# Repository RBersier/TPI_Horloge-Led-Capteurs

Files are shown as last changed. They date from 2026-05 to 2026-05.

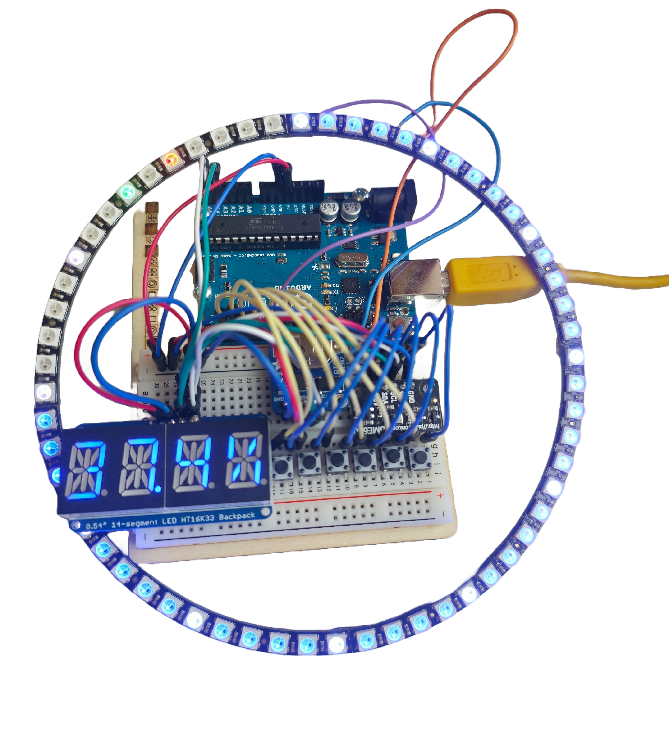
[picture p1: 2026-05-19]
Image/Materiel/Photo_horloge_final.png

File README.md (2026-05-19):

# TPI_Horloge-Led-Capteurs

## Résumé du projet
Ce projet est une horloge murale basée sur Arduino qui combine:
- un affichage analogique de l’heure sur un anneau NeoPixel 60 LEDs,
- un affichage alphanumérique 4x14 segments pour les données environnementales,
- une mesure de l’environnement (température, humidité, pression, gaz/eCO2 estimé),
- un système d’alerte visuelle qualité d’air.

Le système est piloté par un RTC DS1307 pour garder l’heure, et par des boutons physiques pour la configuration et l’utilisation quotidienne.

## Manuel d’installation (depuis zéro)
### 1) Prérequis matériel
- 1x Arduino Uno Rev3
- 1x BME680 (I2C)
- 1x RTC DS1307 (I2C) + pile bouton
- 1x afficheur Adafruit 4x14 segments HT16K33 (I2C)
- 4x quarts NeoPixel 60 (assemblés en 1 ring 60 LEDs) ou 1 anneau équivalent WS2812B
- 6x boutons poussoirs (D2, D3, D4, D5, D7, D8)
- Câbles Dupont, breadboard (ou soudure finale)
- Câble USB A/B pour Arduino Uno

### 2) Prérequis logiciel
- Installer [VS Code](https://code.visualstudio.com/) ou [CLion](https://www.jetbrains.com/clion/)
- Installer l’extension **PlatformIO IDE**
- Installer les drivers Arduino Uno si nécessaire (Windows)

### 3) Récupérer le projet
1. Télécharger/Cloner le dépôt dans un dossier local.
2. Ouvrir le dossier du projet dans VS Code.
3. Ouvrir le sous-dossier `Code` comme projet PlatformIO.

### 4) Vérifier la configuration PlatformIO
Le fichier `Code/platformio.ini` contient les dépendances nécessaires (`lib_deps`), notamment:
- RTClib
- Adafruit BME680 Library
- Adafruit GFX Library
- Adafruit LED Backpack Library
- Adafruit NeoPixel

### 5) Câblage minimal
- **I2C commun** (SDA/SCL) pour DS1307, BME680, HT16K33
- **Ring NeoPixel data** sur `D6`
- **Boutons**:
  - `D2` Menu/Valider
  - `D3` Up
  - `D4` Down
  - `D5` Changer affichage
  - `D7` Luminosité
  - `D8` Désactiver alerte
- Masse (GND) commune sur tous les modules

### 6) Compiler et flasher
1. Brancher l’Arduino en USB.
2. Dans PlatformIO, lancer **Build**.
3. Sélectionner le port série correct (ex: `COM8`).
4. Lancer **Upload**.
5. (Optionnel) Ouvrir le moniteur série à `9600` bauds.

> Si le port ne fonctionne pas: lancer `pio device list` et mettre à jour `monitor_port` dans `Code/platformio.ini`.

### 7) Premier démarrage
- L’afficheur montre le cycle des infos (`eCO2`, `TEMP`, `HUMD`, `ATMO`, `DATE`).
- Le ring affiche l’heure.
- Si `RTC` ou `BME680` est absent, le système l’indique sur l’afficheur.

## Manuel d’utilisation
### A) Rôle de chaque composant
#### Arduino Uno Rev3
- Rôle: microcontrôleur principal.
- Données: centralise toutes les entrées/sorties et exécute la logique.

#### RTC DS1307
- Rôle: conserver l’heure/date même hors tension (avec pile).
- Données fournies: heure, minute, seconde, jour, mois, année.

#### BME680
- Rôle: mesure environnementale.
- Données fournies:
  - Température (`Traw`, `Tcomp` affichée)
  - Humidité relative (%)
  - Pression atmosphérique (hPa)
  - Résistance gaz (Ohm), convertie en `eCO2/PPM~` estimé

#### HT16K33 4x14 segments
- Rôle: affichage texte/valeurs.
- Données affichées:
  - `eCO2` (estimation ppm)
  - `TEMP`
  - `HUMD`
  - `ATMO`
  - `DATE`

#### Anneau NeoPixel 60 LEDs
- Rôle: horloge analogique + alerte visuelle.
- Affichage:
  - Heure en rouge
  - Minute en vert
  - Seconde en bleu cumulatif
  - Couleurs de mélange selon superposition
- Alerte:
  - Ring rouge clignotant rapide si qualité d’air dégradée

#### 6 boutons poussoirs
- Rôle: interface utilisateur locale (navigation/configuration/alertes).

### B) Fonction de chaque bouton
#### D2 — Menu / Valider
- Entre en mode configuration de l’heure/date.
- Cycle de validation des champs:
  - Jour -> Mois -> Heure -> Minute -> Seconde -> retour mode normal.

#### D3 — Up
- Incrémente le champ actif en mode configuration.

#### D4 — Down
- Décrémente le champ actif en mode configuration.

#### D5 — Changer affichage
- Passe manuellement à l’information suivante sur l’afficheur.
- Redémarre le timer de rotation automatique.

#### D7 — Luminosité
- Change la luminosité du ring par paliers:
  - 100% -> 75% -> 50% -> 25% -> 100% ...

#### D8 — Désactiver alerte
- Coupe temporairement l’alerte visuelle rouge.
- L’alerte peut se réarmer automatiquement si la qualité d’air repasse sous seuil puis remonte.

### C) Comportement général
- Rotation automatique des données sur le 14-segments (avec TAG avant valeur).
- Horloge analogique continue sur le ring.
- Alerte visuelle prioritaire sur le ring quand seuil qualité d’air dépassé.
- Réglage date/heure possible sans PC via boutons.

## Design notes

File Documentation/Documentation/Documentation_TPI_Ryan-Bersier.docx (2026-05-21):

TPI : Horloge à LED avec Capteur

Documentation du projet

Figure 1 Photo illustrant l’horloge du projet finie et assemblée en fonctionnement

Chef de projet

Raphael FAVRE

Enseignants aux CPNV en informatique

Experts

Süleyman CERAN

Administrateur Systèmes à UNIL

Alexandre GRAF

CEO de Omicron Web Services SA

Ryan Bersier

SI-C4a – CPNV - 2026

# Table des matières

# 1 Analyse préliminaire

## 1.1 Introduction

Ce projet s'inscrit dans le cadre du Travail de Projet Individuel (TPI) de la formation d'Informaticien CFC (Ordonnance 2021), orientation Exploitation et infrastructure, réalisé au CPNV à Sainte-Croix. Il porte sur la conception et la réalisation d'une horloge murale à LED avec capteurs environnementaux, pilotée par une carte Arduino.

L'idée de départ part d'un constat concret : de nombreuses salles de classe du CPNV sont équipées de petits boîtiers mesurant le taux de CO₂ dans l'air, afin de surveiller la qualité de l'environnement. Ces appareils effectuent leur travail, mais ils souffrent d'un défaut important : ils n'émettent aucune alerte visuelle ou sonore lorsque le taux devient problématique. Résultat, les personnes présentes dans la salle doivent penser à regarder l'appareil régulièrement pour savoir si l'air est encore acceptable ce qui, en pratique, n'arrive pas toujours.

Ce projet vise à pallier ce manque en proposant un appareil qui combine deux fonctions en une : d'un côté, une horloge murale affichant l'heure en temps réel grâce à un anneau de LED NeoPixel animé, et de l'autre, un système de surveillance environnementale affichant en continu la température, l'humidité, la pression atmosphérique et la qualité de l'air (COV) sur un écran alphanumérique. Dès que la qualité de l'air se dégrade, l'anneau LED change de comportement pour émettre une alerte visuelle immédiate et impossible à ignorer.

L'appareil repose sur plusieurs composants matériels mis à disposition : une carte Arduino REV3, quatre anneaux Adafruit NeoPixel formant un cercle de 60 LED, un capteur environnemental BME680, un module d'horloge temps réel RTC DS1307 garantissant la précision de l'heure même en cas de coupure de courant, un affichage Adafruit 4×14 segments, ainsi que six boutons poussoirs permettant à l'utilisateur de régler l'heure, d'ajuster la luminosité et de changer le mode d'affichage.

Ce projet représente une réelle opportunité d'apprentissage dans le domaine des systèmes embarqués, en combinant des aspects de programmation bas niveau, de câblage électronique, de gestion de capteurs et de conception d'une interface utilisateur simple mais efficace. Il s'appuie sur des compétences acquises notamment dans les modules INI-03, MA-20, 319, ainsi que sur le projet Système Embarqué en Arduino déjà réalisé en formation.

Aucun travail préliminaire spécifique à ce projet n'avait été effectué avant le début du TPI. L'intégralité de la conception, du câblage et du développement est réalisée durant la période du 23 avril au 21 mai 2026, dans les locaux du CPNV.

## 1.2 Objectifs

### 1.2.1 Objectifs du projet

Les objectifs suivants ont été définis sur la base du cahier des charges. Chacun d'eux devra pouvoir être vérifié et validé à la fin du projet, que ce soit par démonstration directe, par les résultats des tests ou par la lecture du rapport.

#### 1.2.1.1 Objectif 1 Affichage de l'heure en temps réel

L'horloge doit afficher l'heure courante (heures, minutes, secondes) de manière fluide et lisible sur l'anneau de 60 LED NeoPixel, composé de quatre quarts d'anneau assemblés. L'affichage doit rester correct même après une coupure de courant, grâce au module RTC DS1307.

#### 1.2.1.2 Objectif 2 Mesure et affichage des données environnementales

Le système doit lire en continu les données du capteur BME680 température, humidité, pression atmosphérique et qualité de l'air (COV) et les afficher de manière alternée et claire sur l'écran alphanumérique 4×14 segments.

#### 1.2.1.3 Objectif 3 Alerte visuelle en cas de mauvaise qualité de l'air

Lorsque le niveau de COV dépasse un seuil défini, l'anneau de LED doit réagir visuellement de façon distincte (changement de couleur, clignotement) afin d'alerter immédiatement les personnes présentes dans la salle, sans qu'elles aient besoin de regarder l'écran.

#### 1.2.1.4 Objectif 4 Interaction utilisateur via les boutons poussoirs

Les six boutons poussoirs doivent permettre à l'utilisateur de régler manuellement l'heure, de changer le mode d'affichage de l'écran alphanumérique et d'ajuster la luminosité des LED, avec une gestion correcte du rebond (debounce).

#### 1.2.1.5 Objectif 5 Qualité et maintenabilité du code

Le code Arduino doit être structuré en modules distincts (gestion RTC, NeoPixel, BME680, HT16K33, boutons), commenté et versionné sur un dépôt GitHub mis à jour quotidiennement.

#### 1.2.1.6 Objectif 6 Documentation complète

Un rapport de projet complet, un journal de travail, une procédure d'installation et de mise en service, ainsi qu'une archive du projet doit être livrés dans les délais définis par le cahier des charges.

### 1.2.2 Objectif personnel

#### 1.2.2.1 Me dépasser sur un projet complet

C'est la première fois que je gère un projet de cette ampleur seul, du début à la fin. Je veux prouver surtout à moi-même que j'en suis capable.

#### 1.2.2.2 Progresser autant sur le plan technique qu'humain

Gérer mon stress, respecter mes délais, prendre des décisions seul quand ça coince ce sont des compétences que je veux autant développer que la programmation ou le câblage.

#### 1.2.2.3 Apprendre à résoudre des problèmes inconnus

Ce projet va forcément me mettre face à des situations nouvelles. Mon objectif est d'apprendre à chercher, tester et trouver par moi-même.

#### 1.2.2.4 Mieux gérer mon temps et ma planification

J'ai tendance à sous-estimer certaines tâches. Ce TPI est une occasion concrète d'apprendre à planifier de façon réaliste et à ajuster quand les choses ne se passent pas comme prévu.

#### 1.2.2.5 Comprendre et maîtriser le protocole I²C

Je veux vraiment comprendre comment plusieurs composants cohabitent sur le même bus, comment détecter les conflits d'adresses et comment diagnostiquer un problème de communication pas juste utiliser des bibliothèques sans savoir ce qu'il se passe dessous.

#### 1.2.2.6 Écrire un code structuré et modulaire

Je veux organiser mon code en modules séparés et indépendants, avec des fonctions claires et des commentaires utiles comme le ferait un développeur professionnel sur un vrai projet embarqué.

#### 1.2.2.7 Maîtriser la brasure et le câblage électronique

C'est la partie qui m'inquiète le plus et donc celle où je veux le plus progresser. Je veux sortir de ce projet à l'aise avec le fer à souder et capable de monter un circuit proprement.

#### 1.2.2.8 Créer quelque chose de concret et utile

Ce qui me motive profondément c'est de produire un objet réel qui fonctionne et qui a du sens pas juste un exercice scolaire qu'on oublie le lendemain.

#### 1.2.2.9 Apprendre à utiliser Git de façon rigoureuse

Commiter régulièrement, écrire des messages de commit clairs, garder un historique propre je veux prendre de vraies bonnes habitudes de versioning que je garderai toute ma carrière.

#### 1.2.2.10 Apprendre à documenter mon travail au fil de l'eau

Plutôt que de tout rédiger en catastrophe à la fin, je veux prendre l'habitude d'écrire au fur et à mesure une discipline que je veux garder bien après ce TPI.

#### 1.2.2.11 Comprendre la gestion du temps réel sans système d'exploitation

Gérer plusieurs tâches simultanées sur Arduino sans bloquer l'exécution avec des delay() est un vrai défi. Je veux maîtriser la logique non-bloquante avec millis() et comprendre comment prioriser les tâches sur un seul cœur.

#### 1.2.2.12 Gagner en autonomie et en confiance

Chaque problème résolu seul, chaque décision technique assumée je veux que ce projet me rende plus confiant dans mes capacités pour la suite de ma carrière.

#### 1.2.2.13 Soigner les détails jusqu'au bout

Pas seulement que ça fonctionne, mais que le câblage soit propre, le code lisible et le rapport honnête. Je veux pouvoir regarder le résultat final et me dire que j'ai vraiment donné le meilleur de moi-même.

#### 1.2.2.14 Profiter de cette expérience unique

Un TPI ne se fait qu'une fois. Au-delà des notes et des évaluations, je veux vivre ce projet comme une vraie expérience professionnelle dont je me souviendrai.

## 1.3 Analyse des besoins matériels et logiciels

### 1.3.1 Besoins matériels

#### 1.3.1.1 Carte Arduino REV3

La carte Arduino REV3 constitue le cœur du projet. C'est elle qui orchestre l'ensemble du système : elle lit les données des capteurs, calcule l'affichage de l'heure, pilote les LED et réagit aux actions de l'utilisateur sur les boutons. Elle communique avec les différents composants via les protocoles I²C et les broches numériques/analogiques disponibles.

Figure 2 Photo de l’Arduino et de sa Breadboard prise à la main

#### 1.3.1.2 Anneaux Adafruit NeoPixel 1/4 60 LED au total x4

Ces quatre quarts d'anneau, assemblés pour former un cercle complet de 60 LED RGB, constituent l'affichage principal de l'horloge. Chaque LED est adressable individuellement, ce qui permet de créer des animations fluides pour représenter les heures, les minutes et les secondes, mais aussi de changer l'apparence de l'anneau en cas d'alerte environnementale. Leur pilotage se fait via une seule broche de données et la bibliothèque Adafruit NeoPixel.

Figure 3 Photo des 4 quart de l’anneau de LED avec le dernier quart retourné pour bien pouvoir voir les connexions

#### 1.3.1.3 Capteur environnemental BME680

Ce capteur multifonction est capable de mesurer simultanément la température ambiante, l'humidité relative, la pression atmosphérique et la qualité de l'air via un indice de composés organiques volatils (COV). Il communique avec l'Arduino via le bus I²C et constitue la source de toutes les données environnementales affichées et surveillées par le système.

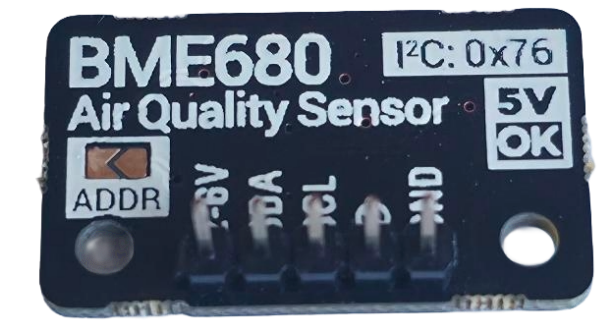
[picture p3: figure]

Figure 4 Photo du capteur environnemental

#### 1.3.1.4 Module horloge temps réel RTC DS1307

Le module RTC DS1307 est une horloge temps réel qui maintient l'heure exacte de manière autonome, même en cas de coupure de courant, grâce à une pile de sauvegarde intégrée. Il communique également via I²C et garantit que l'horloge affichée reste toujours précise, sans dérive, tout au long de l'utilisation de l'appareil.

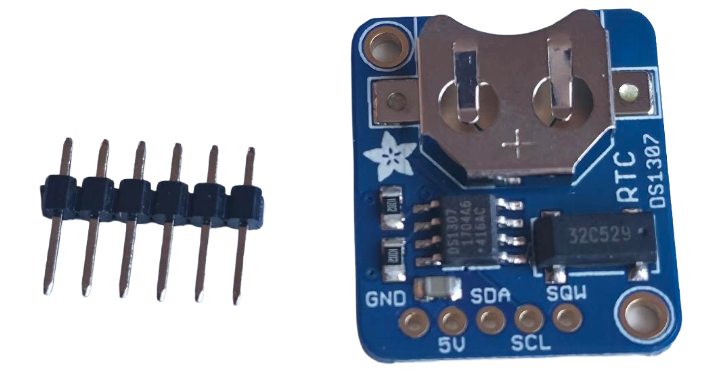
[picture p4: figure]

Figure 5 Photo du Module horloge pour garder la date et l’heure en mémoire

#### 1.3.1.5 Affichage Adafruit 4×14 segments alphanumérique HT16K33

Cet affichage alphanumérique, basé sur le contrôleur HT16K33 et pilotable en I²C, permet d'afficher du texte et des chiffres. Il est utilisé pour présenter en alternance les différentes mesures environnementales (température, humidité, pression, qualité de l'air) de façon lisible et compacte.

Figure 6 Photo de l’affichage 14 segment pas encore assembler

#### 1.3.1.6 Boutons poussoirs x6

Les six boutons permettent à l'utilisateur d'interagir directement avec le système. Ils servent à régler manuellement l'heure, à changer le mode d'affichage de l'écran alphanumérique, et à ajuster la luminosité des LED. Une gestion du rebond (debounce) devra être implémentée pour garantir un comportement fiable à chaque pression.

Figure 7 Photo des 6 boutons pour le projet

#### 1.3.1.7 Poste de brasure et composants électroniques associés

Le projet nécessite un travail de câblage et de brasure pour assembler les différents composants de manière solide et durable. Des résistances, condensateurs, fils de connexion et une breadboard sont mis à disposition pour réaliser le montage électronique.

#### 1.3.1.8 Cable USB-B 2.0 vers USB-A 2.0

Ce câble est indispensable pour connecter la carte Arduino à l'ordinateur. Il sert à la fois à alimenter la carte durant le développement et à téléverser le programme compilé depuis CLion/PlatformIO directement sur le microcontrôleur. Sans ce câble, aucun transfert de code n'est possible entre l'environnement de développement et la carte.

Figure 8 Photo câble fourni USB-a vers USB-b

#### 1.3.1.9 Cable de connexion pin a pin mâle

Ces fils de connexion, aussi appelés jumpers, sont utilisés pour relier les différents composants électroniques entre eux sur la breadboard et vers les broches de l'Arduino. Ils permettent de créer le câblage de manière propre, flexible et modifiable sans brasure, ce qui est particulièrement utile durant la phase de prototypage et de tests.

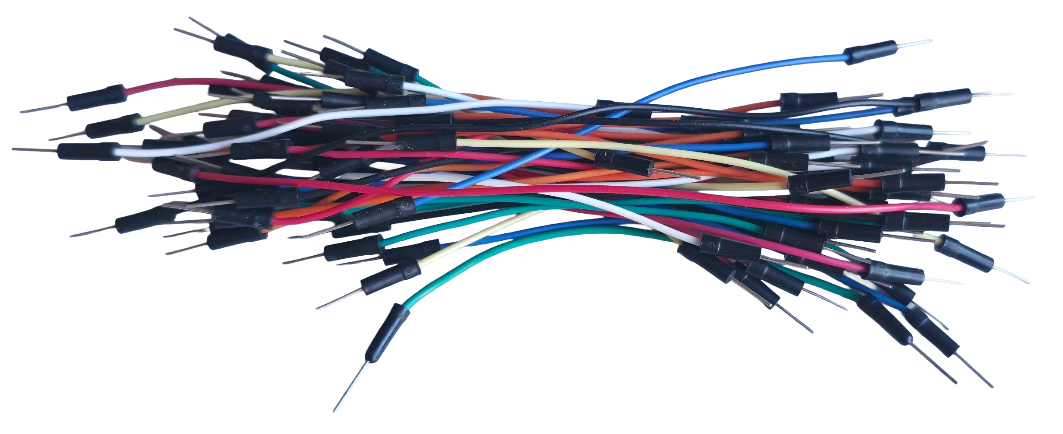
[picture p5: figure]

Figure 9 photo de câble de connexion pin a pin mâle en pagaille

#### 1.3.1.10 Ordinateur du CPNV

L'ordinateur mis à disposition par le CPNV constitue la station de travail principale pour l'ensemble du projet. Il héberge l'environnement de développement CLion avec PlatformIO, les outils de versioning Git, la suite Microsoft Office pour la rédaction des documents, ainsi que tous les fichiers du projet. C'est depuis cet ordinateur que le code est écrit, compilé et téléversé sur la carte Arduino tout au long de la période de réalisation.

Figure 10 PC fourni par le CPNV OptiPlex 7000 DELL

### 1.3.2 Besoins logiciels

#### 1.3.2.1 CLion avec l'extension PlatformIO

Pour le développement du code embarqué, j'ai choisi d'utiliser CLion, l'IDE de JetBrains, couplé à l'extension PlatformIO. Ce choix s'écarte de l'IDE Arduino classique, mais offre des avantages significatifs pour un projet de cette envergure : un éditeur de code puissant avec autocomplétions intelligente, une gestion propre des bibliothèques via PlatformIO, un débogage facilité, et une meilleure organisation du projet en fichiers et modules distincts. PlatformIO prend en charge nativement les cartes Arduino et gère automatiquement les dépendances, ce qui simplifie l'intégration des bibliothèques tierces.

Figure 11 Image du logo de CLion et du logo de son plugin PlatformIO

#### 1.3.2.2 Bibliothèque Adafruit NeoPixel

Cette bibliothèque officielle d'Adafruit est indispensable pour piloter les anneaux LED. Elle permet de contrôler chaque LED individuellement, de définir des couleurs en RGB et de créer des animations. Elle sera intégrée au projet via le gestionnaire de bibliothèques de PlatformIO.

#### 1.3.2.3 Bibliothèque Adafruit BME680

La bibliothèque Adafruit pour le capteur BME680 fournit une interface simple et fiable pour lire toutes les données du capteur (température, humidité, pression, COV) sans avoir à gérer manuellement les registres I²C de bas niveau.

#### 1.3.2.4 Bibliothèque RTClib

La bibliothèque RTClib, développée par Adafruit, facilite la communication avec le module RTC DS1307. Elle permet de lire et d'écrire l'heure courante de façon claire, et d'effectuer des conversions de dates et d'heures sans complexité inutile.

#### 1.3.2.5 Bibliothèque Adafruit LED Backpack / GFX

Ces bibliothèques permettent de piloter l'affichage alphanumérique HT16K33 via I²C. Elles offrent des fonctions simples pour écrire du texte ou des valeurs numériques sur les segments, ce qui rend l'affichage des données environnementales straight forward à implémenter.

#### 1.3.2.6 Git et GitHub

L'ensemble du code source sera versionné avec Git et publié sur un dépôt GitHub mis à jour quotidiennement, conformément aux exigences du cahier des charges. Cela garantit un suivi précis de l'évolution du projet, permet de revenir à une version antérieure en cas de problème, et constitue une archive complète du travail effectué.

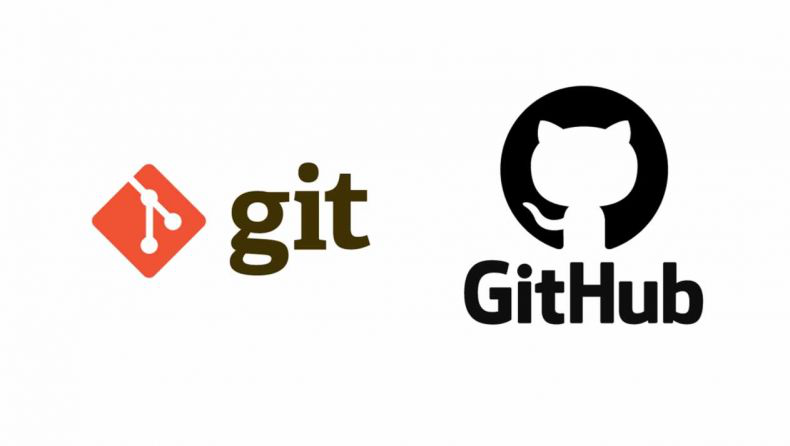
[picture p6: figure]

Figure 12 Image du logo de git et de GitHub

#### 1.3.2.7 Suite Microsoft Office

Microsoft Word sera utilisé pour la rédaction du rapport de projet et du journal de travail, conformément aux livrables attendus. Microsoft PowerPoint pourra être utilisé pour préparer la présentation orale prévue les 2 ou 3 juin 2026.

Figure 13 Image du logo de Microsoft Office

#### 1.3.2.8 Draw.io

draw.io sera utilisé pour la conception des diagrammes de flux du projet. Cet outil permettra de modéliser de manière claire et structurée les différents processus, en facilitant la compréhension globale du fonctionnement du système ainsi que la communication technique dans la documentation.

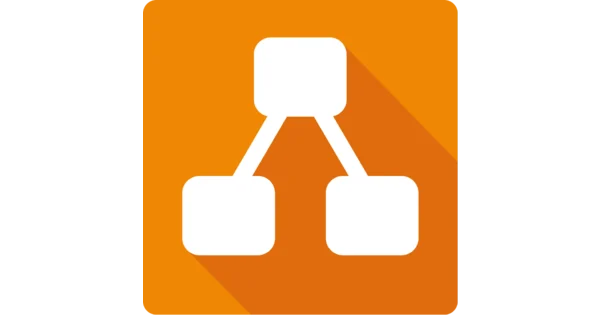
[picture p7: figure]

Figure 14 Image du logo de Draw.io

#### 1.3.2.9 Davinci Resolve

DaVinci Resolve sera utilisé pour le montage de la vidéo de démonstration du projet. Il permettra d’assembler les séquences capturées, d’effectuer les éventuels ajustements audio et visuels, ainsi que d’assurer un rendu final cohérent et professionnel conforme aux exigences de présentation.

Figure 15 Image du logo de Davinci Resolve

## 1.4 Analyse des risques

### 1.4.1 Risque 1

Erreur de câblage ou de brasure

Niveau de risque : Élevé

C'est le risque qui m'inquiète le plus dans ce projet. Le montage implique de nombreux composants reliés entre eux via des câbles, des broches et des points de brasure. Une erreur de câblage comme inverser l'alimentation et la masse (GND/VCC) ou une mauvaise brasure comme un faux contact ou un court-circuit peut endommager irrémédiablement un composant, voire la carte Arduino elle-même.

Mesures préventives :

Avant chaque branchement, je vérifierai systématiquement le schéma de câblage. Je procéderai composant par composant, en testant le bon fonctionnement de chacun avant de passer au suivant. Pour la brasure, je m'assurerai que les joints sont propres, brillants et bien formés, et j'utiliserai un multimètre pour vérifier la continuité électrique et l'absence de court-circuit avant toute mise sous tension.

### 1.4.2 Risque 2

Composant défectueux ou endommagé

Niveau de risque : Moyen

Malgré toutes les précautions prises, un composant peut s'avérer défectueux dès le départ ou être endommagé lors du montage (surchauffe à la brasure, électricité statique, mauvaise manipulation). Si un module clé comme le BME680 ou le RTC ne fonctionne pas, cela peut bloquer une partie importante du développement.

Mesures préventives :

Je testerai chaque composant individuellement dès son branchement, à l'aide de programmes de test simples, avant de les intégrer dans le projet global. En cas de panne avérée, j'en informerai immédiatement mon chef de projet afin d'obtenir un composant de remplacement dans les meilleurs délais.

### 1.4.3 Risque 3

Conflit ou incompatibilité entre les bibliothèques

Niveau de risque : Moyen

Le projet utilise plusieurs bibliothèques tierces simultanément : Adafruit NeoPixel, Adafruit BME680, RTClib et Adafruit LED Backpack. Il est possible que certaines versions de ces bibliothèques entrent en conflit, consomment trop de mémoire RAM ou Flash sur l'Arduino, ou provoquent des comportements inattendus lorsqu'elles sont utilisées ensemble.

Mesures préventives :

J'intégrerai les bibliothèques progressivement, en testant la compatibilité à chaque ajout. Je consulterai la documentation officielle d'Adafruit et les issues GitHub des bibliothèques concernées pour m'assurer d'utiliser des versions stables et compatibles. En cas de problème de mémoire, j'optimiserai le code en réduisant l'utilisation des variables globales et en privilégiant les types de données les plus légers.

### 1.4.4 Risque 4

Dépassement du budget temps

Niveau de risque : Moyen

Avec 90 heures disponibles et un projet qui touche à la fois au matériel et au logiciel, le risque de prendre du retard est réel. Certaines tâches peuvent s'avérer plus longues que prévu notamment le débogage, l'intégration des modules ou la rédaction du rapport et empiéter sur les étapes suivantes.

Mesures préventives :

Je suivrai rigoureusement ma planification initiale et mettrai à jour mon journal de travail quotidiennement pour détecter tout écart rapidement. Si une tâche prend trop de temps, je l'évaluerai et déciderai si je peux la simplifier ou la reporter, en priorisant toujours les fonctionnalités essentielles (affichage de l'heure, lecture des capteurs) avant les fonctionnalités secondaires (animations, modes d'affichage avancés).

### 1.4.5 Risque 5

Problème de communication I²C entre les composants

Niveau de risque : Moyen

Trois composants du projet (BME680, RTC DS1307 et HT16K33) communiquent tous via le bus I²C. Si deux composants partagent la même adresse I²C ou si le bus est mal configuré, les communications peuvent échouer ou se mélanger, rendant les données illisibles.

Mesures préventives :

Je vérifierai en amont les adresses I²C de chaque composant et m'assurerai qu'elles sont toutes différentes. J'utiliserai un scanner I²C (programme Arduino simple) pour détecter tous les appareils connectés sur le bus et confirmer qu'ils sont bien reconnus avant d'aller plus loin dans le développement.

### 1.4.6 Risque 6

Perte de données ou corruption du code source

Niveau de risque : Faible

Une panne informatique, une fausse manipulation ou un problème de synchronisation pourrait entraîner la perte d'une partie du code ou des documents rédigés, avec un impact potentiellement important sur l'avancement du projet.

Mesures préventives :

Le code sera versionné et poussé sur GitHub quotidiennement, conformément aux exigences du cahier des charges. Les documents seront sauvegardés régulièrement sur le réseau du CPNV. Ces deux pratiques combinées réduisent ce risque à un niveau très faible.

### 1.4.7 Risque 7

Difficultés avec l'environnement CLion / PlatformIO

Niveau de risque : Faible

CLion couplé à PlatformIO est un environnement plus avancé que l'IDE Arduino standard. Une configuration incorrecte, un problème de détection du port série ou une mise à jour inattendue pourrait ralentir le démarrage du développement.

Mesures préventives :

Je consacrerai le temps nécessaire à la mise en place et à la vérification de l'environnement de développement dès le premier jour, avant toute autre tâche de programmation. Si des difficultés persistantes apparaissent, je pourrai me rabattre temporairement sur l'IDE Arduino classique pour ne pas bloquer l'avancement, puis revenir à CLion une fois le problème résolu.

## 1.5 Planification initiale

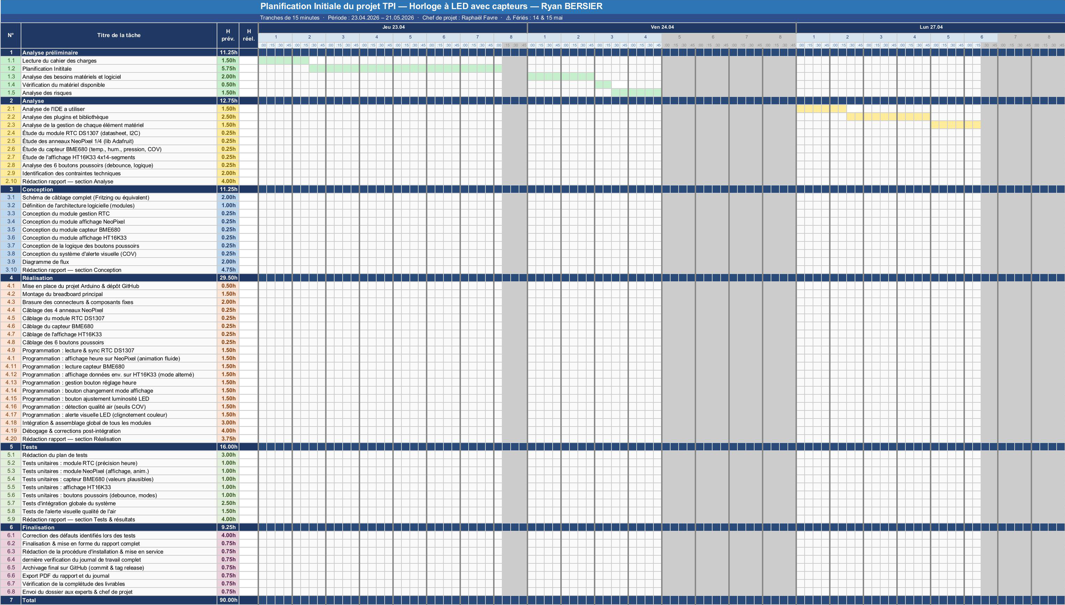
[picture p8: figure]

Figure 16 planning initial partie 1

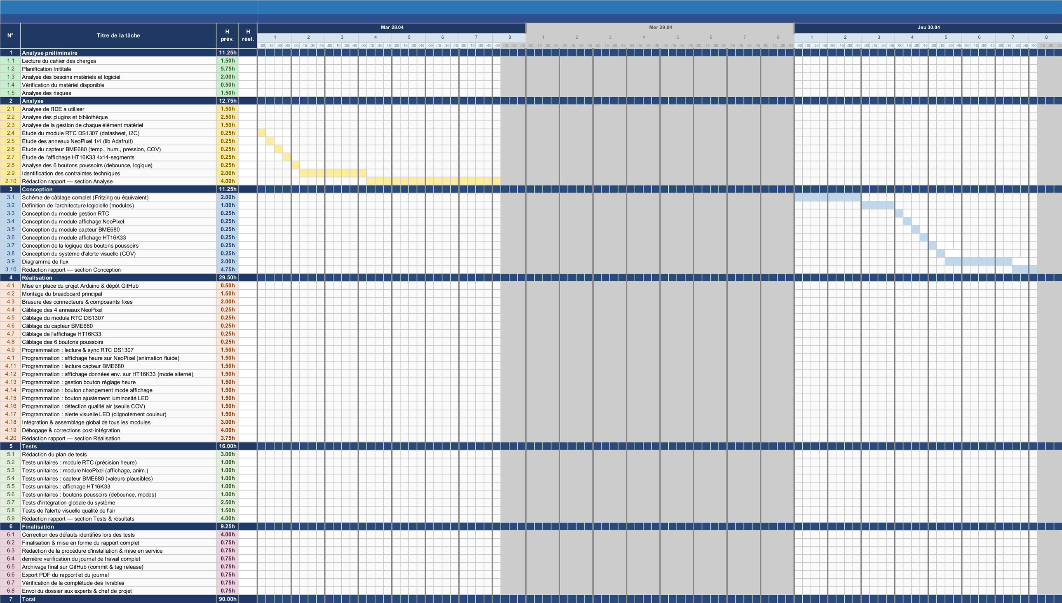
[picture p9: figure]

Figure 17 planning initial partie 2

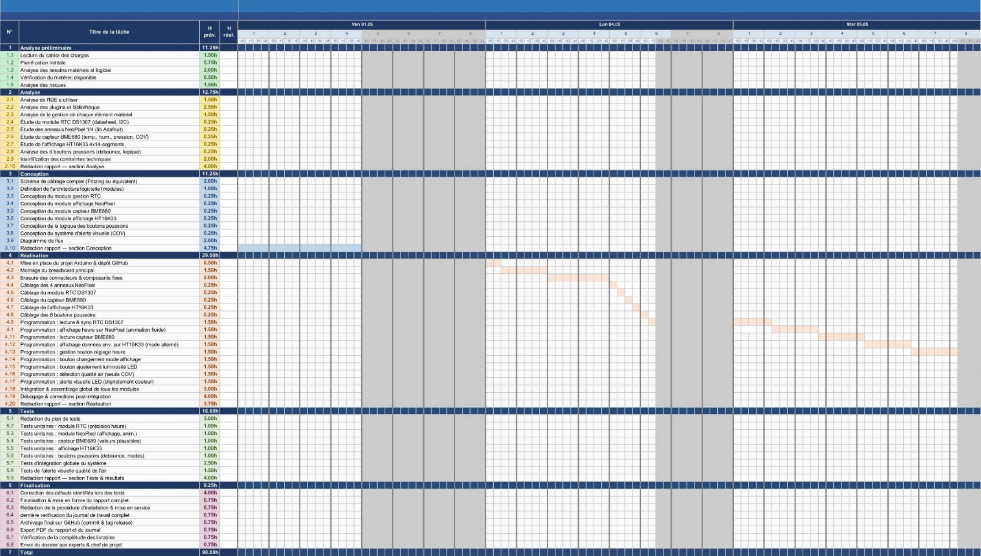
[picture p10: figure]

Figure 18 planning initial partie 3

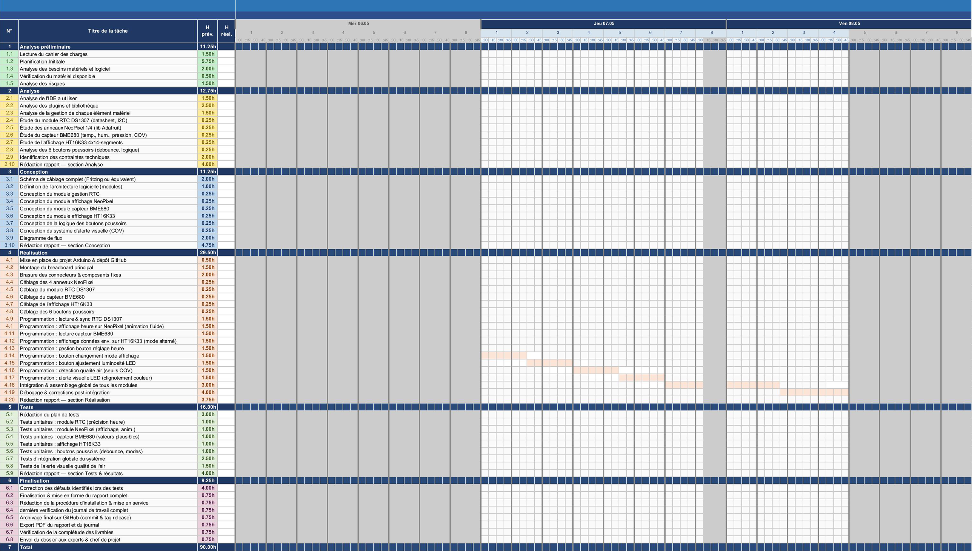
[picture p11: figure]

Figure 19 planning initial partie 4

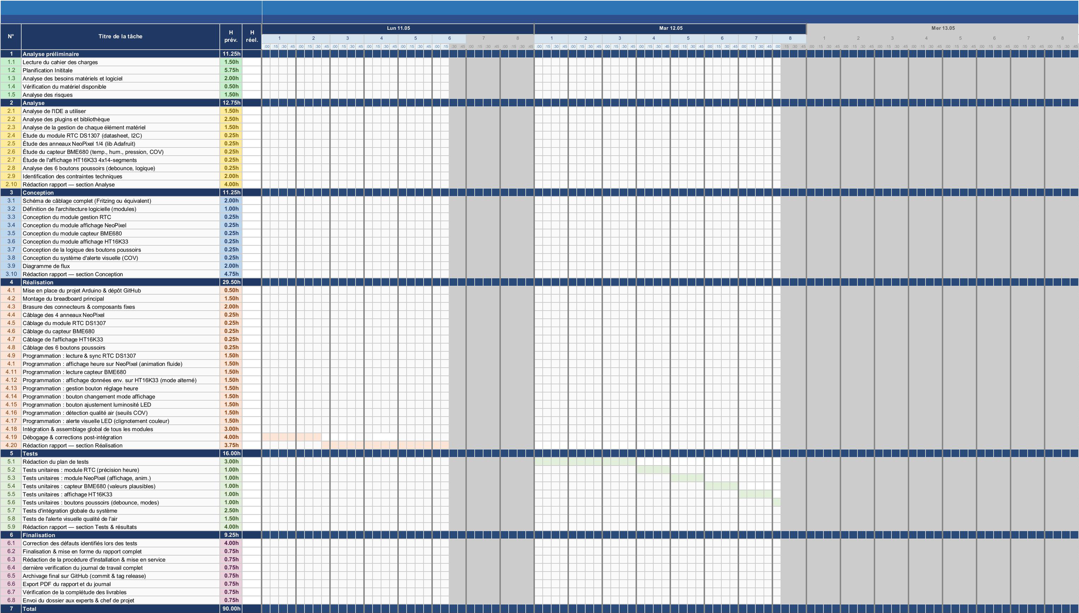
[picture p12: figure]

Figure 20 planning initial partie 5

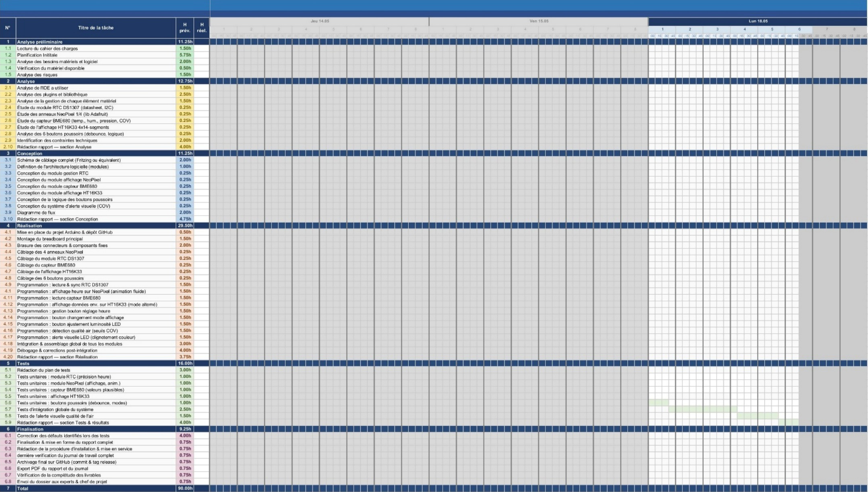
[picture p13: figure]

Figure 21 planning initial partie 6

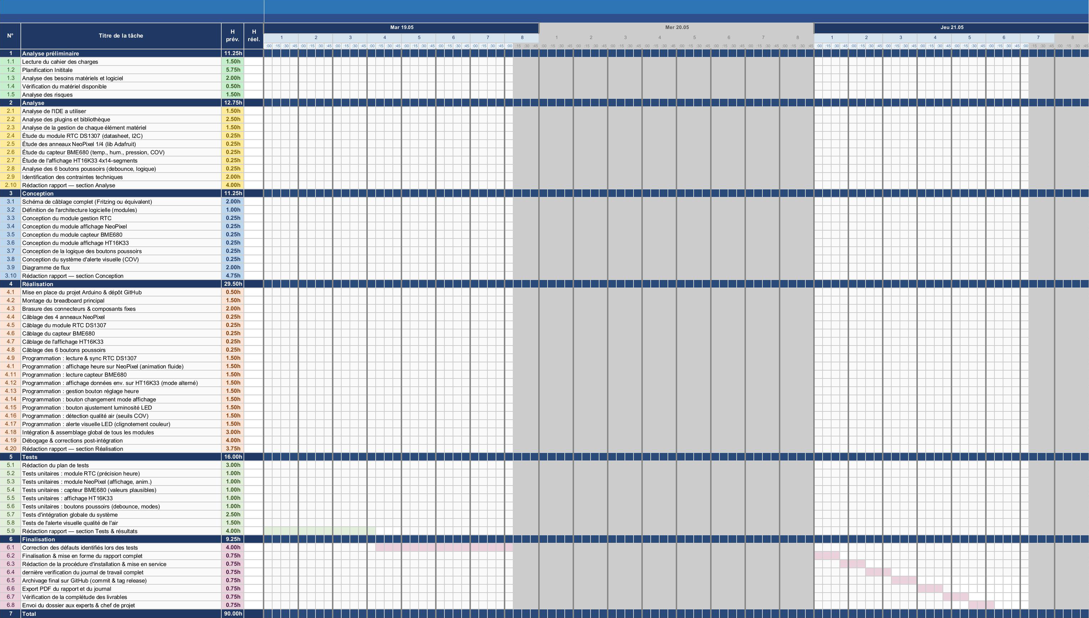
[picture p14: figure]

Figure 22 planning initial partie 7

# 2 Analyse

## 2.1 Justification choix de l’IDE

Critère | Arduino IDE | Visual Studio Code | CLion + PlatformIO
Autocomplétions | Très basique, peu fiable | Bonne via extension C/C++ | Excellente, moteur JetBrains (très précis sur le code embarqué)
Navigation dans le code | Absente | Correcte | Avancée aller à la définition, recherche de références, refactoring
Gestion des bibliothèques | Manuelle via gestionnaire basique | Via PlatformIO (si installé) | Via PlatformIO intégré nativement gestion des dépendances automatique
Structure du projet | Fichier unique .ino difficile à organiser | Multi-fichiers possible | Multi-fichiers et multi-modules natif, idéal pour séparer les composants
Débogage | Aucun débogage réel | Limité | Débogage avancé intégré (break points, inspection de variables)
Intégration Git | Absente | Basique via extension | Native et complète dans l'IDE
Détection d'erreurs | À la compilation seulement | Partielle en temps réel | En temps réel, avec suggestions de correction immédiates
Support I²C / librairies Adafruit | Oui | Oui via PlatformIO | Oui PlatformIO gère toutes les libs Adafruit sans configuration manuelle
Qualité de l'interface | Très simple, peu ergonomique | Bonne mais nécessite beaucoup de configuration | Professionnelle, tout est prêt à l'emploi sans configuration complexe
Adapté aux projets modulaires | Non | Partiellement | Oui conçu pour les projets découpés en modules/fichiers
Familiarité personnelle | Connue mais limitante | Connue mais légère pour l’embarquer | Choisie pour monter en compétence sur un outil professionnel

## 2.2 Analyse des éléments électronique

L'analyse comparative présentée dans les sections suivantes s'inscrit dans un contexte purement hypothétique. Dans la réalité, l'ensemble du matériel utilisé dans ce projet est fourni par le CPNV et ne fait l'objet d'aucun choix de ma part. Cependant, afin de démontrer ma capacité à évaluer et justifier des choix techniques, j'ai imaginé un scénario dans lequel je serais libre de sélectionner chaque composant moi-même, avec un budget plus conséquent permettant d'envisager des alternatives parfois plus coûteuses que celles mises à disposition. Les justifications apportées sont donc purement techniques et ne reflètent en aucun cas une critique du matériel fourni, qui reste tout à fait adapté à la réalisation de ce projet.

### 2.2.1 Carte Arduino UNO REV3

#### 2.2.1.1 Rôle dans le projet

La carte Arduino UNO REV3 est le microcontrôleur central du projet. Elle exécute le programme principal en temps réel : elle interroge le module RTC pour connaître l'heure, calcule la position des LED à allumer sur l'anneau NeoPixel, lit les valeurs du capteur BME680, envoie les données à afficher sur l'écran HT16K33, et surveille en permanence l'état des six boutons poussoirs. Toute la logique du système repose sur elle.

#### 2.2.1.2 Alternative: Raspberry Pi Pico (RP2040)

Le Raspberry Pi Pico est un microcontrôleur moderne basé sur le chip RP2040, dual-core à 133 MHz, avec 264 Ko de RAM et un support natif du MicroPython et du C/C++. Il est nettement plus puissant que l'Arduino UNO, dispose de deux cœurs permettant de paralléliser les tâches, et intègre du matériel PIO (Programmable I/O) idéal pour piloter des LED NeoPixel sans surcharger le processeur.

#### 2.2.1.3 Meilleur choix : Raspberry Pi Pico

Dans un monde où l'on choisit librement ses composants, le Raspberry Pi Pico serait le meilleur choix. Sa puissance de calcul supérieure permettrait de gérer plus facilement les animations LED fluides, la lecture des capteurs et la gestion des boutons simultanément, sans risquer de saturer le processeur. L'Arduino UNO REV3 reste un excellent outil pédagogique, mais ses 2 Ko de RAM et son unique cœur à 16 MHz montrent leurs limites sur un projet aussi multifonction.

### 2.2.2 Anneaux Adafruit NeoPixel 1/4 60 LED au total (×4)

#### 2.2.2.1 Rôle dans le projet

Les quatre quarts d'anneau NeoPixel forment, une fois assemblés, un cercle complet de 60 LED RGB adressables individuellement. Dans ce projet, ils servent d'affichage principal de l'horloge : les LED représentent visuellement les heures, les minutes et les secondes par des animations lumineuses. Ils jouent également le rôle d'indicateur d'alerte environnementale en changeant de couleur ou de comportement lorsque la qualité de l'air se dégrade. Un seul fil de données suffit pour piloter l'ensemble des 60 LED en cascade.

#### 2.2.2.2 Alternative : Anneau LED WS2812B (60 LED d'un seul tenant)

Il existe des anneaux LED complets de 60 LED WS2812B (la puce utilisée dans les NeoPixel) en un seul module circulaire. Ils reposent sur le même protocole de communication et sont compatibles avec la bibliothèque Adafruit NeoPixel, mais se présentent sous forme d'un anneau monobloc au lieu de quatre quarts séparés.

#### 2.2.2.3 Meilleur choix : Anneau WS2812B 60 LED monobloc

Un anneau monobloc serait légèrement préférable en termes de montage : il n'y a aucun joint à souder entre les quarts, ce qui élimine les risques de mauvais contact aux jonctions et simplifie l'assemblage mécanique. Sur le plan électronique et logiciel, les deux solutions sont strictement équivalentes. Le choix des quatre quarts Adafruit n'est donc pas le plus optimal mécaniquement, même s'il reste parfaitement fonctionnel.

### 2.2.3 Capteur environnemental BME680

#### 2.2.3.1 Rôle dans le projet

Le BME680 est le capteur qui fournit toutes les données environnementales du système. Il mesure en continu la température ambiante, l'humidité relative, la pression atmosphérique et un indice de qualité de l'air basé sur la détection de composés organiques volatils (COV). Ces quatre valeurs sont ensuite affichées en alternance sur l'écran HT16K33, et le niveau de COV déclenche l'alerte visuelle sur l'anneau LED lorsqu'il dépasse un seuil critique. Il communique avec l'Arduino via le bus I²C.

#### 2.2.3.2 Alternative : Capteur SCD41 (CO₂, température, humidité) de Sensirion

Le SCD41 est un capteur de CO₂ véritable (mesure photo acoustique NDIR), couplé à une mesure de température et d'humidité. Contrairement au BME680 qui estime la qualité de l'air de manière indirecte via les COV, le SCD41 mesure directement la concentration de CO₂ en ppm ce qui est précisément le problème identifié dans le cahier des charges (les boîtiers CO₂ des salles de classe).

#### 2.2.3.3 Meilleur choix : SCD41

Dans le contexte de ce projet, dont l'objectif premier est d'alerter sur la mauvaise qualité de l'air en salle de classe un problème directement lié au CO₂ expiré par les occupants le SCD41 serait techniquement plus pertinent. Il mesure ce qu'on cherche vraiment à surveiller, là où le BME680 donne une estimation indirecte via les COV. Le BME680 a l'avantage de mesurer aussi la pression atmosphérique, mais pour ce cas d'usage précis, la mesure directe du CO₂ par le SCD41 est plus fiable et plus cohérente avec la problématique décrite dans le cahier des charges.

### 2.2.4 Module horloge temps réel RTC DS1307

#### 2.2.4.1 Rôle dans le projet

Le module RTC DS1307 a pour unique but de maintenir l'heure exacte en permanence, indépendamment de l'Arduino. Contrairement à une simple fonction de comptage logiciel dans le microcontrôleur, ce module dispose de son propre oscillateur à quartz et d'une pile de sauvegarde qui lui permet de continuer à compter le temps même lorsque l'appareil est hors tension. À chaque démarrage du système, l'Arduino lit l'heure courante depuis le DS1307 via I²C pour initialiser son affichage.

#### 2.2.4.2 Alternative : Module RTC DS3231

Le DS3231 est l'évolution directe du DS1307. Il intègre un oscillateur à quartz compensé en température (TCXO), ce qui lui confère une précision nettement supérieure : une dérive de ±2 minutes par an contre plusieurs minutes par mois pour le DS1307. Il intègre également un capteur de température interne et reste compatible avec le même protocole I²C et les mêmes bibliothèques.

#### 2.2.4.3 Meilleur choix : DS3231

Le DS3231 est clairement le meilleur choix pour une horloge murale. Une horloge qui dérive de plusieurs minutes par mois perd rapidement sa crédibilité en tant qu'instrument de mesure du temps. Le DS3231, avec sa précision quasi parfaite sur une année entière, garantit que l'heure affichée reste juste sur le long terme sans nécessiter de recalibration fréquente. Pour un projet qui se veut une horloge fiable et autonome, cette précision accrue justifie pleinement le choix du DS3231.

### 2.2.5 Adafruit 4×14 segments alphanumérique HT16K33

#### 2.2.5.1 Rôle dans le projet

L'affichage HT16K33 sert d'écran secondaire textuel pour présenter les données environnementales collectées par le BME680. Il affiche en alternance la température, l'humidité, la pression et l'indice de qualité de l'air sous forme de texte et de chiffres lisibles. Son format 14 segments par digit permet d'afficher non seulement des chiffres mais aussi des lettres, ce qui facilite l'identification de chaque mesure (par exemple afficher "TEMP" avant la valeur). Il communique via I²C, ce qui limite le nombre de broches utilisées sur l'Arduino.

#### 2.2.5.2 Alternative : Petit écran OLED 128×64 pixels (SSD1306)

Un écran OLED monochrome de 0.96 pouce basé sur le contrôleur SSD1306 offre une surface d'affichage en pixels libres, permettant d'afficher du texte de taille variable, des icônes, des graphiques ou plusieurs valeurs simultanément sur le même écran. Il communique également en I²C et consomme très peu d'énergie.

#### 2.2.5.3 Meilleur choix : Écran OLED SSD1306

L'écran OLED serait un meilleur choix dans un projet idéal. Il permet d'afficher toutes les mesures environnementales simultanément sur un seul écran sans avoir recours à l'alternance, d'ajouter des unités claires (°C, %, hPa), de créer une mise en page plus lisible et intuitive, et même d'afficher des indicateurs visuels comme une jauge de qualité de l'air. L'affichage 14 segments reste lisible et élégant, mais il est limité en termes d'information affichable en une seule fois, ce qui oblige à faire défiler les mesures et peut rendre la lecture moins immédiate.

### 2.2.6 Boutons poussoirs (×6)

#### 2.2.6.1 Rôle dans le projet

Les six boutons poussoirs constituent l'interface de contrôle manuelle du système. Ils permettent à l'utilisateur de régler l'heure manuellement sur le module RTC, de faire défiler les différents modes d'affichage sur l'écran alphanumérique, et d'ajuster la luminosité de l'anneau LED. Chaque bouton est relié à une broche numérique de l'Arduino, et une gestion logicielle du rebond (debounce) est nécessaire pour éviter les détections multiples lors d'une seule pression.

#### 2.2.6.2 Alternative : Encodeur rotatif avec bouton intégré (KY-040)

Un encodeur rotatif est un composant qui détecte la rotation dans un sens ou dans l'autre, en plus d'un appui central. Avec un ou deux encodeurs, il serait possible de remplacer plusieurs boutons : tourner pour naviguer entre les valeurs ou les modes, et appuyer pour confirmer ou changer de paramètre. C'est l'interface que l'on retrouve sur la plupart des appareils électroniques modernes (amplificateurs, imprimantes 3D, thermostats).

#### 2.2.6.3 Meilleur choix : Boutons poussoirs classiques

Pour ce projet précis, les boutons poussoirs classiques restent le meilleur choix. Les six fonctions à contrôler (réglage heure, modes d'affichage, luminosité) sont des actions distinctes et indépendantes qui se prêtent bien à des boutons dédiés. L'encodeur rotatif est plus élégant pour naviguer dans un menu, mais introduit une complexité logicielle supplémentaire (gestion de la rotation, de la vitesse, d'un menu structuré) qui n'est pas justifiée pour un nombre aussi limité de paramètres. Des boutons bien étiquetés offrent une interaction plus directe et intuitive dans ce contexte.

## 2.3 Contraintes techniques

### 2.3.1 Contrainte 1

Limitation des ressources du microcontrôleur

L'Arduino UNO REV3 dispose de ressources matérielles très limitées : seulement 2 Ko de RAM, 32 Ko de mémoire Flash et un processeur ATmega328P cadencé à 16 MHz sur un seul cœur. Le projet doit faire cohabiter simultanément la gestion de l'anneau NeoPixel (60 LED), la lecture du capteur BME680, la communication avec le RTC DS1307, l'affichage sur le HT16K33 et la surveillance des six boutons poussoirs. Chaque bibliothèque utilisée consomme une part de cette mémoire limitée, et le code devra être optimisé pour ne pas dépasser les capacités de la carte, sous peine de comportements imprévisibles ou de plantages.

### 2.3.2 Contrainte 2

Partage du bus I²C entre plusieurs composants

Trois composants du projet le BME680, le RTC DS1307 et l'affichage HT16K33 — communiquent tous via le même bus I²C, sur les broches SDA et SCL de l'Arduino. Chaque composant doit donc avoir une adresse I²C unique et bien configurée. Une collision d'adresses ou un problème de câblage sur ce bus unique rendrait plusieurs composants inaccessibles simultanément. Cette contrainte impose une vérification rigoureuse des adresses avant l'intégration et une gestion soigneuse du câblage de ces deux broches partagées.

### 2.3.3 Contrainte 3

Alimentation et consommation électrique

L'ensemble des composants est alimenté via la carte Arduino, elle-même alimentée par le câble USB ou une alimentation externe. L'anneau de 60 LED NeoPixel est le composant le plus gourmand en énergie : à pleine luminosité, chaque LED peut consommer jusqu'à 60 mA, ce qui représente théoriquement jusqu’à 3,6 A pour les 60 LED en blanc pur. Le port USB d'un ordinateur ne fournit généralement que 500 mA. Il sera donc impératif de limiter la luminosité maximale des LED dans le code afin de ne pas dépasser la capacité d'alimentation disponible et éviter tout risque de surchauffe ou de dommage matériel.

### 2.3.4 Contrainte 4

Gestion du temps réel et des priorités d'exécution

L'Arduino exécute le code de manière séquentielle sur un seul cœur, sans système d'exploitation ni gestion native des priorités. Or, le projet nécessite de gérer plusieurs tâches quasi simultanément : mettre à jour l'affichage LED, lire les capteurs, surveiller les boutons et rafraîchir l'écran alphanumérique. L'utilisation de la fonction delay() est donc à proscrire, car elle bloque l'exécution de tout le reste pendant sa durée. Le code devra reposer sur une logique de timing non-bloquante, basée sur millis(), pour que chaque tâche soit exécutée à sa propre fréquence sans bloquer les autres.

### 2.3.5 Contrainte 5

Gestion du rebond des boutons (debounce)

Les boutons poussoirs mécaniques génèrent naturellement des signaux parasites lors d'un appui ou d'un relâchement : le contact rebondit plusieurs fois en quelques millisecondes avant de se stabiliser. Sans traitement, l'Arduino peut interpréter un seul appui comme plusieurs pressions consécutives, rendant l'interaction utilisateur erratique et peu fiable. Une gestion logicielle du debounce devra être implémentée pour chacun des six boutons, en filtrant les changements d'état trop rapprochés dans le temps.

### 2.3.6 Contrainte 6

Précision et dérive de l'horloge

Le module RTC DS1307 utilisé dans ce projet présente une dérive pouvant atteindre plusieurs minutes par mois selon les conditions de température. Pour une horloge murale destinée à être consultée quotidiennement, cette dérive est acceptable à court terme mais peut devenir gênante sur la durée. Le système doit donc prévoir la possibilité pour l'utilisateur de recaler manuellement l'heure via les boutons poussoirs, afin de corriger toute dérive sans nécessiter de reprogrammation de la carte.

### 2.3.7 Contrainte 7

Fiabilité de la mesure environnementale

Le capteur BME680 mesure la qualité de l'air via un indice COV qui nécessite une phase de chauffe et de calibration lors de chaque mise sous tension. Durant les premières minutes de fonctionnement, les valeurs retournées peuvent être instables ou non représentatives de la réalité. Le code devra tenir compte de ce temps de stabilisation et éviter de déclencher de fausses alertes visuelles pendant cette période d'initialisation du capteur.

### 2.3.8 Contrainte 8

Contrainte mécanique et physique du montage

L'assemblage des quatre quarts d'anneau NeoPixel en un cercle complet impose une précision mécanique lors de la brasure des jonctions entre chaque quart. Un mauvais alignement ou une connexion défaillante entre deux quarts peut interrompre la transmission du signal vers les LED situées en aval, rendant une partie de l'anneau non fonctionnelle. Le montage physique du projet dans son ensemble devra être soigné et solide pour garantir un fonctionnement stable dans le temps.

# 3 Conception

## 3.1 Schéma électronique

### 3.1.1 Platine d’essaie

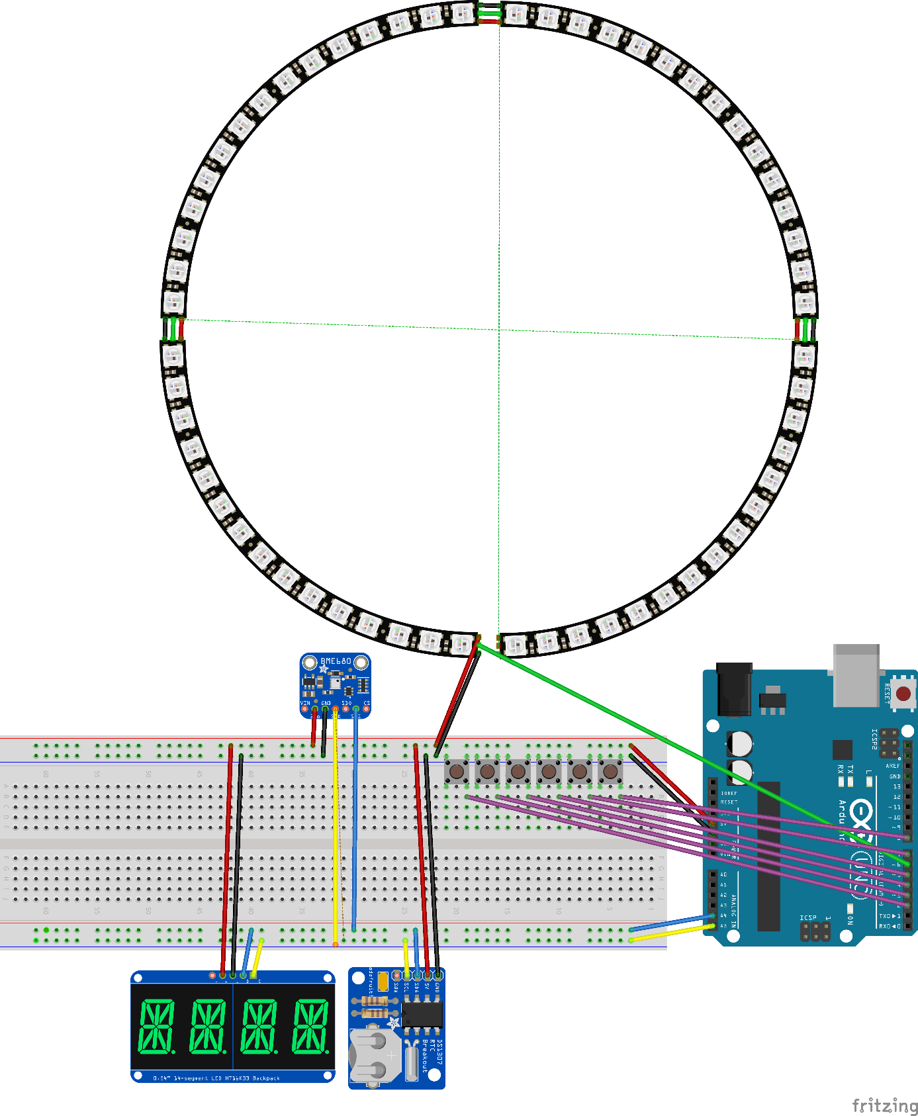
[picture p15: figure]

Figure 23 Platine d’essai du câblage qui provient de Fritzing

### 3.1.2 Schématique du circuit électronique

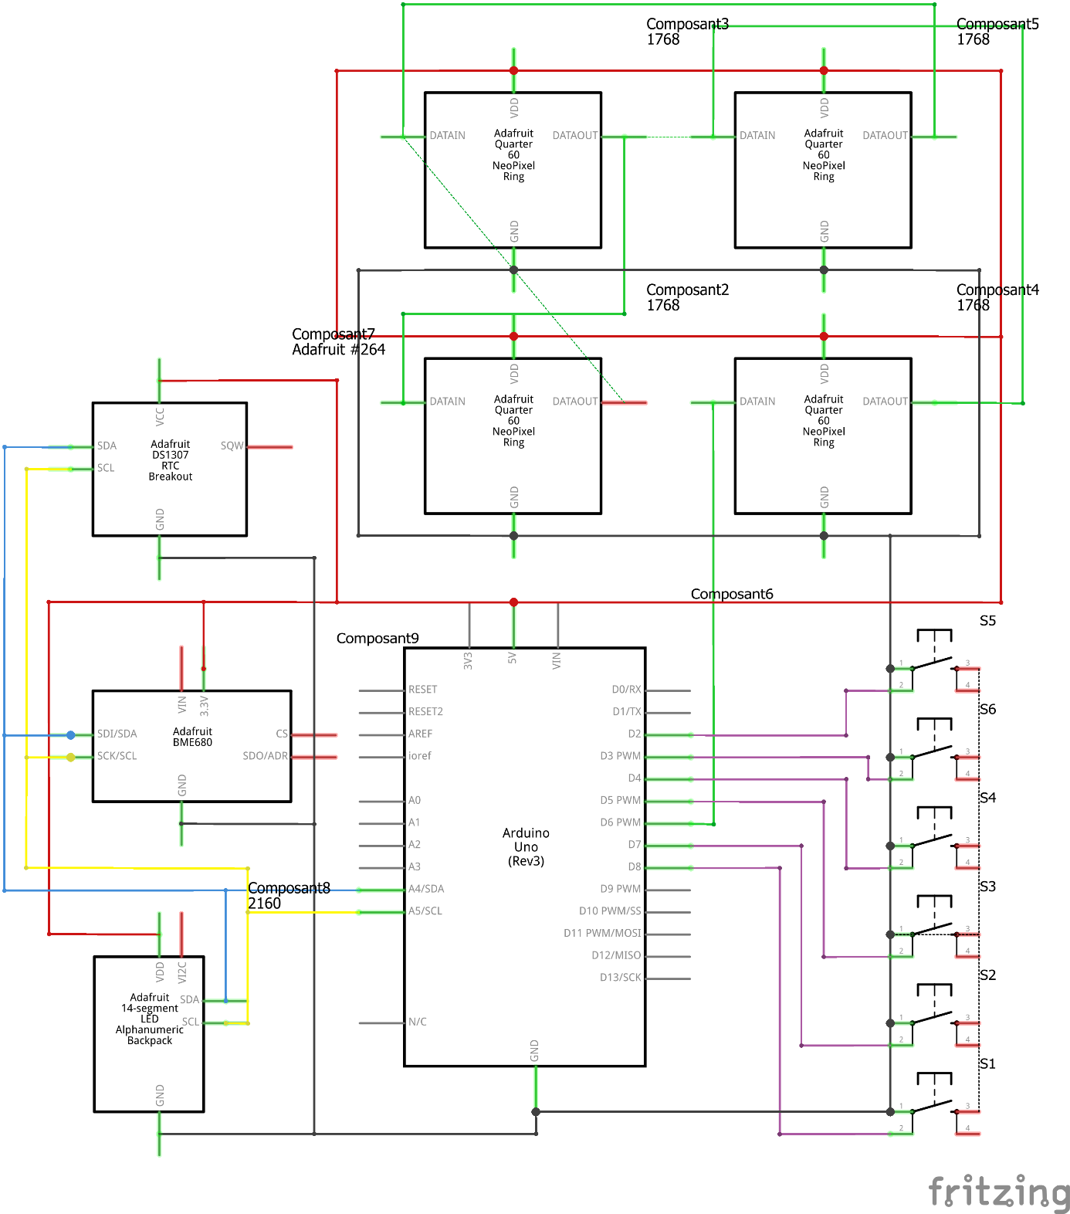
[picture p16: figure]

Figure 24 schématique du circuit électronique fait sur Fritzing

### 3.1.3 Explication normes

Norme utilisée : IEC 60757 "Code de désignation des couleurs", publiée par la Commission Électrotechnique Internationale. C'est le standard international qui définit les abréviations à deux lettres (RD, BK, BU, YE, GN, VT…) et les couleurs associées à chaque rôle dans un câblage électronique.

Bus I²C (BME680 + HT16K33 + DS1307) ces trois composants partagent le même bus, donc les mêmes fils bleu (SDA) et jaune (SCL) se branchent en parallèle sur A4 et A5 de l'Arduino. Un seul fil de chaque couleur suffit par branche.

Boutons poussoirs tous en violet, car ils ont le même rôle fonctionnel (entrée logique discrète). Les distinguer par broche suffit ; utiliser des couleurs différentes par bouton n'apporterait pas d'information et violerait l'esprit de la norme.

NeoPixel Ring le vert est recommandé pour les lignes de données série unipolaires hors bus standard (ni I²C, ni SPI, ni UART). Le fil d'alimentation du ring reste rouge (5V) et noir (GND).

Couleur | Rôle IEC | Code IEC 60757
Rouge | Alimentation + | RD
Noir | Masse / GND | BK
Bleu | SDA (données I²C) | BU
Jaune | SCL (horloge I²C) | YE
Vert | Data série (NeoPixel) | GN
Violet | Entrées numériques | VT

## 3.2 Définition de l’architecture logiciel

L’architecture logicielle du projet est organisée en modules fonctionnels simples, afin de garantir un code lisible, maintenable et facilement testable sur microcontrôleur Arduino.

Le programme repose sur une boucle principale non bloquante (loop) qui orchestre en continu cinq blocs métiers :

### 3.2.1 Acquisition des entrées utilisateur

Les 6 boutons (D2, D3, D4, D5, D7, D8) sont lus avec antirebond logiciel.
Chaque appui génère un événement interprété selon le mode courant (normal ou configuration).

### 3.2.2 Gestion temporelle (RTC DS1307)

Le module RTC fournit l’heure et la date en temps réel. Ces données pilotent :

- L’affichage de l’horloge sur le ring NeoPixel (heures, minutes, secondes),
- Le mode configuration (édition jour/mois/heure/minute/seconde puis écriture RTC).

### 3.2.3 Acquisition environnementale (BME680)

Le capteur BME680 est lu périodiquement (température, humidité, pression, résistance gaz). La température est compensée (Tcomp) par un offset fixe pour corriger l’échauffement capteur. La valeur eCO2/PPM~ est estimée via un modèle logiciel :

- Filtrage du signal gaz,
- Baseline adaptative, (référence air propre)
- Conversion non linéaire,
- Compensation légère température/humidité.

### 3.2.4 Gestion d’affichage (HT16K33 14 segments)

En mode normal, les informations s’affichent en rotation automatique toutes les 10 s : eCO2 -> TEMP -> HUMD -> ATMO -> DATE.

Un TAG est affiché avant chaque valeur pour améliorer la lisibilité. En mode configuration, l’affichage bascule sur le champ en cours d’édition.

### 3.2.5 Gestion visuelle de l’anneau NeoPixel

L’anneau NeoPixel de 60 LEDs représente une horloge analogique en temps réel :

- Heure : aiguille en rouge
- Minute : aiguille en vert
- Seconde : progression en bleu cumulatif de la LED 0 jusqu’à la seconde courante

Le rendu intègre des règles de superposition pour conserver une lecture claire en cas de recouvrement :

- Heure + Minute → jaune
- Heure + Seconde → magenta
- Minute + Seconde → cyan-vert
- Heure + Minute + Seconde → blanc

Des marqueurs d’heures (LED de repère) sont également affichés sur les positions multiples de 5, avec des teintes adaptées lorsqu’ils se superposent aux aiguilles.

En cas de dégradation de la qualité de l’air (eCO2 au-dessus du seuil), l’anneau bascule en mode alerte :

- Clignotement rouge rapide (ON/OFF),
- Luminosité renforcée pour une meilleure visibilité,
- Possibilité de désactivation temporaire via bouton dédié,
- Réarmement automatique lorsque la qualité d’air repasse sous le seuil.

## 3.3 Conception des modules

### 3.3.1 Module 1 Gestion des entrées (boutons)

Ce module lit les 6 boutons poussoirs avec une logique d’antirebond logiciel.

Il transforme les changements d’état physiques en événements d’appui exploitables par l’application (menu, incrémentation, décrémentation, changement d’affichage, luminosité, désactivation alerte).

### 3.3.2 Module 2 Gestion RTC (temps réel)

Ce module initialise et interroge le DS1307 via I2C.

Il fournit l’heure/date courante au reste du programme et applique les nouvelles valeurs validées en mode configuration (jour, mois, heure, minute, seconde).

### 3.3.3 Module 3 Gestion capteur environnemental (BME680)

Ce module réalise l’acquisition périodique des mesures (température, humidité, pression, gaz).

Il applique :

- Une compensation de température (Tcomp),
- Un filtrage du signal gaz,
- Une baseline adaptative, (référence air propre)
- Une conversion vers une estimation PPM~ / eCO2.

Il intègre également un mécanisme de reprise en cas d’échec de lecture capteur.

### 3.3.4 Module 4 Gestion affichage alphanumérique (HT16K33)

Ce module pilote l’afficheur 4x14 segments.

En mode normal, il réalise une rotation automatique des pages (eCO2, TEMP, HUMD, ATMO, DATE) avec affichage d’un TAG avant la valeur.

En mode configuration, il affiche uniquement le champ en cours d’édition.

### 3.3.5 Module 5 Gestion anneau NeoPixel (horloge + alerte)

Ce module pilote l’anneau NeoPixel 60 LEDs et assure à la fois l’affichage horaire et la signalisation d’alerte.

En mode normal, il dessine une horloge analogique :

- Heure en rouge,
- Minute en vert,
- Secondes en bleu cumulatif (de la LED 0 jusqu’à la seconde courante).

Le module gère également les superpositions entre aiguilles (et marqueurs horaires) à l’aide de couleurs dédiées, afin de conserver une lecture visuelle claire lorsque plusieurs informations occupent la même LED.

En mode alerte qualité d’air (eCO2 au-dessus du seuil), le comportement bascule automatiquement en :

- Clignotement rouge rapide de l’anneau complet,
- Luminosité renforcée pour une visibilité maximale,
- Désactivation temporaire possible via bouton utilisateur,
- Réarmement automatique lorsque la valeur repasse sous le seuil.

Le module intègre enfin une logique d’optimisation de rendu (mise à jour uniquement quand nécessaire) pour limiter les artefacts visuels et améliorer la stabilité de l’affichage.

### 3.3.6 Module 6 Logique applicative (orchestration)

Ce module central, exécuté dans loop(), coordonne l’ensemble :

1. Lecture des boutons,
2. Acquisition capteurs,
3. Mise à jour affichage 14 segments,
4. Rendu de l’anneau selon l’état courant (normal, configuration, alerte).

Cette orchestration garantit un fonctionnement réactif, modulaire et maintenable.

## 3.4 Diagrammes de flux

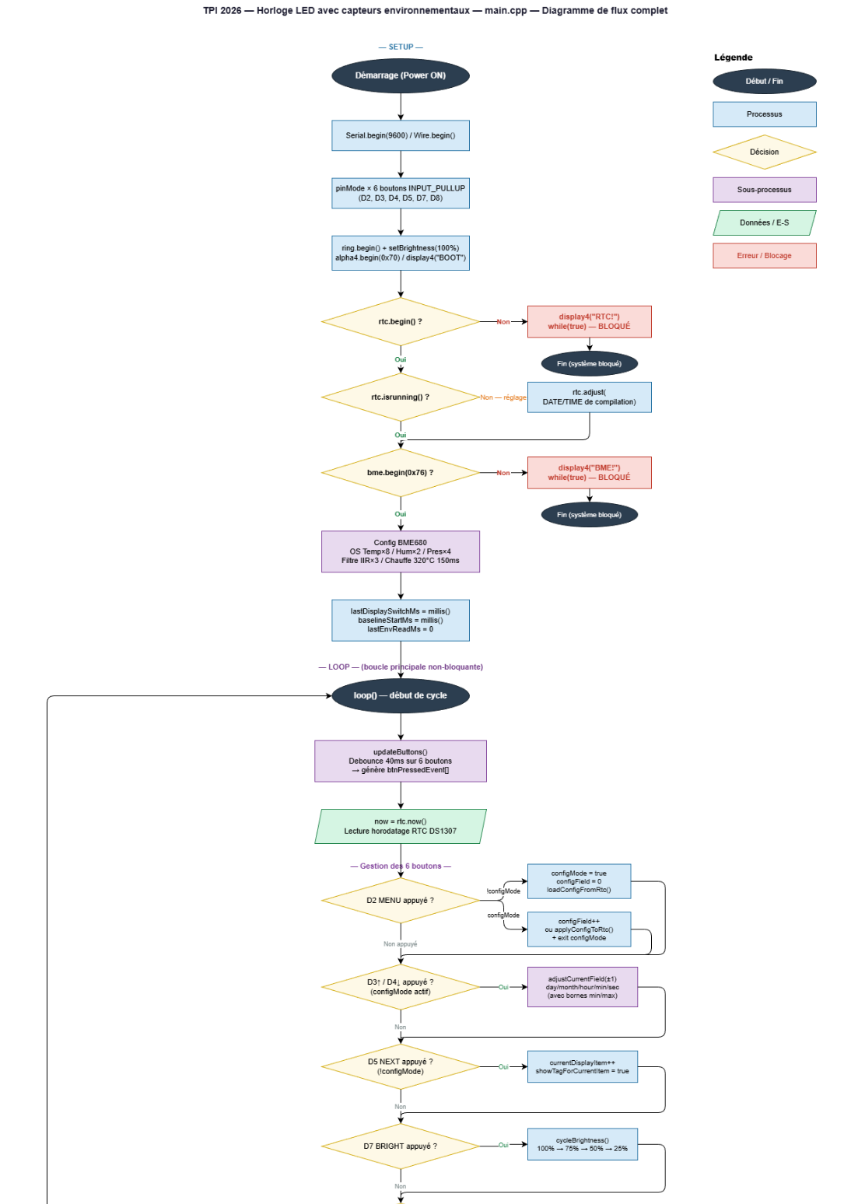
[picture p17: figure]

Figure 25 Image du diagramme de flux du code partie 1

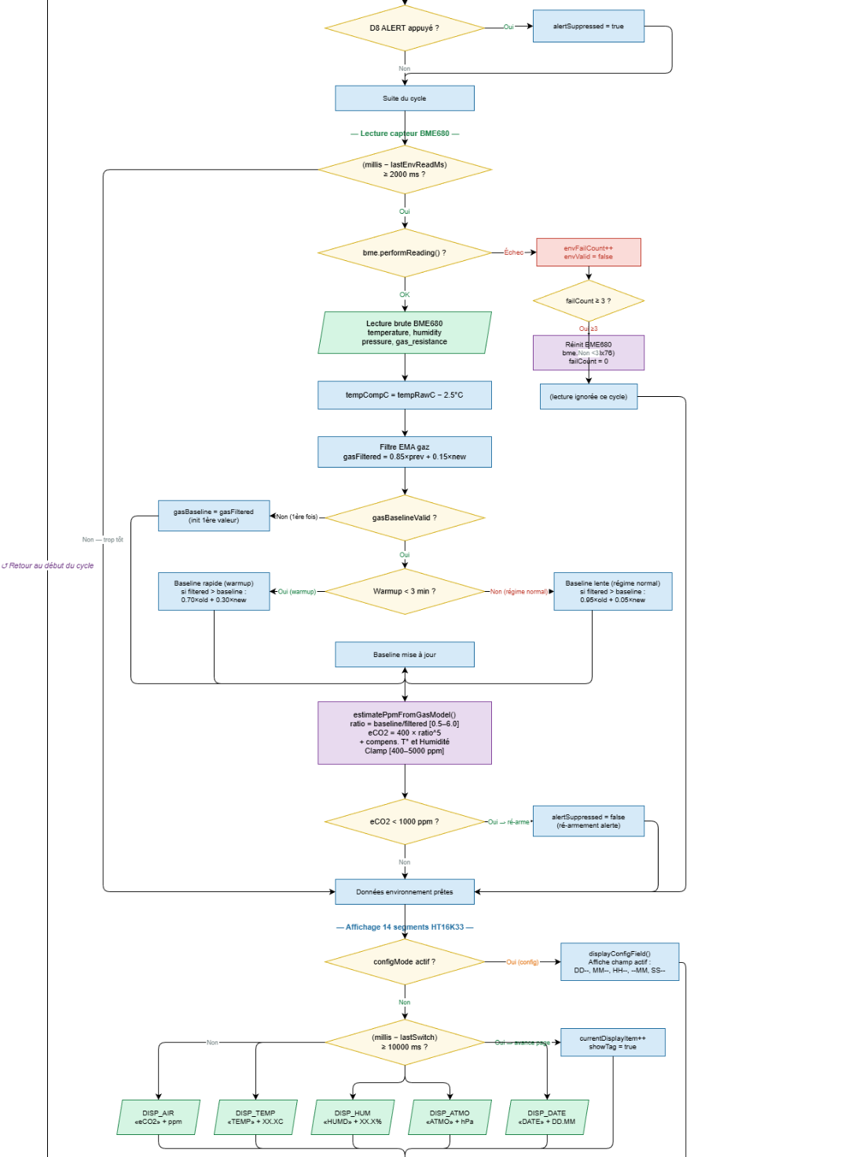
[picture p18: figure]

Figure 26 Image du diagramme de flux du code partie 2

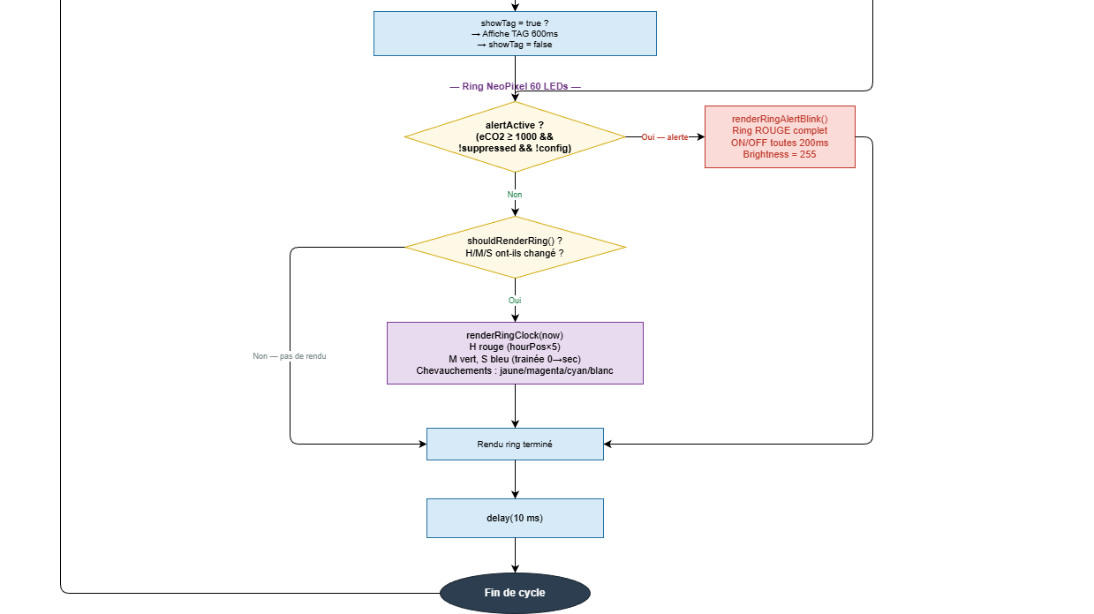
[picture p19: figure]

Figure 27 Image du diagramme de flux du code partie 3

## 3.5 Stratégie de test

### 3.5.1 Types de tests et ordre d'exécution

Les tests seront réalisés en quatre phases successives, dans un ordre qui va du plus simple au plus complexe.

#### 3.5.1.1 Phase 1 Tests unitaires par composant

Avant toute intégration, chaque composant est testé individuellement à l'aide d'un programme Arduino dédié et minimaliste. L'objectif est de vérifier que le composant répond correctement et que le câblage est valide, sans interférence des autres modules.

L'ordre de test sera le suivant :

- RTC DS1307 : vérification de la lecture et de l'écriture de l'heure, contrôle de la précision après redémarrage avec pile en place.
- BME680 : vérification des quatre mesures (température, humidité, pression, COV), contrôle de la stabilisation des valeurs après le temps de chauffe du capteur.
- HT16K33 : affichage de caractères de test sur les quatre digits, vérification de la lisibilité et de la réactivité de l'écran.
- NeoPixel : allumage séquentiel de chaque LED du cercle (de la LED 0 à la LED 59), vérification des couleurs RGB, test de la luminosité à différents niveaux.
- Boutons poussoirs : test de chaque bouton un par un, vérification de la détection de l'appui et du relâchement, contrôle de l'efficacité du debounce logiciel.

#### 3.5.1.2 Phase 2 Tests d'intégration par fonctionnalité

Une fois les composants validés individuellement, on teste les fonctionnalités complètes du système, en combinant les modules entre eux :

- Affichage de l'heure en temps réel sur l'anneau NeoPixel via le RTC.
- Affichage alterné des données environnementales sur le HT16K33 via le BME680.
- Réglage manuel de l'heure via les boutons dédiés.
- Changement de mode d'affichage et ajustement de la luminosité via les boutons correspondants.
- Déclenchement de l'alerte visuelle LED lorsque le seuil de qualité de l'air est dépassé.

#### 3.5.1.3 Phase 3 Tests d'intégration globale

L'ensemble du système est testé en conditions réelles de fonctionnement, tous les modules actifs simultanément. On vérifie que les différentes fonctionnalités cohabitent sans conflit, que le bus I²C ne génère pas d'erreurs de communication, et que les performances générales restent stables dans le temps.

#### 3.5.1.4 Phase 4 Tests de robustesse et cas limites

On soumet le système à des situations particulières pour vérifier sa solidité :

- Coupure et rétablissement de l'alimentation (vérification que l'heure reste correcte grâce au RTC).
- Simulation d'une mauvaise qualité de l'air (valeur COV dépassant le seuil défini) pour vérifier le déclenchement de l'alerte.
- Maintien d'un bouton appuyé de manière prolongée pour vérifier l'absence de comportement erratique.
- Fonctionnement continu pendant une période prolongée pour détecter d'éventuelles dérives ou fuites mémoire.

### 3.5.2 Moyens à mettre en œuvre

Les tests seront réalisés avec les moyens suivants :

- CLion avec PlatformIO : pour compiler et téléverser les programmes de test sur la carte Arduino, et visualiser les sorties via le moniteur série.
- Moniteur série (Serial Monitor) : outil principal de diagnostic, il permettra d'afficher en temps réel les valeurs lues par les capteurs, les états des boutons et les éventuels messages d'erreur.
- Multimètre : utilisé lors de la phase de câblage pour vérifier la continuité des connexions et l'absence de court-circuit avant toute mise sous tension.
- Observation visuelle directe : pour valider le comportement de l'anneau LED, la lisibilité de l'affichage alphanumérique et la réactivité des boutons.
- Journal de test : chaque test sera consigné dans le journal de travail avec son résultat (succès/échec), les éventuelles anomalies constatées et les corrections apportées.

### 3.5.3 Couverture des tests

Les tests ne seront pas exhaustifs au sens strict du terme. En effet, tester l'intégralité des combinaisons possibles d'états (toutes les heures, toutes les valeurs de capteurs, toutes les séquences de boutons) serait irréaliste dans le temps imparti pour ce TPI.

La stratégie adoptée est une couverture fonctionnelle ciblée : on teste les cas nominaux (fonctionnement normal attendu), les cas limites identifiés comme critiques (seuil d'alerte, coupure de courant, debounce) et les cas les plus susceptibles de révéler un défaut d'intégration. Les combinaisons peu probables ou sans impact sur la sécurité du système ne seront pas testées.

Ce choix est justifié par la nature du projet : il s'agit d'un appareil de visualisation et d'alerte, non d'un système critique où une défaillance entraînerait des conséquences graves. Une couverture fonctionnelle bien ciblée est donc suffisante et proportionnée aux enjeux.

### 3.5.4 Données de test

Les données de test seront majoritairement des données réelles, collectées directement par les capteurs en conditions d'utilisation normales. Pour les tests unitaires du BME680, les valeurs lues (température, humidité, pression) seront comparées à des références connues (température de la pièce vérifiée avec un thermomètre externe, humidité approximative selon la saison).

Pour le test de l'alerte visuelle, dans la mesure où il n'est pas aisé de dégrader volontairement la qualité de l'air de manière contrôlée, le seuil de déclenchement sera temporairement abaissé dans le code afin de simuler une situation d'alerte sans avoir à créer réellement de mauvaises conditions environnementales.

Pour le RTC, l'heure sera réglée manuellement à une valeur de référence et confrontée à l'heure réelle après plusieurs minutes de fonctionnement afin d'évaluer la dérive.

### 3.5.5 Testeurs extérieurs

Les tests seront principalement réalisés par le candidat lui-même tout au long de la phase de développement. Aucun testeur extérieur formel n'est prévu dans le cadre de ce TPI.

Cependant, une validation informelle pourra être effectuée par le chef de projet Raphaël Favre lors des points de suivi réguliers, notamment pour valider que le comportement visuel de l'horloge et des alertes correspond aux attentes du cahier des charges. Les experts pourront également observer le fonctionnement du système lors de la présentation finale du 2 ou 3 juin 2026.

## 3.6 Planification finale

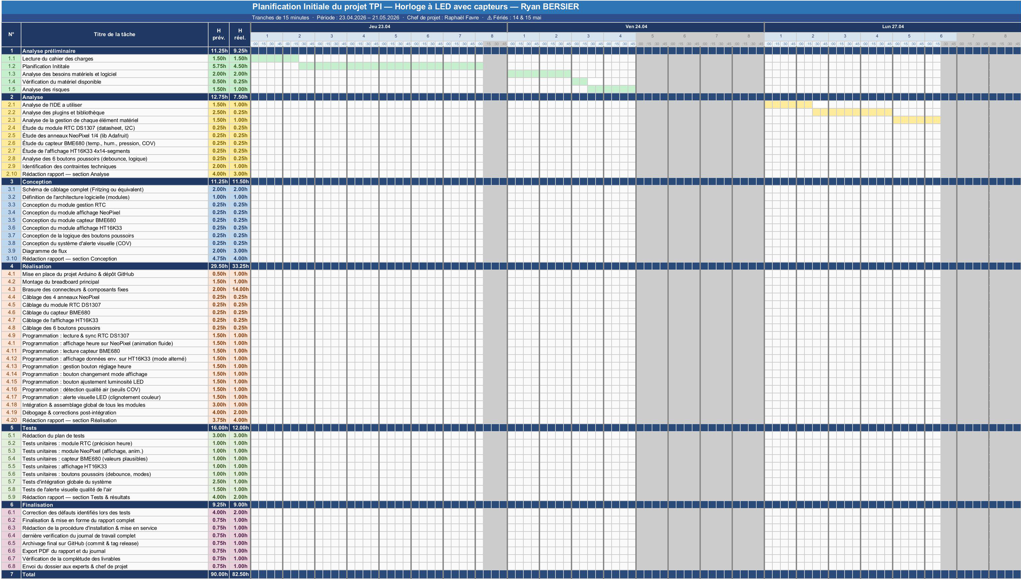
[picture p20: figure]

Figure 28 planning final partie 1

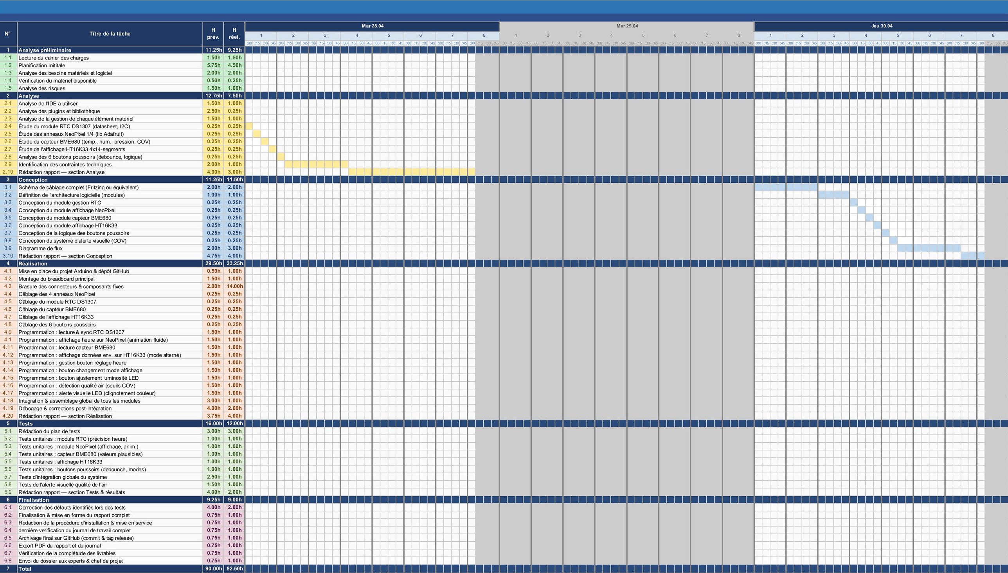
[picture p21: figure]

Figure 29 planning final parties 2

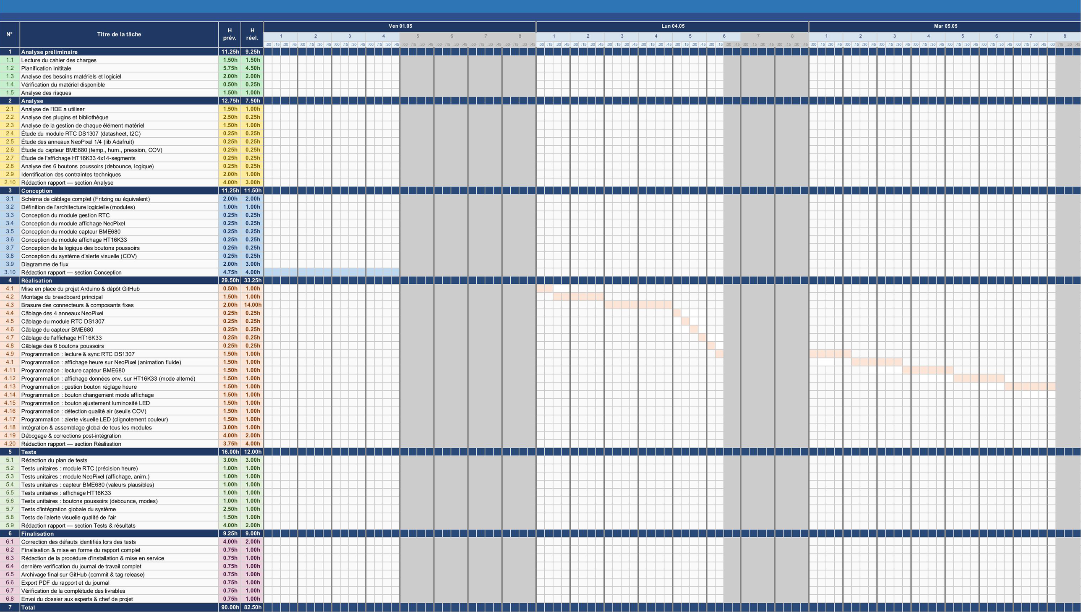
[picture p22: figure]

Figure 30 planning final parties 3

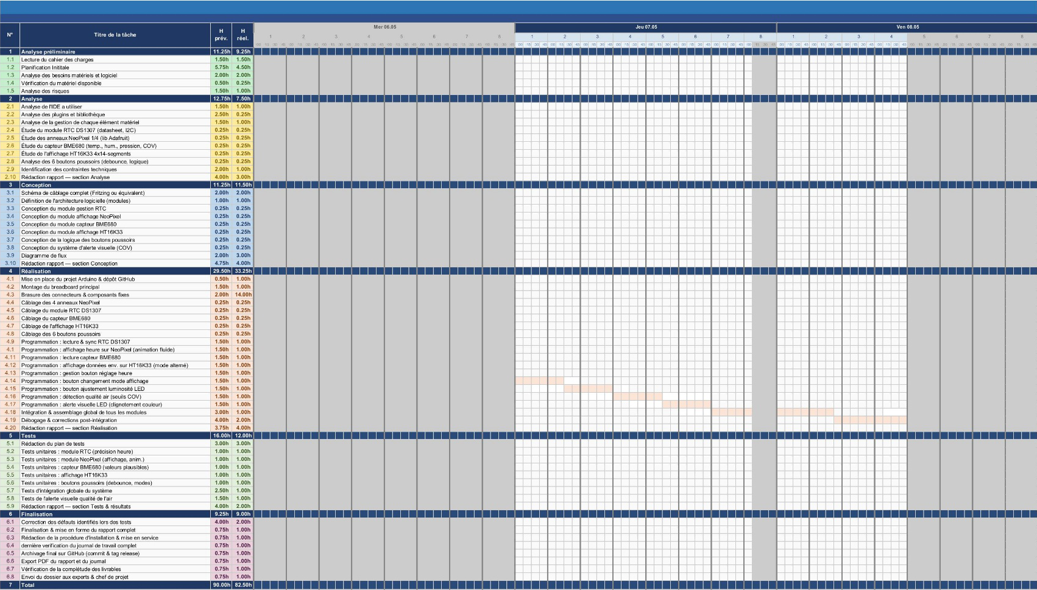
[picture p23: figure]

Figure 31 planning final parties 4

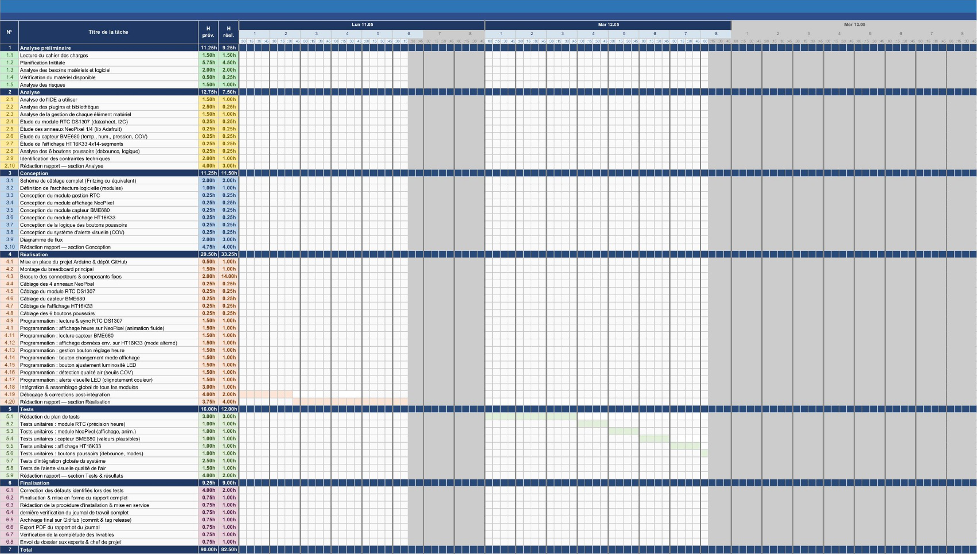
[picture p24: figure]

Figure 32 planning final parties 5

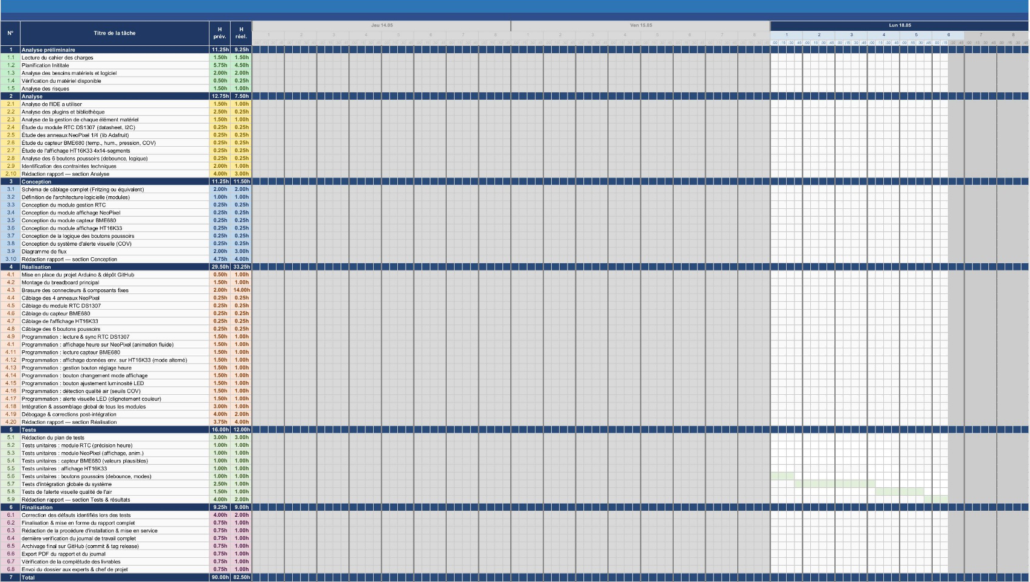
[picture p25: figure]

Figure 33 planning final parties 6

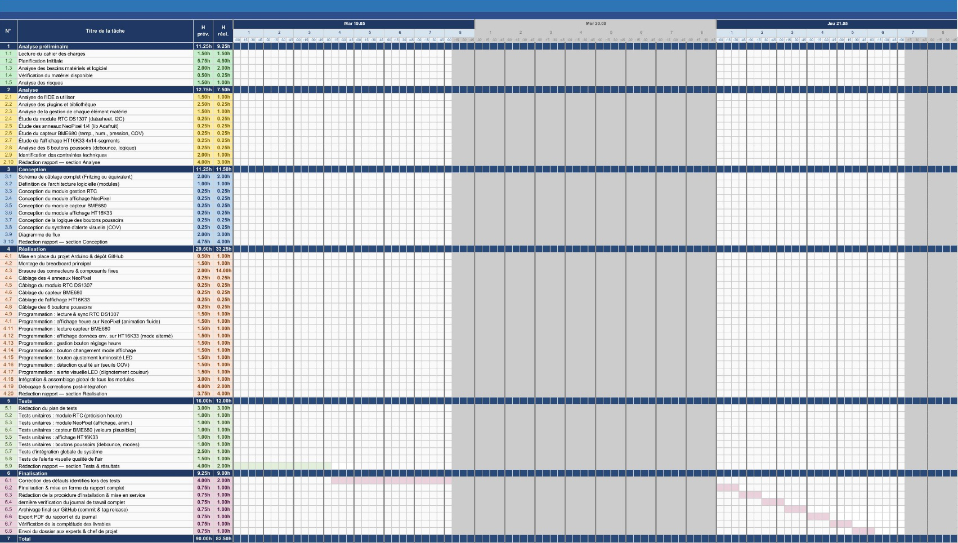
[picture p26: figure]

Figure 34 planning final parties 7

## 3.7 Dossier de conception

### 3.7.1 Choix du matériel

Les choix matériels ont été analysés en détail dans la section 2.2. Le tableau ci-dessous résume les décisions retenues pour ce projet :

Composant | Référence retenue | Rôle principal | Interface
Microcontrôleur | Arduino UNO REV3 (ATmega328P) | Orchestration de tout le système | —
Affichage horloge | 4× Adafruit NeoPixel 1/4 anneau (60 LED WS2812B) | Horloge analogique + alerte visuelle | Signal numérique D6
Capteur environnemental | Adafruit BME680 | Température, humidité, pression, COV | I²C (0x76)
Horloge temps réel | Adafruit RTC DS1307 + pile CR1220 | Maintien de l'heure sans alimentation | I²C (0x68)
Affichage données | Adafruit 4×14 segments HT16K33 | Affichage textuel des mesures | I²C (0x70)
Interface utilisateur | 6 boutons poussoirs | Réglage heure, luminosité, mode, alerte | Digital D2/D3/D4/D5/D7/D8
Alimentation / upload | Câble USB-B 2.0 vers USB-A 2.0 | Alimentation + téléversement du code | USB
Prototypage | Breadboard + jumpers mâle-mâle | Connexions sans brasure | —
Station de travail | PC CPNV Dell OptiPlex 7000 | Développement, rédaction, versioning | —

### 3.7.2 Choix des outils logiciels

#### 3.7.2.1 Pour la réalisation (développement)

Outil | Version / Référence | Usage
CLion | JetBrains CLion 2026.1 | IDE principale de développement C++
PlatformIO | Plugin CLion | Gestion des bibliothèques, compilation, upload
Git | 2.51.0.windows.1 | Versioning du code source
GitHub | github.com | Dépôt distant, sauvegarde, livraison
Fritzing | 0.9.3b | Schéma de câblage breadboard et schématique
Microsoft Word | Office 365 | Rédaction du rapport et du journal de travail
Microsoft Excel | Office 365 | Journal de travail et planification initial/final
Microsoft PowerPoint | Office 365 | Présentation orale finale
Draw.io | 30.0.2 | Conception de diagrammes de flux
Davinci Resolve | 21 beta 3 | Montage vidéo

#### 3.7.2.2 Bibliothèques Arduino (via PlatformIO)

Catégorie | Composant / Bibliothèque | Version | Utilité
Platform | Atmelavr | 5.1.0 | Plateforme PlatformIO pour les microcontrôleurs AVR d’Atmel/Microchip (Arduino Uno, Nano, Mega, etc.).
Framework | Framework-arduino-avr | 5.2.0 | Framework Arduino officiel pour les cartes AVR. Fournit les fonctions setup(), loop(), digitalWrite(), etc.
Outil | Tool-avrdude | 1.60300.200527 | Logiciel utilisé pour téléverser le programme sur la carte Arduino via USB.
Compilateur | Toolchain-atmelavr | 1.70300.191015 | Ensemble des outils de compilation AVR (gcc, g++, linker…). Transforme le code C/C++ en programme exécutable pour le microcontrôleur.

Bibliothèques principales

Bibliothèque | Version | Utilité
Adafruit BME680 Library | 2.0.6 | Gestion du capteur environnemental BME680 (température, humidité, pression atmosphérique et qualité de l’air).
Adafruit LED Backpack Library | 1.5.1 | Contrôle des afficheurs et matrices LED utilisant les contrôleurs HT16K33.
Adafruit NeoPixel | 1.15.4 | Contrôle des LEDs RGB adressables type WS2812 / NeoPixel.

Dépendances des bibliothèques

Bibliothèque | Version | Utilité
Adafruit BusIO | 1.17.4 | Simplifie la communication I2C et SPI avec les composants Adafruit.
Adafruit GFX Library | 1.12.6 | Bibliothèque graphique de base pour dessiner du texte, des formes et des images sur écrans OLED/TFT.
Adafruit SSD1306 | 2.5.16 | Gestion des écrans OLED SSD1306 en I2C ou SPI.
Adafruit Unified Sensor | 1.1.15 | Interface commune pour différents capteurs Adafruit.
Adafruit GPS Library | 1.7.5 | Communication avec les modules GPS Adafruit.
RTClib | 2.1.4 | Gestion des modules horloge temps réel (RTC) comme DS1307 ou DS3231.
WaveHC | 1.0.5 | Lecture de fichiers audio WAV depuis une carte SD sur Arduino.
Adafruit ILI9341 | 1.6.3 | Contrôle des écrans TFT utilisant le contrôleur ILI9341.
Adafruit STMPE610 | 1.1.6 | Gestion du contrôleur tactile STMPE610.
Adafruit TSC2007 | 1.1.2 | Gestion du contrôleur tactile TSC2007.
Adafruit SH110X | 2.1.14 | Gestion des écrans OLED basés sur le contrôleur SH110X.
Adafruit TouchScreen | 1.1.6 | Lecture des écrans tactiles résistifs.

### 3.7.3 Choix du système d'exploitation

#### 3.7.3.1 Pour la réalisation

Le développement est réalisé sous Windows 11 (PC CPNV). CLion avec PlatformIO est compatible Windows nativement. Les drivers USB pour l'Arduino UNO (CH340 ou ATmega16U2) sont installés automatiquement par Windows Update ou manuellement via le site Arduino.

#### 3.7.3.2 Pour l'utilisation

Le système embarqué ne repose sur aucun système d'exploitation. Le microcontrôleur ATmega328P exécute le firmware directement sur le hardware (bare-metal), sans couche OS. La boucle principale loop() assure l'ordonnancement de toutes les tâches de manière non-bloquante via millis().

### 3.7.4 Architecture du programme

Le programme est structuré en un fichier unique main.cpp organisé en fonctions modulaires cohérentes. L'architecture repose sur deux fonctions Arduino standard setup() et loop() complétées par six blocs fonctionnels indépendants.

#### 3.7.4.1 Vue d'ensemble de l'architecture

main.cpp

│

├── setup()

│ ├── Initialisation Serial + Wire (I²C)

│ ├── Configuration INPUT_PULLUP des 6 boutons

│ ├── Initialisation NeoPixel (éteint)

│ ├── Initialisation HT16K33 (affiche "BOOT")

│ ├── Vérification RTC → blocage si absent ("RTC!")

│ ├── Synchronisation RTC si arrêté

│ └── Initialisation BME680 → blocage si absent ("BME!")

│

└── loop() [non bloquant, cycle ~10ms]

├── updateButtons() ← lecture + debounce

├── rtc.now() ← lecture heure courante

├── handleButtons(now) ← routage des événements

├── updateEnvironmentRead() ← lecture BME680 périodique

├── updateDisplay(now) ← mise à jour HT16K33

└── shouldRenderRing() ? ← mise à jour NeoPixel si nécessaire

├── renderRingAlertBlink() [si alerte active]

└── renderRingClock(now) [sinon]

### 3.7.5 Découpage modulaire

Le programme est découpé en 6 modules fonctionnels logiques, tous dans main.cpp :

#### 3.7.5.1 Module 1 Gestion des boutons (updateButtons, consumePress)

Entrées : broches D2, D3, D4, D5, D7, D8 (INPUT_PULLUP)

Sorties : tableau btnPressedEvent[6] — un booléen par bouton, mis à true lors d'un front descendant validé

Traitement :

- Lecture brute de chaque broche à chaque cycle
- Comparaison avec l'état précédent
- Si changement détecté → démarrage de la fenêtre antirebond (40ms)
- Si état stable depuis 40ms et différent de l'état courant → mise à jour + génération d'événement si LOW

Contrainte : la fonction consumePress(idx) consomme l'événement de façon exclusive — un appui ne peut déclencher qu'une seule action.

#### 3.7.5.2 Module 2 Gestion temporelle (initRTC, loadConfigFromRtc, applyConfigToRtc, displayConfigField, adjustCurrentField, onMenuButton)

Entrées : module RTC DS1307 via I²C (adresse 0x68), événements boutons D2/D3/D4

Sorties : objet DateTime now utilisé par le reste du programme, écriture RTC via rtc.adjust()

Traitement :

- Lecture de l'heure toutes les itérations de loop() via rtc.now()
- Mode configuration activé par D2 (MENU) :
  - Champs éditables dans l'ordre : jour → mois → heure → minute → seconde
  - D3 (UP) incrémente le champ actif dans ses bornes valides
  - D4 (DOWN) décrémente
  - D2 (MENU) valide et passe au champ suivant au 5e champ : écriture RTC et sortie du mode config
- Gestion des bornes : jours selon mois/année, heures 0-23, minutes/secondes 0-59

#### 3.7.5.3 Module 3 Capteur environnemental (updateEnvironmentRead, estimatePpmFromGasModel)

Entrées : BME680 via I²C (adresse 0x76), timer interne lastEnvReadMs

Sorties : variables globales tempCompC, envHumPct, envPressureHpa, envPpmEstimate, envValid

Traitement (toutes les 2000ms) :

1. Lecture brute BME680 : température, humidité, pression, résistance gaz (Ohm)
2. Compensation température : tempCompC = tempRawC - 2.5°C (offset fixe pour corriger l'auto-échauffement du capteur)
3. Filtrage EMA du signal gaz : gasFiltered = 0.85 × old + 0.15 × new
4. Baseline adaptative (référence "air propre") :
  a. Phase warmup (< 3 min) : baseline suit rapidement les meilleures valeurs (0.70 × old + 0.30 × new)
  b. Régime normal : baseline monotone croissante uniquement (0.95 × old + 0.05 × new)
5. Estimation eCO2 : ppm = 400 × (baseline / filtered)^5 puis compensation T/H, clampé [400–5000 ppm]
6. Réarmement alerte si ppm revient sous 1000

Gestion d'erreur : après 3 lectures consécutives en échec → réinitialisation complète du BME680

#### 3.7.5.4 Module 4 Affichage alphanumérique (updateDisplay, display4, displayTemp, displayHumidity, displayDateDDMM, displayNumber4, showTagThenValue)

Entrées : variables environnementales, DateTime now, configMode, currentDisplayItem

Sorties : affichage HT16K33 via I²C (adresse 0x70)

Traitement mode normal :

- Rotation automatique des pages toutes les 10 secondes dans l'ordre : eCO2 → TEMP → HUMD → ATMO → DATE
- Avant chaque valeur : affichage du TAG pendant 600ms (non bloquant via tagDisplayUntilMs)
- Bouton D5 (NEXT) : avance manuellement à la page suivante avec reset du timer

Traitement mode configuration :

- Affichage du champ en cours d'édition uniquement :
  - Jour : DD--
  - Mois : MM--
  - Heure : HH--
  - Minute : --MM
  - Seconde : SS--

Formats d'affichage par page :

Page | TAG | Format valeur | Exemple
eCO2 | eCO2 | Entier sur 4 chars | 1234
Température | TEMP | XX.XC avec virgule décimale | 22.5C
Humidité | HUMD | XX.X% avec virgule décimale | 45.2%
Pression | ATMO | Entier hPa sur 4 chars | 1013
Date | DATE | DD.MM avec point décimal | 08.05

#### 3.7.5.5 Module 5 Anneau NeoPixel (renderRingClock, renderRingAlertBlink, shouldRenderRing, cycleBrightness)

Entrées: DateTime now, envPpmEstimate, alertSuppressed, brightnessStep, configMode

Sorties : 60 LEDs WS2812B via D6

Traitement mode horloge normal :

Le rendu du ring est réalisé uniquement lorsqu’un changement utile est détecté (heure/minute/seconde), afin de limiter les rafraîchissements inutiles et le scintillement.

- Position heure : (heure % 12) × 5 (sur 60 positions)
- Position minute : minute (0–59)
- Secondes : arc cumulatif de LED0 jusqu’à la seconde courante
- Marqueurs horaires : LED de repère sur chaque multiple de 5 (0, 5, 10, ..., 55)

Gestion des superpositions (masque binaire)

Le module utilise un masque 4 bits :

- Bit0 = Heure (H)
- Bit1 = Minute (M)
- Bit2 = Marqueur blanc d’heure (W)
- Bit3 = Seconde (S)

Masque | Composantes | Couleur affichée
0001 | H | Rouge (100,0,0)
0010 | M | Vert (0,100,0)
0100 | W | Blanc faible (35,35,35)
1000 | S | Bleu (0,0,100)
0011 | H+M | Jaune (100,100,0)
0101 | H+W | Rouge (100,0,0)
1001 | H+S | Magenta (100,0,100)
0110 | M+W | Vert clair (40,170,55)
1010 | M+S | Cyan-vert (0,110,35)
1100 | W+S | Bleu clair (40,60,170)
0111 | H+M+W | Jaune (100,100,0)
1011 | H+M+S | Blanc (100,100,100)
1101 | H+W+S | Magenta (100,0,100)
1110 | M+S+W | Cyan-vert clair (35,170,95)
1111 | H+M+S+W | Blanc (100,100,100)

Luminosité

cycleBrightness() applique 4 paliers via D7 (BRIGHT) : 100% → 75% → 50% → 25% (puis boucle)

Traitement mode alerte (eCO2 >= 1000 ppm)

- Anneau complet en rouge clignotant ON/OFF toutes les 200 ms
- Luminosité forcée à 255 pendant l’alerte
- D8 (ALERT) désactive l’alerte tant que le seuil n’est pas repassé sous la limite
- Réarmement automatique lorsque eCO2 < 1000 ppm

Optimisation d’affichage

shouldRenderRing() évite les rendus inutiles :

- En mode normal : rendu uniquement lors d’un changement temps
- En mode alerte : rendu uniquement au changement de phase de clignotement

#### 3.7.5.6 Module 6 Orchestration (loop, handleButtons)

Entrées : tous les modules ci-dessus

Sorties : coordination du rendu et des états

Ordre d'exécution à chaque cycle (~10ms) :

1. updateButtons() → mise à jour des états boutons

2. now = rtc.now() → lecture horodatage RTC

3. handleButtons(now) → routage des 6 boutons :

D2 → onMenuButton() : entrée/navigation/sortie config

D3 → adjustCurrentField(+1) : incrément champ (si configMode)

D4 → adjustCurrentField(-1) : décrément champ (si configMode)

D5 → changement page HT16K33 (si !configMode)

D7 → cycleBrightness() : cycle luminosité NeoPixel

D8 → alertSuppressed = true : désactivation alerte

4. updateEnvironmentRead() → lecture BME680 si délai écoulé

5. updateDisplay(now) → mise à jour HT16K33

6. shouldRenderRing() ? → rendu NeoPixel si nécessaire

└── renderRingAlertBlink() ou renderRingClock(now)

7. delay(10) → stabilisation cycle

### 3.7.6 Entrées / sorties des modules

Module | Entrées | Sorties
Boutons | D2, D3, D4, D5, D7, D8 (physique) | btnPressedEvent[6] (logique)
RTC | I²C 0x68, événements config | DateTime now, écriture RTC
BME680 | I²C 0x76, millis() | tempCompC, envHumPct, envPressureHpa, envPpmEstimate, envValid
HT16K33 | Variables env., now, configMode | Affichage I²C 0x70
NeoPixel | now, envPpmEstimate, brightnessStep, alertSuppressed | 60 LEDs D6
Orchestration | Tous | Coordination états + rendu

### 3.7.7 Variables globales et états du système

Variable | Type | Rôle
configMode | bool | Indique si le système est en mode réglage
configField | uint8_t (0–4) | Champ en cours d'édition (jour/mois/h/min/sec)
alertSuppressed | bool | Alerte désactivée manuellement par l'utilisateur
brightnessStep | uint8_t (0–3) | Niveau de luminosité actuel (100/75/50/25%)
currentDisplayItem | enum (0–4) | Page affichée sur le HT16K33
envPpmEstimate | int | Valeur eCO2 estimée en ppm
envValid | bool | Indique si la dernière lecture BME680 est valide
gasBaselineOhm | float | Référence "air propre" pour le calcul eCO2
gasFilteredOhm | float | Signal gaz lissé (EMA)

### 3.7.8 Câblage tableau de connexions complet

Composant | Broche composant | Broche Arduino
Breadboard rail + | — | 5V
Breadboard rail - | — | GND
RTC DS1307 | VCC | Breadboard 5V
RTC DS1307 | GND | Breadboard GND
RTC DS1307 | SDA | A4
RTC DS1307 | SCL | A5
BME680 | 5V | Breadboard 5V
BME680 | GND | Breadboard GND
BME680 | SDA | A4 (bus partagé)
BME680 | SCL | A5 (bus partagé)
HT16K33 | VCC | Breadboard 5V
HT16K33 | GND | Breadboard GND
HT16K33 | SDA | A4 (bus partagé)
HT16K33 | SCL | A5 (bus partagé)
NeoPixel Q1 | PWR | Breadboard 5V
NeoPixel Q1 | GND | Breadboard GND
NeoPixel Q1 | DIN | D6
NeoPixel Q1→Q2 | DOUT→DIN | Chaîne directe
NeoPixel Q2→Q3 | DOUT→DIN | Chaîne directe
NeoPixel Q3→Q4 | DOUT→DIN | Chaîne directe
NeoPixel Q2/Q3/Q4 | PWR | Q1 PWR (chaîne)
NeoPixel Q2/Q3/Q4 | GND | Q1 GND (chaîne)
Bouton 1 | Signal | D2
Bouton 2 | Signal | D3
Bouton 3 | Signal | D4
Bouton 4 | Signal | D5
Bouton 5 | Signal | D7
Bouton 6 | Signal | D8
Tous boutons | GND (patte A) | Breadboard GND

Résistances pull-up internes activées via INPUT_PULLUP aucune résistance physique nécessaire.

# 4 Réalisation

## 4.1 Dossier de réalisation

### 4.1.1 Versions des outils logiciels

Outil | Version
Système d'exploitation | Windows 11 — PC CPNV Dell OptiPlex 7000
CLion | JetBrains CLion 2026.1
PlatformIO (plugin CLion) | Intégré CLion
Platform Atmel AVR | 5.1.0
Framework Arduino AVR | 5.2.0
Toolchain AVR-GCC | 7.3.0 (1.70300.191015)
avrdude | 6.3.0 (1.60300.200527)
Git | 2.51.0.windows.1
Fritzing | 0.9.3b
Microsoft Word | Office 365
Microsoft Excel | Office 365
Microsoft PowerPoint | Office 365
Draw.io | 30.0.2
Davinci Resolve | 21 beta 3

### 4.1.2 Versions des bibliothèques

#### 4.1.2.1 Bibliothèques principales

Bibliothèque | Version | Utilité
Adafruit BME680 Library | 2.0.6 | Capteur environnemental température, humidité, pression, qualité de l'air
Adafruit LED Backpack Library | 1.5.1 | Contrôle de l'affichage HT16K33 4×14 segments
Adafruit NeoPixel | 1.15.4 | Contrôle des 60 LEDs WS2812B de l'anneau
RTClib | 2.1.4 | Gestion du module horloge temps réel DS1307

#### 4.1.2.2 Dépendances installées automatiquement par PlatformIO

Bibliothèque | Version | Utilité
Adafruit BusIO | 1.17.4 | Abstraction communication I²C et SPI pour les composants Adafruit
Adafruit GFX Library | 1.12.6 | Bibliothèque graphique de base (dépendance LED Backpack)
Adafruit Unified Sensor | 1.1.15 | Interface commune pour les capteurs Adafruit
Adafruit SSD1306 | 2.5.16 | Dépendance transitoire de la GFX Library
Adafruit GPS Library | 1.7.5 | Dépendance transitoire
Adafruit ILI9341 | 1.6.3 | Dépendance transitoire
Adafruit STMPE610 | 1.1.6 | Dépendance transitoire
Adafruit TSC2007 | 1.1.2 | Dépendance transitoire
Adafruit SH110X | 2.1.14 | Dépendance transitoire
Adafruit TouchScreen | 1.1.6 | Dépendance transitoire
WaveHC | 1.0.5 | Dépendance transitoire
Wire | 1.0 | Communication I²C intégrée Arduino AVR
SPI | Intégrée | Communication SPI intégrée Arduino AVR

Les bibliothèques marquées "dépendance transitoire" sont téléchargées automatiquement par PlatformIO comme sous-dépendances mais ne sont pas utilisées directement dans le code du projet.

### 4.1.3 Description exacte du matériel

Composant | Référence exacte | Qté | Remarques
Microcontrôleur | Arduino UNO REV3 ATmega328P 16MHz, 2Ko RAM, 32Ko Flash | 1 | Fourni CPNV
Anneau LED | Adafruit NeoPixel 1/4 Ring 15 LED WS2812B RGB par quart (60 LEDs total) | 4 | Fourni CPNV
Capteur environnemental | Adafruit BME680 Breakout I²C adresse 0x76, alimentation 5V, régulateur intégré | 1 | Fourni CPNV
Horloge temps réel | Adafruit DS1307 RTC Breakout I²C adresse 0x68 | 1 | Fourni CPNV
Pile RTC | CR1220 3V lithium | 1 | Maintien de l'heure hors tension
Affichage | Adafruit 0.54" Quad Alphanumeric Display HT16K33, 4×14 segments, I²C adresse 0x70 | 1 | Fourni CPNV
Boutons | Boutons poussoirs tactiles 6×6mm, 4 pattes | 6 | Fourni CPNV
Breadboard | Breadboard 830 points | 1 | Fourni CPNV
Câble | USB-A vers USB-B 2.0 | 1 | Alimentation + upload firmware Fourni CPNV
Fils | Jumpers mâle-mâle 20cm | ~40 | Fourni CPNV
PC développement | Dell OptiPlex 7000 Windows 11 | 1 | Fourni CPNV

### 4.1.4 Structure des répertoires

C:\Users\pc23owx\Documents\TPI_HORLOGE-LED-CAPTEURS\

│

├── .idea\ ← Configuration CLion du projet racine

│

├── Code\ ← Projet PlatformIO complet

│ ├── .idea\ ← Configuration CLion du projet Code

│ ├── platformio.ini ← Configuration projet (board, libs, port)

│ ├── src\

│ │ └── main.cpp ← Source unique toute la logique du projet

│ ├── include\ ← Headers (non utilisés)

│ ├── lib\ ← Bibliothèques locales (non utilisées)

│ ├── test\ ← Tests (non utilisés en production)

│ └── .pio\ ← Généré par PlatformIO

│ ├── build\uno\

│ │ ├── firmware.elf ← Binaire compilé avec symboles debug

│ │ ├── firmware.hex ← Fichier Intel HEX flashé sur l'Arduino

│ │ ├── FrameworkArduino\ ← Framework Arduino compilé

│ │ ├── lib3f7\RTClib\ ← RTClib compilée

│ │ ├── lib9a8\Adafruit GFX Library\

│ │ ├── libba3\Adafruit NeoPixel\

│ │ ├── libd33\Adafruit Unified Sensor\

│ │ ├── libd7e\Adafruit BusIO\

│ │ ├── libe8a\Adafruit BME680 Library\

│ │ ├── libe96\SPI\

│ │ ├── libeb9\Adafruit LED Backpack Library\

│ │ └── libf9f\Wire\

│ └── libdeps\uno\ ← Sources des bibliothèques téléchargées

│ ├── Adafruit BME680 Library\

│ ├── Adafruit BusIO\

│ ├── Adafruit GFX Library\

│ ├── Adafruit GPS Library\

│ ├── Adafruit ILI9341\

│ ├── Adafruit LED Backpack Library\

│ ├── Adafruit NeoPixel\

│ ├── Adafruit SH110X\

│ ├── Adafruit SSD1306\

│ ├── Adafruit STMPE610\

│ ├── Adafruit TouchScreen\

│ ├── Adafruit TSC2007\

│ ├── Adafruit Unified Sensor\

│ ├── RTClib\

│ └── WaveHC\

│

├── Documentation\

│ ├── Documentation\ ← Rapport TPI (Word + PDF)

│ ├── Journal-de-travail\ ← Journal de travail quotidien

│ ├── Planning\ ← Planning initial tranches 15 minutes

│ └── Schema\ ← Fichiers Fritzing + exports PNG

│

└── Image\

├── Documentation\

│ ├── CDC\ ← Photos du cahier des charges

│ ├── Planning\ ← Captures du planning

│ └── Schema\ ← Exports PNG des schémas Fritzing

├── Logiciel\ ← Captures d'écran CLion, moniteur série

└── Materiel\ ← Photos des composants physiques

### 4.1.5 Liste complète des fichiers projet

#### 4.1.5.1 Code source

Fichier | Emplacement | Description
main.cpp | Code/src/ | Fichier source unique contient setup(), loop() et les 6 modules fonctionnels : gestion boutons, RTC, BME680, HT16K33, NeoPixel, orchestration. Taille : ~770 lignes commentées
platformio.ini | Code/ | Configuration PlatformIO : board uno, framework arduino, 4 bibliothèques principales, port COM7, moniteur 9600 bauds

#### 4.1.5.2 Fichiers générés (ne pas modifier manuellement)

Fichier | Emplacement | Description
firmware.elf | Code/.pio/build/uno/ | Binaire ELF compilé avec symboles debug utilisé en interne par avrdude
firmware.hex | Code/.pio/build/uno/ | Fichier Intel HEX flashé sur l'Arduino via USB à chaque upload

#### 4.1.5.3 Documentation

Fichier | Emplacement | Description
Documentation_TPI_Ryan-Bersier.docx | Documentation/Documentation/ | Rapport TPI complet version Word éditable
Documentation_TPI_Ryan-Bersier.pdf | Documentation/Documentation/ | Rapport TPI version PDF finale livrée aux experts
Journal-de-travail.xlsx | Documentation/Journal-de-travail/ | Journal quotidien : activités, heures prévues vs réelles, remarques
Planification_15min.xlsx | Documentation/Planning/ | Planning initial en tranches de 15 minutes sur toute la période TPI
Schema_Fritzing.fzz | Documentation/Schema/ | Fichier source Fritzing breadboard + schématique électronique
Schema_breadboard.png | Documentation/Schema/ | Export PNG du câblage breadboard vue
Schema_schematique.png | Documentation/Schema/ | Export PNG du schéma électronique complet

### 4.1.6 Configuration PlatformIO (platformio.ini)

; PlatformIO Project Configuration File

;

; Build options: build flags, source filter

; Upload options: custom upload port, speed and extra flags

; Library options: dependencies, extra library storages

; Advanced options: extra scripting

;

; Please visit documentation for the other options and examples

; https://docs.platformio.org/page/projectconf.html

[env:uno]

platform = atmelavr

board = uno

framework = arduino

lib_deps =

adafruit/RTClib

adafruit/Adafruit BME680 Library

adafruit/Adafruit GFX Library

adafruit/Adafruit LED Backpack Library

adafruit/Adafruit NeoPixel

monitor_port = COM7

monitor_speed = 9600

Le port COM7 correspond au port USB détecté sur le PC CPNV. Sur une autre machine, vérifier dans le Gestionnaire de périphériques Windows → Ports (COM & LPT).

### 4.1.7 Reconstruction du logiciel depuis les sources

#### 4.1.7.1 Prérequis

- CLion installé avec le plugin PlatformIO activé
- Connexion Internet pour le premier build (téléchargement bibliothèques)
- Driver USB Arduino UNO installé (ATmega16U2 ou CH340 selon révision)

#### 4.1.7.2 Étapes

1. Récupérer les sources

git clone https://github.com/<ryan-bersier>/TPI_Horloge-LED-Capteurs.git

2. Ouvrir dans CLion

Ouvrir le dossier Code/ CLion détecte automatiquement platformio.ini et configure l'environnement.

3. Premier build

PlatformIO télécharge automatiquement les 4 bibliothèques déclarées dans lib_deps ainsi que toutes leurs dépendances dans .pio/libdeps/uno/.

4. Adapter le port si nécessaire

Remplacer COM7 par le port détecté dans platformio.ini.

5. Compiler et flasher

Cliquer sur Upload dans PlatformIO Tasks compilation et flash en une seule opération via avrdude.

6. Vérifier le démarrage

Ouvrir le Serial Monitor à 9600 bauds BOOT apparaît sur le HT16K33 puis le système démarre. Si RTC! s'affiche → vérifier pile CR1220 et câblage. Si BME! s'affiche → vérifier câblage BME680 adresse 0x76.

#### 4.1.7.3 Occupation mémoire finale (build release) :

Ressource | Utilisé | Total | Pourcentage
RAM | 876 octets | 2048 octets | 42.8%
Flash | 24’124 octets | 32’256 octets | 74.8%

Temps estimé de reconstruction : moins de 5 minutes.

### 4.1.8 Dictionnaire des données

Variables globales portant un état persistant entre les cycles de loop() :

Variable | Type C++ | Plage | Description
configMode | bool | true/false | Système en mode réglage heure/date
configField | uint8_t | 0–4 | Champ actif : 0=jour, 1=mois, 2=heure, 3=minute, 4=seconde
cfgDay | int | 1–31 | Jour en cours de modification
cfgMonth | int | 1–12 | Mois en cours de modification
cfgYear | int | 2026+ | Année (non modifiable via boutons dans cette version)
cfgHour | int | 0–23 | Heure en cours de modification
cfgMinute | int | 0–59 | Minute en cours de modification
cfgSecond | int | 0–59 | Seconde en cours de modification
alertSuppressed | bool | true/false | Alerte désactivée manuellement via D8
brightnessStep | uint8_t | 0–3 | Niveau luminosité : 0=100%, 1=75%, 2=50%, 3=25%
brightnessValues[4] | const uint8_t[] | {100,75,50,25} | Tableau des valeurs de luminosité
COL_R / COL_G / COL_B | const uint8_t | 100 | Intensité de base des couleurs LED (limitée anti-scintillement)
currentDisplayItem | enum DisplayItem | 0–4 | Page HT16K33 : AIR/TEMP/HUM/ATMO/DATE
lastDisplaySwitchMs | uint32_t | millis() | Timestamp du dernier changement de page auto
showTagForCurrentItem | bool | true/false | TAG à afficher avant la prochaine valeur
tagDisplayActive | bool | true/false | TAG en cours d'affichage (fenêtre non bloquante)
tagDisplayUntilMs | uint32_t | millis() | Fin d'affichage du TAG (600ms)
tempRawC | float | -40 – 85 | Température brute lue par le BME680 en °C
tempCompC | float | -40 – 85 | Température compensée (tempRaw - 2.5°C) en °C
TEMP_OFFSET_C | const float | -2.5f | Offset fixe de compensation température
envHumPct | float | 0 – 100 | Humidité relative en %
envPressureHpa | float | 300 – 1100 | Pression atmosphérique en hPa
envGasOhm | uint32_t | > 0 | Résistance gaz brute en Ohm
envPpmEstimate | int | 400 – 5000 | Estimation eCO2 calculée en ppm
envValid | bool | true/false | Dernière lecture BME680 valide
envFailCount | uint8_t | 0–3 | Compteur d'échecs de lecture consécutifs
lastEnvReadMs | uint32_t | millis() | Timestamp de la dernière lecture BME680
lastEnvSuccessMs | uint32_t | millis() | Timestamp de la dernière lecture réussie
ENV_READ_MS | const uint32_t | 2000 | Période de lecture BME680 en ms
gasFilteredOhm | float | > 0 | Résistance gaz lissée par filtre EMA (α=0.15)
gasFilterValid | bool | true/false | Filtre EMA initialisé
gasBaselineOhm | float | > 0 | Référence "air propre" baseline adaptative
gasBaselineValid | bool | true/false | Baseline initialisée
baselineStartMs | uint32_t | millis() | Démarrage phase warmup (3 min)
lastRenderedSecond | int | -1 – 59 | Dernière seconde rendue sur le ring
lastRenderedMinute | int | -1 – 59 | Dernière minute rendue
lastRenderedHour | int | -1 – 23 | Dernière heure rendue
lastRenderedAlertOn | bool | true/false | État alerte du dernier rendu
alertBlinkPhase | uint32_t | 0–1 | Phase clignotement alerte (200ms ON/OFF)
RING_LED_COUNT | const uint8_t | 60 | Nombre total de LEDs de l'anneau
DEBOUNCE_MS | const uint16_t | 40 | Fenêtre antirebond en ms
DISPLAY_ROTATE_MS | const uint32_t | 10000 | Période rotation automatique HT16K33 en ms
TAG_DISPLAY_MS | const uint16_t | 600 | Durée d'affichage du TAG en ms
btnStableState[6] | bool[] | HIGH/LOW | État stable de chaque bouton après debounce
btnLastReading[6] | bool[] | HIGH/LOW | Dernière lecture brute
btnLastChangeMs[6] | uint32_t[] | millis() | Timestamp du dernier changement brut par bouton
btnPressedEvent[6] | bool[] | true/false | Événement d'appui consommable
BTN_PINS[6] | const uint8_t[] | {2,3,4,5,7,8} | Broches Arduino des 6 boutons

### 4.1.9 Extrait commenté Rendu NeoPixel avec masque de bits

Cette partie du code est la plus spécifique au projet et mérite une explication. Le défi est d'afficher simultanément sur les mêmes 60 LEDs les heures, les minutes, les secondes cumulatives et les marqueurs d'heures, sachant que plusieurs informations peuvent occuper la même LED au même instant.

La solution retenue est un masque de 4 bits calculé pour chaque LED :

cpp

uint8_t mask = (hourOn ? 0x1 : 0) | // bit 0 = Heure

(minOn ? 0x2 : 0) | // bit 1 = Minute

(markerOn? 0x4 : 0) | // bit 2 = Marqueur (multiple de 5)

(secOn ? 0x8 : 0); // bit 3 = Seconde cumulative

Ce masque permet de gérer les 16 combinaisons possibles de superposition avec une couleur dédiée pour chacune, sans jamais perdre d'information visuelle. Par exemple :

0x9 (Heure + Seconde) → Magenta le rouge de l'heure et le bleu de la seconde se combinent

0xF (tout allumé) → Blanc toutes les composantes fusionnent

Cette approche est bien plus propre qu'une série de conditions imbriquées et garantit une couleur cohérente pour chaque état possible de l'horloge.

### 4.1.10 Précision BME680

#### 4.1.10.1 Formule pour le calcul de la valeur du eCO2 en ppm

Précision : ±200 ppm

Pourquoi eCO2 et non CO2 ?

Dans ce projet, la valeur affichée est appelée eCO2 (équivalent CO₂) et non CO₂, car ces deux termes ne désignent pas la même chose.

Le CO₂ au sens strict est une mesure physique directe de la concentration de dioxyde de carbone dans l'air, exprimée en ppm. Cette mesure nécessite un capteur spécifique dit NDIR (Non-Dispersive InfraRed), qui utilise un faisceau infrarouge pour détecter précisément les molécules de CO₂. C'est le type de capteur présent dans les boîtiers de mesure des salles de classe du CPNV.

Le BME680, lui, ne mesure pas le CO₂ directement. Il mesure une résistance électrique exposée à l'air ambiant plus l'air contient de composés organiques volatils (COV), plus cette résistance chute. À partir de cette résistance, un modèle mathématique estime une valeur dite eCO2 : une approximation de la qualité de l'air exprimée dans la même unité que le CO₂ (ppm) pour faciliter la lecture, mais qui n'est pas une mesure certifiée de la concentration réelle en CO₂.

En résumé, le préfixe "e" signifie "équivalent" la valeur est calculée, estimée et relative, non mesurée directement. Elle est tout à fait suffisante pour détecter une dégradation de la qualité de l'air et déclencher une alerte visuelle, ce qui est précisément l'objectif de ce projet.

Etape 1 Lissage du gaz (gasFilteredOhm)

Formule utilisée à chaque nouvelle mesure :

gasFilteredOhm = gasFilteredOhm * 0.85 + envGasOhm * 0.15

- envGasOhm = mesure brute actuelle du capteur gaz (ex : 615759)
- gasFilteredOhm = ancienne valeur lissée (ex : 613865)
- Nouvelle gasFilteredOhm ≈ 613865*0.85 + 615759*0.15 = 614149

Etape 2 Baseline (gasBaselineOhm)

Au début :

- gasBaselineOhm = gasFilteredOhm

Ensuite :

- Si gasFilteredOhm > gasBaselineOhm pendant warmup:

gasBaselineOhm = gasBaselineOhm * 0.70 + gasFilteredOhm * 0.30

- Si gasFilteredOhm > gasBaselineOhm après warmup:

gasBaselineOhm = gasBaselineOhm * 0.95 + gasFilteredOhm * 0.05

- Sinon, gasBaselineOhm ne change pas.

Etape 3 Ratio

Ratio = gasBaselineOhm / gasFilteredOhm

Exemple avec tes valeurs :

- gasBaselineOhm = 676775
- gasFilteredOhm = 614149

Ratio = 676775 / 614149 = 1.10197

Puis on limite :

- Si Ratio < 0.5 => ratio = 0.5
- Si Ratio > 6.0 => ratio = 6.0

Etape 4 Calcul PPM principal

Ppm = 400 * pow(ratio, 5.0)

Avec ratio = 1.10197:

Ppm = 400 * 1.10197^5.0 ≈ 650

Etape 5 Correction humidité/température

Ppm = ppm + (envHumPct - 40.0) * 1.6

Ppm = ppm + (tempCompC - 22.0) * 3.0

Avec :

- envHumPct = 33.5 => (33.5-40)*1.6 = -10.4
- tempCompC = 22.9 => (22.9-22)*3.0 = +2.7

Donc :

Ppm ≈ 650 - 10.4 + 2.7 = 642.3

Etape 6 Limite finale

- Si ppm < 400 => ppm = 400
- Si ppm > 5000 => ppm = 5000

Ici : Ppm~642.

#### 4.1.10.2 Formule pour le calcul de la valeur de température

Précision : ±0.5 °C

En raison de la légère chaleur dégagée par le capteur ainsi que de la présence de nombreux câbles à proximité, j’ai dû soustraire une valeur fixe de 2,5 °C dans le code. Après plusieurs observations et tests, j’ai constaté qu’il s’agissait de l’écart moyen mesuré par rapport à la température réelle.

TempératureCapteur – 2.5°C = TempératureRéel

#### 4.1.10.3 Formule pour le calcul de la valeur de l’humidité en pourcentage

Précision : ±2 %

L’humidité n’a nécessité aucune adaptation ni compensation. Pour le projet

#### 4.1.10.4 Formule pour le calcul de la valeur de la pression atmosphérique en hecto Pascal

Précision : ???

En me basant sur les données météorologiques, les valeurs de pression atmosphérique ne semblent pas erronées. Cependant, ne disposant pas d’un capteur de pression atmosphérique à proximité, je n’ai pas pu comparer les mesures en direct afin de confirmer leur exactitude.

#### 4.1.10.5 Vérification de donnée

Pour ce chapitre, j’ai utilisé le Technoline WL 1030 comme compteur de CO₂, thermomètre et hygromètre. Par chance, celui-ci se trouvait à côté de moi durant toute la durée du projet.

Figure 35 photo du Technoline WL 1030 utiliser pour comparer les valeurs

## 4.2 Erreurs restantes

La seule erreur restante concerne actuellement le 4ᵉ quart de l’anneau Adafruit NeoPixel 1/4 60 Ring, qui s’est désolidarisé du 3ᵉ quart. Cela provoque parfois de faux contacts. Il est toutefois possible de le repositionner manuellement afin de le faire fonctionner à nouveau. Globalement, il faudrait améliorer les soudures sur l’ensemble de l’anneau, et pas uniquement sur le quatrième quart.

## 4.3 Liste des documents fournis

### 4.3.1 Code source

Fichier | Emplacement | Description
main.cpp | Code/src/ | Code source complet du projet
platformio.ini | Code/ | Configuration PlatformIO
README.md | Racine | Description générale du projet
.gitattributes | Racine | Configuration des attributs Git

### 4.3.2 Documentation

Fichier | Emplacement | Description
Documentation_TPI_Ryan-Bersier.docx | Documentation/Documentation/ | Rapport TPI complet version Word éditable
Documentation_TPI_Ryan-Bersier.pdf | Documentation/Documentation/ | Rapport TPI version PDF finale
Journal-de-Travail_TPI_Ryan-Bersier.xlsx | Documentation/Journal-de-travail/ | Journal de travail quotidien version Excel éditable
Journal-de-Travail_TPI_Ryan-Bersier.pdf | Documentation/Journal-de-travail/ | Journal de travail version PDF finale
Planification_TPI_Ryan-Bersier.xlsx | Documentation/Planning/ | Planning initial rempli version Excel
Planification_TPI_Ryan-Bersier.pdf | Documentation/Planning/ | Planning initial rempli version PDF
Planification_TPI_Ryan-Bersier-vide.xlsx | Documentation/Planning/ | Planning initial vierge version Excel
Planification_TPI_Ryan-Bersier-vide.pdf | Documentation/Planning/ | Planning initial vierge version PDF
Schema-electronique.fzz | Documentation/Schema/ | Schéma de câblage fichier source Fritzing
Diagramme-de-flux_TPI_Ryan-Bersier.drawio | Documentation/Schema/ | Diagramme de flux fichier source draw.io
20260519_135546.mp4 | Documentation/Video/Base/ | Vidéo brute de démonstration prise 1
20260519_141846.mp4 | Documentation/Video/Base/ | Vidéo brute de démonstration prise 2
20260519_142412.mp4 | Documentation/Video/Base/ | Vidéo brute de démonstration prise 3
Demonstration_TPI.mp4 | Documentation/Video/Démonstration/ | Vidéo de démonstration finale du projet montée
Demonstration_TPI_Max_Quality.txt | Documentation/Video/démonstrations/ | Lien vers la version haute qualité de la vidéo

### 4.3.3 Images et ressources graphiques

Fichier | Emplacement | | Description
29155.jpg à 29158.jpg | Image/Documentation/CDC/ | Photos du cahier des charges (4 pages)
Journal-de-Travail_TPI_Ryan-Bersier-images-0.jpg à -2.jpg | Image/Documentation/Journal_De_Travail/ | Captures d'écran du journal de travail (3 images)
Planification_TPI_Ryan-Bersier-vide-images-0.jpg à -6.jpg | Image/Documentation/Planning/initial/ | Captures d'écran du planning initial (7 images)
Planification_TPI_Ryan-Bersier-final-images-0.jpg à -6.jpg | Image/Documentation/Planning/final/ | Captures d'écran du planning final réel (7 images)
Schema-electronique_bb.png | Image/Documentation/Schema/ | Export PNG du schéma breadboard (Fritzing)
Schema-electronique_schéma.png | Image/Documentation/Schema/ | Export PNG du schéma électronique (Fritzing)
Diagramme-de-flux_TPI_Ryan-Bersier.drawio.png | Image/Documentation/Schema/ | Export PNG du diagramme de flux
Clion.svg.png | Image/Logiciel/ | Logo CLion
DaVinci_Resolve_Studio.png | Image/Logiciel/ | Logo DaVinci Resolve Studio (montage vidéo)
draw-io.webp | Image/Logiciel/ | Logo draw.io
git.jpeg | Image/Logiciel/ | Logo Git et GitHub
office.jpg | Image/Logiciel/ | Logo Microsoft Office
PlateformIO.png | Image/Logiciel/ | Logo PlatformIO
PC.webp | Image/Materiel/ | Photo du PC CPNV Dell OptiPlex 7000
1296_1756x2209.webp | Image/Materiel/ | Photo du capteur Technoline WL 1030
Média__6_-removebg-preview.png | Image/Materiel/ | Photo des boutons matériel
Photo_horloge_final.png | Image/Materiel/ | Photo de l'horloge assemblée et fonctionnelle
Untitled (1).png à Untitled (7).png | Image/Materiel/ | Photos des composants du projet (7 images)

# 5 Tests

## 5.1 Tests de communication I²C

Tag | Nom du test | Description du test | Réaction attendue | Réaction du test | État
T-COM-01 | Détection du BME680 | Vérifier que le capteur BME680 est détecté sur le bus I²C via un scanner I²C. | Le périphérique répond à l’adresse 0x76 sans erreur. | Le BME680 est correctement détecté à l’adresse 0x76. | OK
T-COM-02 | Détection du RTC DS1307 | Vérifier la présence du module RTC sur le bus I²C. | Le module RTC répond à l’adresse 0x68. | Le DS1307 est détecté et répond correctement. | OK
T-COM-03 | Détection du HT16K33 | Vérifier que l’afficheur alphanumérique répond sur le bus I²C. | L’afficheur répond à l’adresse 0x70. | Le HT16K33 est détecté sans erreur. | OK
T-COM-04 | Fonctionnement simultané I²C | Vérifier que les trois composants I²C fonctionnent simultanément sans conflit. | Aucun conflit d’adresse ni perte de communication. | Les trois composants communiquent correctement ensemble. | OK
T-COM-05 | Reconnexion après redémarrage | Vérifier la reconnexion automatique des périphériques après redémarrage de l’Arduino. | Tous les périphériques sont redétectés automatiquement. | Les composants sont de nouveau détectés après reboot. | OK

## 5.2 Tests du module RTC DS1307

Tag | Nom du test | Description du test | Réaction attendue | Réaction du test | État
T-RTC-01 | Lecture de l’heure | Vérifier la lecture correcte de l’heure depuis le RTC. | L’heure affichée correspond à l’heure configurée. | L’heure retournée est correcte. | OK
T-RTC-02 | Conservation de l’heure hors tension | Débrancher l’alimentation puis redémarrer le système. | L’heure reste correcte grâce à la pile CR1220. | L’heure est conservée après coupure. | OK
T-RTC-03 | Réglage manuel de l’heure | Modifier l’heure via les boutons poussoirs. | L’heure du RTC est mise à jour correctement. | Le changement d’heure fonctionne correctement. | OK
T-RTC-04 | Dérive temporelle | Comparer l’heure RTC à une horloge de référence après plusieurs minutes. | La dérive reste faible et acceptable. | Sa dérive dépend presque entièrement : - Du quartz 32.768 kHz utilisé, - De la température, - Du PCB/layout, - De la capacité de charge du quartz. Dérive souvent observée :2 à 10 secondes par jour | ~OK

## 5.3 Tests du capteur environnemental BME680

Tag | Nom du test | Description du test | Réaction attendue | Réaction du test | État
T-BME-01 | Lecture température | Vérifier la lecture de la température ambiante. | La température affichée est cohérente avec la pièce. | Valeur cohérente observée. | OK
T-BME-02 | Lecture humidité | Vérifier la lecture du taux d’humidité. | L’humidité affichée reste stable et plausible. | Valeur cohérente observée. | OK
T-BME-03 | Lecture pression atmosphérique | Vérifier la lecture de la pression atmosphérique. | La pression retournée est stable. | Pression correctement affichée. | OK
T-BME-04 | Lecture qualité de l’air | Vérifier la lecture des valeurs de gaz/COV. | Une valeur eCO2/PPM~ est calculée et affichée. | Les valeurs sont calculées correctement après stabilisation. | OK
T-BME-05 | Stabilisation du capteur | Observer les mesures après mise sous tension. | Les valeurs deviennent stables après quelques minutes. | Stabilisation correcte observée. | OK
T-BME-06 | Capteur débranché | Débrancher le BME680 pendant le fonctionnement. | Le système ne plante pas et signale l’erreur. | Le système continue de fonctionner sans crash. | OK

## 5.4 Tests de l’affichage HT16K33

Tag | Nom du test | Description du test | Réaction attendue | Réaction du test | État
T-DSP-01 | Affichage des caractères | Vérifier l’affichage de texte sur les 4 digits. | Les caractères sont correctement affichés. | Affichage lisible et stable. | OK
T-DSP-02 | Rotation automatique des pages | Vérifier le changement automatique des informations affichées. | Les pages changent toutes les 10 secondes. | Rotation correctement exécutée. | OK
T-DSP-03 | Affichage des TAGS | Vérifier l’affichage des TAGS avant les valeurs. | Les TAGS apparaissent correctement avant les données. | Fonctionnement conforme. | OK
T-DSP-04 | Réactivité affichage configuration | Vérifier l’affichage pendant le mode configuration. | Le champ édité est affiché immédiatement. | Réactivité correcte observée. | OK

## 5.5 Tests de l’anneau NeoPixel

Tag | Nom du test | Description du test | Réaction attendue | Réaction du test | État
T-LED-01 | Allumage séquentiel des LEDs | Vérifier l’allumage des 60 LEDs une par une. | Toutes les LEDs s’allument correctement. | Les LEDs fonctionnent correctement sauf faux contact occasionnel sur le dernier quart. | ~OK
T-LED-02 | Affichage des heures | Vérifier l’aiguille des heures en rouge. | L’heure est représentée correctement. | Affichage conforme. | OK
T-LED-03 | Affichage des minutes | Vérifier l’aiguille des minutes en vert. | Les minutes sont affichées correctement. | Fonctionnement correct. | OK
T-LED-04 | Affichage des secondes | Vérifier la progression bleue des secondes. | Les secondes progressent correctement sur l’anneau. | Progression correcte observée. | OK
T-LED-05 | Gestion des superpositions | Vérifier les couleurs lors des recouvrements d’aiguilles. | Les couleurs combinées sont correctement affichées. | Les superpositions fonctionnent correctement. | OK
T-LED-06 | Réglage luminosité | Vérifier les différents niveaux de luminosité. | La luminosité change selon les réglages utilisateur. | Les niveaux de luminosité fonctionnent correctement. | OK
T-LED-07 | Mode alerte qualité d’air | Simuler un dépassement du seuil eCO2. | L’anneau clignote rapidement en rouge. | Le mode alerte fonctionne correctement. | OK

## 5.6 Tests des boutons poussoirs

Tag | Nom du test | Description du test | Réaction attendue | Réaction du test | État
T-BTN-01 | Détection appui bouton | Vérifier qu’un appui est détecté correctement. | Chaque pression déclenche une action unique. | Fonctionnement correct observé. | OK
T-BTN-02 | Détection relâchement | Vérifier le relâchement des boutons. | Le relâchement est détecté sans erreur. | Fonctionnement conforme. | OK
T-BTN-03 | Antirebond logiciel | Maintenir et appuyer rapidement sur les boutons. | Aucun double déclenchement parasite. | Le debounce fonctionne correctement. | OK
T-BTN-04 | Changement de mode | Vérifier le bouton de changement d’affichage. | Le mode change correctement. | Fonctionnement conforme. | OK
T-BTN-05 | Désactivation alerte | Tester le bouton de désactivation temporaire de l’alerte. | L’alerte visuelle est désactivée temporairement. | Fonctionnement correct. | OK

## 5.7 Tests d’intégration globale

Tag | Nom du test | Description du test | Réaction attendue | Réaction du test | État
T-INT-01 | Fonctionnement complet du système | Tester tous les modules simultanément. | Aucun conflit ni ralentissement majeur. | Le système fonctionne correctement dans son ensemble. | OK
T-INT-02 | Mise à jour non bloquante | Vérifier l’absence de blocage dans la loop(). | Toutes les tâches restent réactives simultanément. | Le système reste fluide sans utilisation de delay(). | OK
T-INT-03 | Fonctionnement prolongé | Laisser tourner le système plusieurs heures. | Le système reste stable sans crash. | Aucun crash observé. | OK
T-INT-04 | Consommation électrique | Vérifier le comportement à forte luminosité. | La consommation reste maîtrisée. | La limitation logicielle de luminosité évite les surcharges USB. | OK

## 5.8 Tests de robustesse et cas limites

Tag | Nom du test | Description du test | Réaction attendue | Réaction du test | État
T-ROB-01 | Coupure alimentation | Couper puis rétablir l’alimentation du système. | Le système redémarre correctement. | Redémarrage correct observé. | OK
T-ROB-02 | Appui prolongé bouton | Maintenir un bouton appuyé plusieurs secondes. | Aucun comportement erratique. | Fonctionnement stable observé. | OK
T-ROB-03 | Déconnexion composant I²C | Débrancher un périphérique I²C pendant l’exécution. | Le système reste stable malgré l’erreur. | Aucun crash observé. | OK
T-ROB-04 | Faux contact NeoPixel | Manipuler légèrement le 4e quart de l’anneau LED. | Le système continue de fonctionner correctement. | Des faux contacts apparaissent parfois sur le dernier quart à cause des brasures. | ~OK
T-ROB-05 | Redémarrage logiciel | Rebooter l’Arduino après fonctionnement prolongé. | Le système retrouve son état normal automatiquement. | Fonctionnement correct après reboot. | OK

# 6 Conclusions

## 6.1 Objectifs atteints / non-atteints

L'ensemble des six objectifs définis dans le cahier des charges a été atteint.

L'affichage de l'heure en temps réel fonctionne correctement sur l'anneau de 60 LED NeoPixel, avec une représentation analogique des heures, minutes et secondes par des couleurs distinctes et une gestion propre des superpositions. Le module RTC DS1307 assure la persistance de l'heure même après coupure de courant.

La mesure et l'affichage des données environnementales sont opérationnels : le capteur BME680 fournit la température, l'humidité, la pression atmosphérique et une estimation eCO2 de la qualité de l'air. Ces valeurs s'affichent en rotation automatique sur le HT16K33, précédées de leurs tags d'identification.

Le système d'alerte visuelle fonctionne : lorsque l'estimation eCO2 dépasse 1000 ppm, l'anneau bascule en mode clignotement rouge intense, immédiatement visible. L'alerte peut être supprimée manuellement et se réarme automatiquement dès que la qualité de l'air s'améliore.

L'interaction utilisateur via les six boutons poussoirs est entièrement fonctionnelle, avec gestion du rebond logiciel, mode de configuration heure/date, changement de page, réglage de luminosité et désactivation de l'alerte.

Le code est structuré en six modules fonctionnels distincts, commenté en détail et versionné quotidiennement sur GitHub conformément aux exigences.

La documentation est complète : rapport de projet, journal de travail, planification, schémas électroniques et diagrammes de flux sont tous produits et livrés.

Un seul point reste imparfait : le quatrième quart de l'anneau NeoPixel présente des faux contacts liés à la qualité des brasures. Le système reste fonctionnel mais ce point mécanique aurait mérité plus de soin.

## 6.2 Points positifs / négatifs
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

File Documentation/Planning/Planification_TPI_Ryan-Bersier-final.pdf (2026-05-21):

Tranches de 15 minutes · Période : 23.04.2026 – 21.05.2026 · Chef de projet : Raphaël Favre · ⚠ Fériés : 14 & 15 mai

## Planification Initiale du projet TPI — Horloge à LED avec capteurs — Ryan BERSIER

N° | Titre de la tâche | H prév. | H réel.
1 | 2 | 3 | 4 | 5 | 6 | 7 | 8 | 1 | 2 | 3 | 4 | 5 | 6 | 7 | 8 | 1 | 2 | 3
:00 | :15 | :30 | :45 | :00 | :15 | :30 | :45 | :00 | :15 | :30 | :45 | :00 | :15 | :30 | :45 | :00 | :15 | :30 | :45 | :00 | :15 | :30 | :45 | :00 | :15 | :30 | :45 | :00 | :15 | :30 | :45 | :00 | :15 | :30 | :45 | :00 | :15 | :30 | :45 | :00 | :15 | :30 | :45 | :00 | :15 | :30 | :45 | :00 | :15 | :30 | :45 | :00 | :15 | :30 | :45 | :00 | :15 | :30 | :45 | :00 | :15 | :30 | :45 | :00 | :15 | :30 | :45 | :00 | :15 | :30 | :45 | :00 | :15 | :30 | :45 | :00 | :15 | :30 | :45 | :00 | :15 | :30 | :45 | :00 | :15 | :30 | :45 | :00 | :15 | :30 | :45 | :00 | :15 | :30 | :45
1 | Analyse préliminaire | 11.25h | 9.25h
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

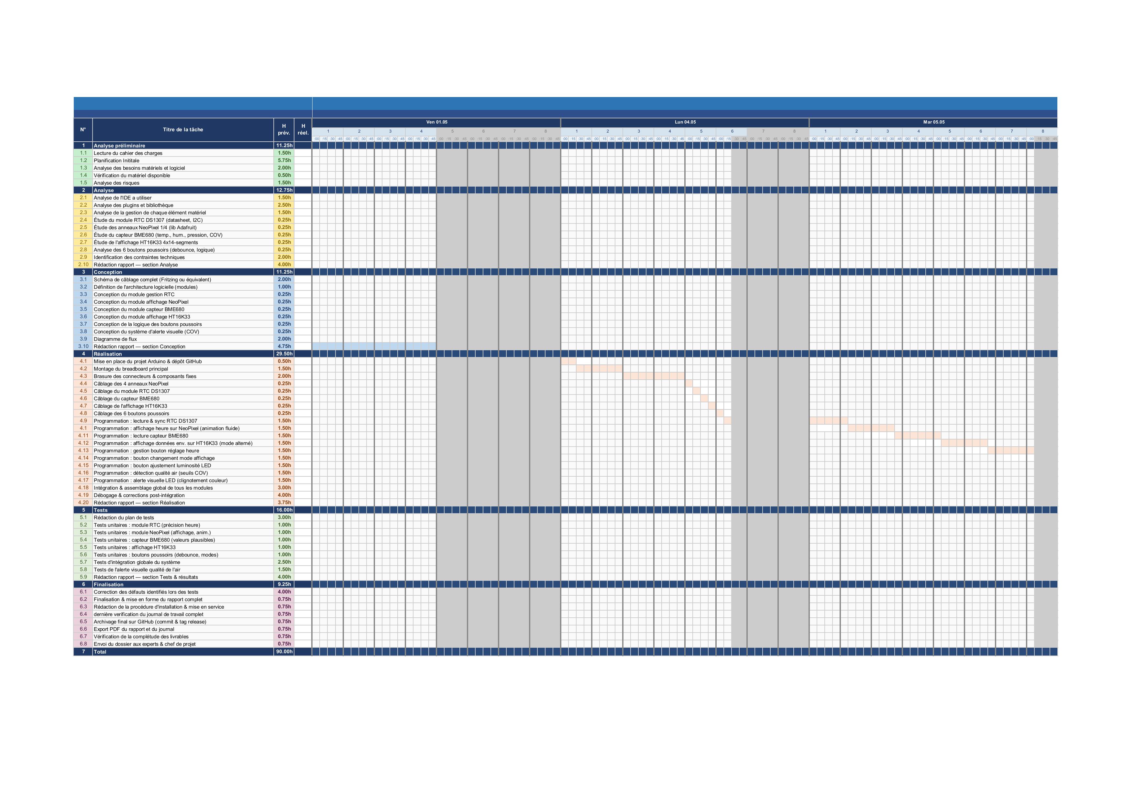
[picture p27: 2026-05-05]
Image/Documentation/Planning/initial/Planification_TPI_Ryan-Bersier-vide-images-2.jpg

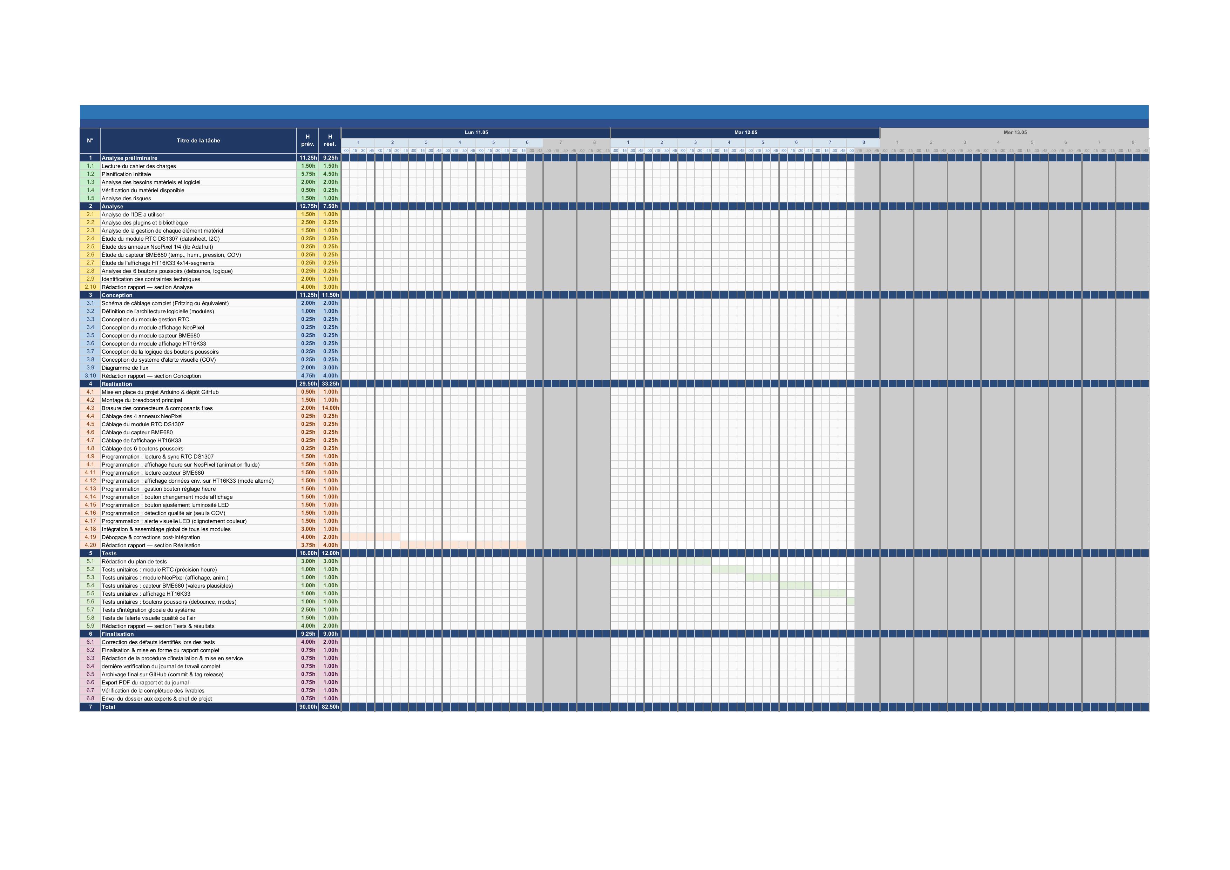
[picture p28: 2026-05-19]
Image/Documentation/Planning/final/Planification_TPI_Ryan-Bersier-final-images-4.jpg

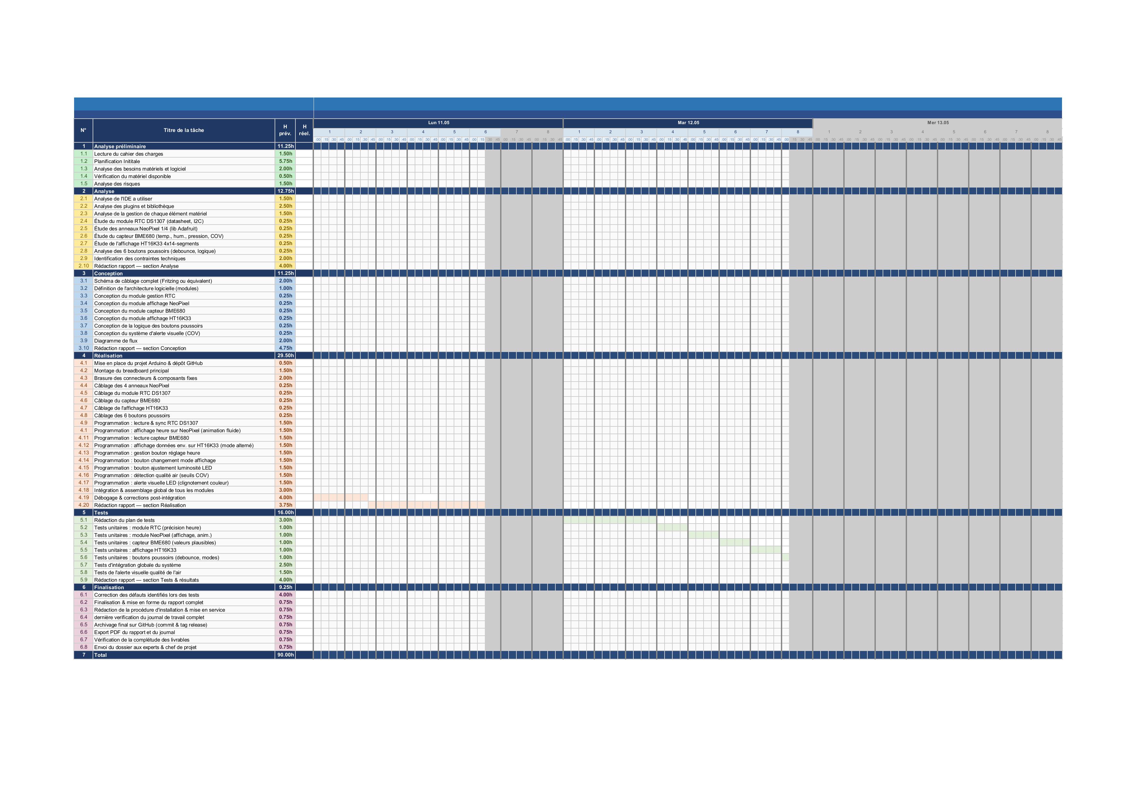
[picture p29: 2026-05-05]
Image/Documentation/Planning/initial/Planification_TPI_Ryan-Bersier-vide-images-4.jpg

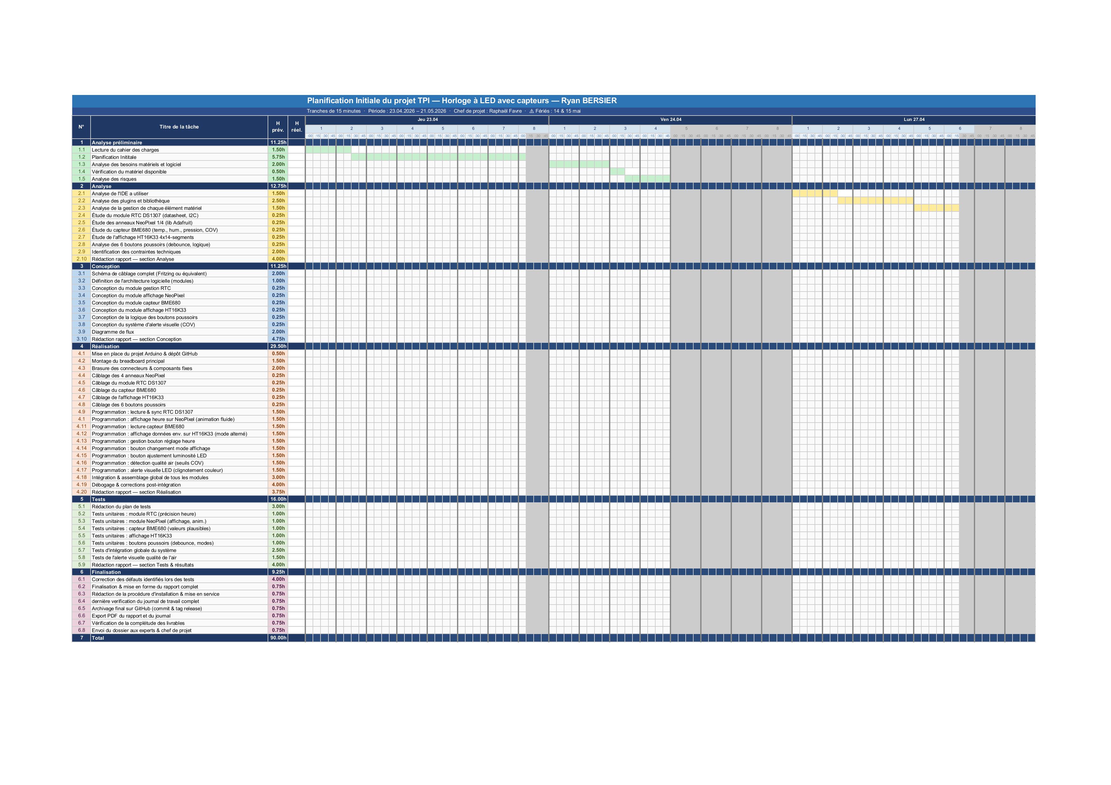
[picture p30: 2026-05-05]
Image/Documentation/Planning/initial/Planification_TPI_Ryan-Bersier-vide-images-0.jpg

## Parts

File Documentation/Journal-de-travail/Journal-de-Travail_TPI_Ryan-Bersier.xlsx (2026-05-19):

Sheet: Journal
Jour | Semaine | Temps [h] | Type | Description | Remarques / Problèmes / Ressources
2026-04-23 | 1 | 1.50 | Autre | Meeting avec M. Suleyman CERAN + Lecture et validation du CDC | Rencontre avec M. Suleyman CERAN (Expert 1) reception du cahier des charge ainsi que de la grille d'evaluation lectur attentive, questions, appel de M Raphaël Favre (chef de projet) pour éclaircir certains point du TPI et savaoir ou se trouve le materiel du TPI
2026-04-23 | 1 | 0.50 | Documentation | Création du fichier Excel de planifiation initiale | Fichier créer + design apporté pour la relecture
2026-04-23 | 1 | 2.00 | Documentation | Création de la liste des différentes tâche de chaque catégorie | Liste des tâche a réaliser durant le projet a voir avec le chef de projet si correct ou non
2026-04-23 | 1 | 2.00 | Documentation | Estimation de temps pour chacune des tâche | Estimation du temps pour chaque tâche et répartion des heure pour former 90h de projet
2026-04-23 | 1 | 1.25 | Documentation | Création du Journal de travail et de la documentation du projet | Création du journal de travail et remplissage puis création de la documentation de la page de garde, des style de rédaction et en-tete et pied de page
2026-04-24 | 1 | 2.00 | Analyse | Analyse des besoins matériels et logiciel | recherche sur internet pour redaction dans la documentation du materiel et logiciel a disposition et de a quoi il sert
2026-04-24 | 1 | 0.25 | Analyse | Verification du materiel disponible | Contrôle que je dispose de tout le nécessaire
2026-04-24 | 1 | 1.00 | Analyse | Analyse des risques | Redaction dans la documentation des risques leur niveau et leur mesure préventives
2026-04-24 | 1 | 0.50 | Documentation | intégration de la planification initial dans la documentation | intégration dans la doc (Saut de section, changement d'orientation ,mise en page des en-tete et pied de page en paysage, découpe de la planification sur plusieurs page)
2026-04-24 | 1 | 0.25 | Autre | Rendu 2 au chef de projet et aux 2 Expert | Mise a jour des fichier PDF, Rédaction du mail et envoi
2026-04-27 | 2 | 1.00 | Analyse | Analyse de l'IDE à utiliser | Comparaison entre clions, arduino IDE et VS code
2026-04-27 | 2 | 0.25 | Analyse | Analyse des plugins et bibliothèque | Comprendre a quoi elle servent + ce qui est possible
2026-04-27 | 2 | 1.00 | Analyse | Analyse de la gestion de chaque élément matériel | Comment chaque élément intéragisse entre eux
2026-04-27 | 2 | 1.25 | Analyse | Etude de chaque éléments éléctronique | A quoi vont servir chaque éléement dans le projet et leurs alternative
2026-04-27 | 2 | 1.00 | Analyse | Identification des contraintes techniques | Quel seront les point de blocage
2026-04-27 | 2 | 1.00 | Documentation | Rédaction rapport — section Analyse | Remise au propre des notes dans la documentation, reformulation de phrase, présentation dans la documentation et complément d'information
2026-04-28 | 2 | 1.00 | Documentation | Rédaction rapport — section Analyse | Remise au propre des notes dans la documentation, reformulation de phrase, présentation dans la documentation et complément d'information
2026-04-28 | 2 | 2.00 | Conception | Schéma de câblage complet | Téléchargement et installation de fritzing (version anterieur car nouvelle version payante) ajout via des library disponible sur github des élément éléctronique du projet ou équivalent
2026-04-28 | 2 | 1.00 | Documentation | Rédaction rapport — section Conception (stratégie de test)
2026-04-28 | 2 | 1.00 | Réalisation | Création de l'environement de travail et création du repository | création l'environement sur Clion avec Plateformio (plusieurs installation) + création du répository et upload de tous les fichier du dossier local de l'analyse et de la conception
2026-04-28 | 2 | 2.00 | Réalisation | Brasure des éléments éléctronique | J'ai pu braser les éléments j'ai eu juste un soucis de brasure avec le ring. 2 pistes se sont arracher pendant que j'essayais de en réarranger la brasure selon un autre enseignant M. Favre pourrais reussir a réavoir les 2 éléments
2026-04-28 | 2 | 0.25 | Autre | Rendu 3 au chef de projet et aux 2 Expert | Mise a jour des fichier PDF, Rédaction du mail et envoi
2026-04-30 | 2 | 1.25 | Réalisation | Montage de tous les composant sur la bread board avec l'arduino | Sauf le ring
2026-04-30 | 2 | 2.00 | Réalisation | Brasure du ring cassé pour tester
2026-04-30 | 2 | 1.00 | Réalisation | Programmation pour test | Programmation assisté par IA juste pour les test afin de diagnostiquer les porblème le plutôt possible
2026-04-30 | 2 | 3.00 | Tests | Effectue les test et comprendre les soucis | Teste de tous les éléments et essai de ressoudre ou de comprendre pourquoi cela ne fonctionne pas j'ai pu ainsi faire fonctionner le BME680, j'ai découvert que le RTC DS1307 ne pouvais pas fonctionner sans pile donc impossible de le tester pour le moment, les bouton fonctionne sans aucun problème avec l'anti-bounce, l'affichage 14 segment a 1 segement mort sur chacun des 2 premier digit et le ring ne fonctionne toujours pas
2026-05-01 | 2 | 1.00 | Autre | Discussion avec Chef de projet | Discussion avec M.Favre : - Ring mort ou alors voir avec lui pour la réparation : M. Favre a fourni 2 nouveau quart de ring qui étais mort - Affichage 14 segments sur les 2 premier caractère la bar verticale en bas a droite ne s'allume pas : M. Favre va fournir un nouveau 14 segment prochainement eet analyser de son coté pourquoi celui-ci a 2 segement cassé - Documentation conception : M. Favre est d'accord que j'avance sur la réalisation surtout en temps de test de fonctionnement - pile CR1220 : M. Favre va fournir une pile lundi il n'avais pas prévu cet eventualité et vu que c'est un format très spécifique nous en avons pas en stock - Retour projet : M. Favre n'a pas eu le temps de lire la doc nous prendrons le temps Lundi
2026-05-01 | 2 | 2.00 | Réalisation | Brasure du ring avec les nouveau quart en remplacement
2026-05-01 | 2 | 0.50 | Tests | Test du ring | quelque complication durant le test mais maintenant 1/2 du ring s'allume
2026-05-01 | 2 | 0.50 | Autre | Rendu 4 au chef de projet et aux 2 Expert | Mise a jour des fichier PDF, Actualisation du Repository et Rédaction du mail et envoi
2026-05-04 | 3 | 1.00 | Tests | Test du ring | test encore le ring pour savoir qu'est-ce qui ne vas pas pour qu'il s'allume entièrement (il s'agissait d'un faux contact un des fil de cuivre que j'avais placé entre 2 quart ne touchait pas le deuxième quart je l'ai donc plier pour faire en sorte que sa soit toujours le cas maintenant)
2026-05-04 | 3 | 1.00 | Tests | Test du module RTC DS1307 | M. Favre m'a donner la pile manquante et maintenant le module de gestion de date et heure fonctionne
2026-05-04 | 3 | 1.00 | Réalisation | Brassage du nouveau 14 segment | M. Favre m'a donner un nouveau 14 segement vu que sur l'ancien 2 segment étais mort la seule différence avec l'ancien c'est que l'affichage est passé de vert à bleu
2026-05-04 | 3 | 1.00 | Autre | retour avec M. Favre concernant la documentation | point d'amélioration discuter : table des matière trop longue donc max titre 2 / Date d'impression au pied de page / Nom des experts sur la page de garde / page de garde pas noir / Retravailler les schéma de façon plus pro et mieux visuellement / Pas de canva dans la documentation / inviter tout le monde sur github facilite l'accès / rajouter un chapitre objectif personnel / pas de titre sur 2 lignes / éloigné les caractère de la numérotation pour la lecture / legende sous les images / améliorer le planing initial et PDF et celui dans la doc pour que sur le côté on voit toutes les taches / passer le journal de travail en paysage et définir une zone d'impression / Arboressences a retravailler un peu
2026-05-04 | 3 | 1.50 | Documentation | début de corrections sur les retours de M. Favre | partie 1 a reprendre demain
2026-05-05 | 3 | 3.50 | Documentation | fin de corrections sur les retours de M. Favre | Partie 2 tous les point précedement cité ont été fait il faut simplement que je revois M. Favre pour lui demander si les titre hors table des matière donc plus que titre 2 doivent aussi être sur une seule ligne ou c'est moins important
2026-05-05 | 3 | 0.50 | Autre | Recherche concernant le calcul pour les PPM à partir du COV | recherche sur internet pour le calcul pour obtenir le PPM (unité du CO2) à partir du COV (unité en gaz ressistance) vu que le BME est incapable de mesurer le PPM par lui-même
2026-05-05 | 3 | 2.75 | Réalisation | Programmation pour l'affichage et le ring | Durant l'après-midi programmation pour l'affichage ainsi que le calcul du PPM qui a fonctionner assez rapidement et programmation du ring qui a encore quelque soucis de scintillement et les seconde se reset la version n'étant pas entièrement fonctionnel je préfère ne pas push si gros bug ou quelque chose qui ne fonctionne pas Jeudi je vais devoir avancer pour faire en sorte que le ring fonctionne avec le capteur RTC DS1307 et programmer les bouton
2026-05-05 | 3 | 0.50 | Autre | Rendu 5 au chef de projet et aux 2 Expert | Mise a jour des fichier PDF, Actualisation du Repository et Rédaction du mail et envoi
2026-05-07 | 3 | 4.00 | Réalisation | Programmation | avancement pour faire en sorte que le ring fonctionne avec le capteur RTC DS1307 et programmer les bouton aussi rework de l'affichage sur le 14 segement et du BME680 + ajout de fonctionnalité bonus avec les boutons
2026-05-07 | 3 | 2.00 | Réalisation | Débogage | concernant le BME680 qui est un module très imprécis -2.5°C, Ensuite le CO2 qui étais calculé de façon imprécise du genre quand on étais à 1200 ppm le capteur disait que l'on étais à 500 ppm depuis corriger mais reste imprécis a environ 100 ppm minimum et maximum
2026-05-07 | 3 | 1.25 | Conception | Définition de l'architecture logiciel | Documentation de la définition de l'architecture logiciel
2026-05-08 | 3 | 1.00 | Réalisation | Caclul du PPM | Documentation du calcul utilisé pour le PPM actuelle
2026-05-08 | 3 | 2.50 | Conception | Diagramme de flux | Complétion entière du diagramme de flux
2026-05-08 | 3 | 0.50 | Autre | Rendu 6 au chef de projet et aux 2 Expert | Mise a jour des fichier PDF, Actualisation du Repository et Rédaction du mail et envoi
2026-05-11 | 4 | 4.00 | Documentation | Rédaction rapport — section Conception
2026-05-11 | 4 | 1.50 | Documentation | Rédaction rapport — section Réalisation | pas fini
2026-05-12 | 4 | 2.50 | Documentation | Rédaction rapport — section Réalisation
2026-05-12 | 4 | 0.50 | Autre | Visite Expert 2 | M. Graf est venu me rendre visite nous avons pu faire un check up complet de ce qui est fait et a faire et il a pu constater l'avancement
2026-05-12 | 4 | 4.00 | Documentation | Rédaction rapport — section Tests & résultats | Les test ayant déjà été effectuer au par avant seul la rédaction d'un plan de test et sa completion restais encore a être rediger dans la doc
2026-05-12 | 4 | 0.25 | Autre | Rendu 7 au chef de projet et aux 2 Expert | Mise a jour des fichier PDF, Actualisation du Repository et Rédaction du mail et envoi
2026-05-18 | 5 | 3.00 | Documentation | Rédaction rapport — section Conclusion
2026-05-18 | 5 | 1.00 | Autre | retour avec M. Favre concernant la documentation et le projet | point d'amélioration discuter : Image centrer / Baseline mieux expliquer / Relecture par cœur de la documentation pendant la période de la préparation à la défense / Revoir le diagramme de flux pour que chaque bloque est une suite / Magenta pas le même dans le tableau des couleur de superposition / T-RTC04 quantité déritative / Date impression à la place de la date du jour / Schéma couleur de câble normé et bme au dessus sur la platine d'essai
2026-05-18 | 5 | 1.50 | Documentation | Rédaction rapport — section Annexe | pas fini
2026-05-19 | 5 | 1.50 | Documentation | Rédaction rapport — section Annexe | fini
2026-05-19 | 5 | 0.50 | Analyse | Script de la vidéo démonstration
2026-05-19 | 5 | 0.50 | Réalisation | Enregistrement de la démonstration + prise photo pour la page de garde
2026-05-19 | 5 | 2.00 | Autre | Montage vidéo pour rendre la vidéo moins longue et plus dynamique
2026-05-19 | 5 | 2.00 | Documentation | début de corrections sur les retours de M. Favre | partie 1 a reprendre jeudi
2026-05-19 | 5 | 0.75 | Autre | Rendu 8 au chef de projet et aux 2 Expert | Mise a jour des fichier PDF, Actualisation du Repository et Rédaction du mail et envoi
2026-05-21 | 5 | 2.00 | Documentation | fin de corrections sur les retours de M. Favre | Partie 2 tous les point précedement cité ont été fait
2026-05-21 | 5 | 3.25 | Autre | Dernière verification de la documentation, Impression et rendu par mail
Total |  | 90.00

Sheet: Stats
Type | Temps [h]
Analyse | 8.25
Conception | 5.75
Réalisation | 20.50
Tests | 5.50
Documentation | 36.25
Administratif | 0.00
Absence | 0.00
Autre | 13.75

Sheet: Listes
Analyse
Conception
Réalisation
Tests
Documentation
Administratif
Absence
Autre

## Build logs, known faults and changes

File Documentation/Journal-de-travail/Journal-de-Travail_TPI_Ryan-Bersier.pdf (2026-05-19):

Jour | Semaine | Temps [h] | Type | Description | Remarques / Problèmes / Ressources
jeudi, 23 avril 2026 | 1 | 1.50 | Autre | Meeting avec M. Suleyman CERAN + Lecture et validation du CDC | Rencontre avec M. Suleyman CERAN (Expert 1) reception du cahier des charge ainsi que
| | | | | de la grille d'evaluation lectur attentive, questions, appel de M Raphaël Favre (chef de
| | | | | projet) pour éclaircir certains point du TPI et savaoir ou se trouve le materiel du TPI
jeudi, 23 avril 2026 | 1 | 0.50 | Documentation | Création du fichier Excel de planifiation initiale | Fichier créer + design apporté pour la relecture
jeudi, 23 avril 2026 | 1 | 2.00 | Documentation | Création de la liste des différentes tâche de chaque catégorie | Liste des tâche a réaliser durant le projet a voir avec le chef de projet si correct ou non
jeudi, 23 avril 2026 | 1 | 2.00 | Documentation | Estimation de temps pour chacune des tâche | Estimation du temps pour chaque tâche et répartion des heure pour former 90h de
| | | | | projet
jeudi, 23 avril 2026 | 1 | 1.25 | Documentation | Création du Journal de travail et de la documentation du projet | Création du journal de travail et remplissage puis création de la documentation de la
| | | | | page de garde, des style de rédaction et en-tete et pied de page
vendredi, 24 avril 2026 | 1 | 2.00 | Analyse | Analyse des besoins matériels et logiciel | recherche sur internet pour redaction dans la documentation du materiel et logiciel a
| | | | | disposition et de a quoi il sert
vendredi, 24 avril 2026 | 1 | 0.25 | Analyse | Verification du materiel disponible | Contrôle que je dispose de tout le nécessaire
vendredi, 24 avril 2026 | 1 | 1.00 | Analyse | Analyse des risques | Redaction dans la documentation des risques leur niveau et leur mesure préventives
vendredi, 24 avril 2026 | 1 | 0.50 | Documentation | intégration de la planification initial dans la documentation | intégration dans la doc (Saut de section, changement d'orientation ,mise en page des
| | | | | en-tete et pied de page en paysage, découpe de la planification sur plusieurs page)
vendredi, 24 avril 2026 | 1 | 0.25 | Autre | Rendu 2 au chef de projet et aux 2 Expert | Mise a jour des fichier PDF, Rédaction du mail et envoi
lundi, 27 avril 2026 | 2 | 1.00 | Analyse | Analyse de l'IDE à utiliser | Comparaison entre clions, arduino IDE et VS code
lundi, 27 avril 2026 | 2 | 0.25 | Analyse | Analyse des plugins et bibliothèque | Comprendre a quoi elle servent + ce qui est possible
lundi, 27 avril 2026 | 2 | 1.00 | Analyse | Analyse de la gestion de chaque élément matériel | Comment chaque élément intéragisse entre eux
lundi, 27 avril 2026 | 2 | 1.25 | Analyse | Etude de chaque éléments éléctronique | A quoi vont servir chaque éléement dans le projet et leurs alternative
lundi, 27 avril 2026 | 2 | 1.00 | Analyse | Identification des contraintes techniques | Quel seront les point de blocage
lundi, 27 avril 2026 | 2 | 1.00 | Documentation | Rédaction rapport — section Analyse | Remise au propre des notes dans la documentation, reformulation de phrase,
| | | | | présentation dans la documentation et complément d'information
mardi, 28 avril 2026 | 2 | 1.00 | Documentation | Rédaction rapport — section Analyse | Remise au propre des notes dans la documentation, reformulation de phrase,
| | | | | présentation dans la documentation et complément d'information
mardi, 28 avril 2026 | 2 | 2.00 | Conception | Schéma de câblage complet | Téléchargement et installation de fritzing (version anterieur car nouvelle version payante)
| | | | | ajout via des library disponible sur github des élément éléctronique du projet ou
| | | | | équivalent
mardi, 28 avril 2026 | 2 | 1.00 | Documentation | Rédaction rapport — section Conception (stratégie de test)
mardi, 28 avril 2026 | 2 | 1.00 | Réalisation | Création de l'environement de travail et création du repository | création l'environement sur Clion avec Plateformio (plusieurs installation) + création du
| | | | | répository et upload de tous les fichier du dossier local de l'analyse et de la conception
mardi, 28 avril 2026 | 2 | 2.00 | Réalisation | Brasure des éléments éléctronique | J'ai pu braser les éléments j'ai eu juste un soucis de brasure avec le ring. 2 pistes se sont
| | | | | arracher pendant que j'essayais de en réarranger la brasure selon un autre enseignant
M. Favre pourrais reussir a réavoir les 2 éléments
mardi, 28 avril 2026 | 2 | 0.25 | Autre | Rendu 3 au chef de projet et aux 2 Expert | Mise a jour des fichier PDF, Rédaction du mail et envoi
jeudi, 30 avril 2026 | 2 | 1.25 | Réalisation | Montage de tous les composant sur la bread board avec l'arduino | Sauf le ring
jeudi, 30 avril 2026 | 2 | 2.00 | Réalisation | Brasure du ring cassé pour tester
jeudi, 30 avril 2026 | 2 | 1.00 | Réalisation | Programmation pour test | Programmation assisté par IA juste pour les test afin de diagnostiquer les porblème le
| | | | | plutôt possible
jeudi, 30 avril 2026 | 2 | 3.00 | Tests | Effectue les test et comprendre les soucis

Teste de tous les éléments et essai de ressoudre ou de comprendre pourquoi cela ne fonctionne pas j'ai pu ainsi faire fonctionner le BME680, j'ai découvert que le RTC DS1307 ne pouvais pas fonctionner sans pile donc impossible de le tester pour le moment, les bouton fonctionne sans aucun problème avec l'anti-bounce, l'affichage 14 segment a 1 segement mort sur chacun des 2 premier digit et le ring ne fonctionne toujours pas

Jour | Semaine | Temps [h] | Type | Description | Remarques / Problèmes / Ressources
vendredi, 1 mai 2026 | 2 | 1.00 | Autre | Discussion avec Chef de projet | Discussion avec M.Favre :
- Ring mort ou alors voir avec lui pour la réparation : M. Favre a fourni 2 nouveau quart
| | | | | de ring qui étais mort
- Affichage 14 segments sur les 2 premier caractère la bar verticale en bas a droite ne
| | | | | s'allume pas : M. Favre va fournir un nouveau 14 segment prochainement eet analyser de son coté pourquoi celui-ci a 2 segement cassé
- Documentation conception : M. Favre est d'accord que j'avance sur la réalisation
| | | | | surtout en temps de test de fonctionnement
- pile CR1220 : M. Favre va fournir une pile lundi il n'avais pas prévu cet eventualité et vu
| | | | | que c'est un format très spécifique nous en avons pas en stock
- Retour projet : M. Favre n'a pas eu le temps de lire la doc nous prendrons le temps Lundi
vendredi, 1 mai 2026 | 2 | 2.00 | Réalisation | Brasure du ring avec les nouveau quart en remplacement
vendredi, 1 mai 2026 | 2 | 0.50 | Tests | Test du ring | quelque complication durant le test mais maintenant 1/2 du ring s'allume
vendredi, 1 mai 2026 | 2 | 0.50 | Autre | Rendu 4 au chef de projet et aux 2 Expert | Mise a jour des fichier PDF, Actualisation du Repository et Rédaction du mail et envoi
lundi, 4 mai 2026 | 3 | 1.00 | Tests | Test du ring | test encore le ring pour savoir qu'est-ce qui ne vas pas pour qu'il s'allume entièrement (il
| | | | | s'agissait d'un faux contact un des fil de cuivre que j'avais placé entre 2 quart ne
| | | | | touchait pas le deuxième quart je l'ai donc plier pour faire en sorte que sa soit toujours le
| | | | | cas maintenant)
lundi, 4 mai 2026 | 3 | 1.00 | Tests | Test du module RTC DS1307 | M. Favre m'a donner la pile manquante et maintenant le module de gestion de date et
| | | | | heure fonctionne
lundi, 4 mai 2026 | 3 | 1.00 | Réalisation | Brassage du nouveau 14 segment | M. Favre m'a donner un nouveau 14 segement vu que sur l'ancien 2 segment étais mort
| | | | | la seule différence avec l'ancien c'est que l'affichage est passé de vert à bleu
lundi, 4 mai 2026 | 3 | 1.00 | Autre | retour avec M. Favre concernant la documentation | point d'amélioration discuter :
| | | | | table des matière trop longue donc max titre 2 / Date d'impression au pied de page / Nom des experts sur la page de garde / page de garde pas noir / Retravailler les schéma de façon plus pro et mieux visuellement / Pas de canva dans la documentation / inviter tout le monde sur github facilite l'accès / rajouter un chapitre objectif personnel / pas de titre sur 2 lignes / éloigné les caractère de la numérotation pour la lecture / legende sous les images / améliorer le planing initial et PDF et celui dans la doc pour que sur le côté on voit toutes les taches / passer le journal de travail en paysage et définir une zone d'impression / Arboressences a retravailler un peu
lundi, 4 mai 2026 | 3 | 1.50 | Documentation | début de corrections sur les retours de M. Favre | partie 1 a reprendre demain
mardi, 5 mai 2026 | 3 | 3.50 | Documentation | fin de corrections sur les retours de M. Favre | Partie 2 tous les point précedement cité ont été fait il faut simplement que je revois M. Favre pour lui demander si les titre hors table des matière donc plus que titre 2 doivent aussi être sur une seule ligne ou c'est moins important
mardi, 5 mai 2026 | 3 | 0.50 | Autre | Recherche concernant le calcul pour les PPM à partir du COV | recherche sur internet pour le calcul pour obtenir le PPM (unité du CO2) à partir du COV (unité en gaz ressistance) vu que le BME est incapable de mesurer le PPM par lui-même
mardi, 5 mai 2026 | 3 | 2.75 | Réalisation | Programmation pour l'affichage et le ring | Durant l'après-midi programmation pour l'affichage ainsi que le calcul du PPM qui a fonctionner assez rapidement et programmation du ring qui a encore quelque soucis de scintillement et les seconde se reset la version n'étant pas entièrement fonctionnel je préfère ne pas push si gros bug ou quelque chose qui ne fonctionne pas Jeudi je vais devoir avancer pour faire en sorte que le ring fonctionne avec le capteur RTC DS1307 et programmer les bouton
mardi, 5 mai 2026 | 3 | 0.50 | Autre | Rendu 5 au chef de projet et aux 2 Expert | Mise a jour des fichier PDF, Actualisation du Repository et Rédaction du mail et envoi
jeudi, 7 mai 2026 | 3 | 4.00 | Réalisation | Programmation | avancement pour faire en sorte que le ring fonctionne avec le capteur RTC DS1307 et programmer les bouton aussi rework de l'affichage sur le 14 segement et du BME680 + ajout de fonctionnalité bonus avec les boutons
jeudi, 7 mai 2026 | 3 | 2.00 | Réalisation | Débogage | concernant le BME680 qui est un module très imprécis -2.5°C, Ensuite le CO2 qui étais calculé de façon imprécise du genre quand on étais à 1200 ppm le capteur disait que l'on étais à 500 ppm depuis corriger mais reste imprécis a environ 100 ppm minimum et maximum
jeudi, 7 mai 2026 | 3 | 1.25 | Conception | Définition de l'architecture logiciel | Documentation de la définition de l'architecture logiciel
vendredi, 8 mai 2026 | 3 | 1.00 | Réalisation | Caclul du PPM | Documentation du calcul utilisé pour le PPM actuelle

Jour | Semaine | Temps [h] | Type | Description | Remarques / Problèmes / Ressources
vendredi, 8 mai 2026 | 3 | 2.50 | Conception | Diagramme de flux | Complétion entière du diagramme de flux
vendredi, 8 mai 2026 | 3 | 0.50 | Autre | Rendu 6 au chef de projet et aux 2 Expert | Mise a jour des fichier PDF, Actualisation du Repository et Rédaction du mail et envoi
lundi, 11 mai 2026 | 4 | 4.00 | Documentation | Rédaction rapport — section Conception
lundi, 11 mai 2026 | 4 | 1.50 | Documentation | Rédaction rapport — section Réalisation | pas fini
mardi, 12 mai 2026 | 4 | 2.50 | Documentation | Rédaction rapport — section Réalisation
mardi, 12 mai 2026 | 4 | 0.50 | Autre | Visite Expert 2 | M. Graf est venu me rendre visite nous avons pu faire un check up complet de ce qui est
| | | | | fait et a faire et il a pu constater l'avancement
mardi, 12 mai 2026 | 4 | 4.00 | Documentation | Rédaction rapport — section Tests & résultats | Les test ayant déjà été effectuer au par avant seul la rédaction d'un plan de test et sa
| | | | | completion restais encore a être rediger dans la doc
mardi, 12 mai 2026 | 4 | 0.25 | Autre | Rendu 7 au chef de projet et aux 2 Expert | Mise a jour des fichier PDF, Actualisation du Repository et Rédaction du mail et envoi
lundi, 18 mai 2026 | 5 | 3.00 | Documentation | Rédaction rapport — section Conclusion
lundi, 18 mai 2026 | 5 | 1.00 | Autre | retour avec M. Favre concernant la documentation et le projet | point d'amélioration discuter :
| | | | | Image centrer / Baseline mieux expliquer / Relecture par cœur de la documentation pendant la période de la préparation à la défense / Revoir le diagramme de flux pour que chaque bloque est une suite / Magenta pas le même dans le tableau des couleur de superposition / T-RTC04 quantité déritative / Date impression à la place de la date du jour / Schéma couleur de câble normé et bme au dessus sur la platine d'essai
lundi, 18 mai 2026 | 5 | 1.50 | Documentation | Rédaction rapport — section Annexe | pas fini
mardi, 19 mai 2026 | 5 | 1.50 | Documentation | Rédaction rapport — section Annexe | fini
mardi, 19 mai 2026 | 5 | 0.50 | Analyse | Script de la vidéo démonstration
mardi, 19 mai 2026 | 5 | 0.50 | Réalisation | Enregistrement de la démonstration + prise photo pour la page de garde
mardi, 19 mai 2026 | 5 | 2.00 | Autre | Montage vidéo pour rendre la vidéo moins longue et plus dynamique
mardi, 19 mai 2026 | 5 | 2.00 | Documentation | début de corrections sur les retours de M. Favre | partie 1 a reprendre jeudi
mardi, 19 mai 2026 | 5 | 0.75 | Autre | Rendu 8 au chef de projet et aux 2 Expert | Mise a jour des fichier PDF, Actualisation du Repository et Rédaction du mail et envoi

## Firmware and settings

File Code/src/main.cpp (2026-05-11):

/*
  ============================================================
  TPI 2026 - Horloge LED avec capteurs environnementaux
  Auteur: Ryan Bersier
  Fichier: main.cpp
  ============================================================

  Objectif du programme:
  - Afficher l'heure via RTC DS1307 sur un ring NeoPixel 60 LEDs
  - Lire l'environnement via BME680 (T/H/P + estimation PPM)
  - Afficher les donnees sur un afficheur 4x14 segments HT16K33
  - Gerer 6 boutons pour configuration, affichage, luminosite, alerte

  Materiel:
  - Arduino UNO Rev3
  - RTC DS1307 (I2C)
  - BME680 (I2C, adresse 0x76)
  - HT16K33 4x14 segments (I2C, adresse 0x70)
  - Ring NeoPixel WS2812 60 LEDs (DIN sur D6)
  - Boutons sur D2, D3, D4, D5, D7, D8

  Notes importantes:
  - Le BME680 avec la librairie Adafruit renvoie une resistance de gaz.
    Ici, on en deduit une estimation simple de "PPM" pour respecter
    le cahier des charges. Ce n'est pas une mesure CO2 absolue certifiee.
  - Tous les boutons sont en INPUT_PULLUP: appui = LOW.
*/

#include <Arduino.h>
#include <Wire.h>
#include <RTClib.h>
#include <Adafruit_BME680.h>
#include <Adafruit_LEDBackpack.h>
#include <Adafruit_NeoPixel.h>

// ============================================================
// Mapping materiel (broches)
// ============================================================
static const uint8_t PIN_BTN_MENU = 2;   // D2
static const uint8_t PIN_BTN_UP = 3;     // D3
static const uint8_t PIN_BTN_DOWN = 4;   // D4
static const uint8_t PIN_BTN_NEXT = 5;   // D5
static const uint8_t PIN_RING = 6;       // D6
static const uint8_t PIN_BTN_BRIGHT = 7; // D7
static const uint8_t PIN_BTN_ALERT = 8;  // D8

static const uint8_t BTN_PINS[6] = {
  PIN_BTN_MENU, PIN_BTN_UP, PIN_BTN_DOWN, PIN_BTN_NEXT, PIN_BTN_BRIGHT, PIN_BTN_ALERT
};

// Constantes de temporisation et taille du ring
static const uint8_t RING_LED_COUNT = 60;
static const uint16_t DEBOUNCE_MS = 40;
static const uint32_t ENV_READ_MS = 2000;
static const uint32_t DISPLAY_ROTATE_MS = 10000;
static const float TEMP_OFFSET_C = -2.5f;
// Duree d'affichage d'un TAG (TEMP/HUMD/...) avant la valeur.
static const uint16_t TAG_DISPLAY_MS = 600;
// Remarque: toutes les temporisations utilisent millis() (non bloquant).

// ============================================================
// Objets librairies
// ============================================================
RTC_DS1307 rtc;
Adafruit_BME680 bme;
Adafruit_AlphaNum4 alpha4;
Adafruit_NeoPixel ring(RING_LED_COUNT, PIN_RING, NEO_GRB + NEO_KHZ800);

// ============================================================
// Gestion des boutons (anti-rebond logiciel)
// ============================================================
bool btnStableState[6] = {HIGH, HIGH, HIGH, HIGH, HIGH, HIGH};
bool btnLastReading[6] = {HIGH, HIGH, HIGH, HIGH, HIGH, HIGH};
uint32_t btnLastChangeMs[6] = {0, 0, 0, 0, 0, 0};
bool btnPressedEvent[6] = {false, false, false, false, false, false};

// ============================================================
// Donnees environnementales mises en cache
// ============================================================
float tempRawC = 0.0f;
float tempCompC = 0.0f;
float envHumPct = 0.0f;
float envPressureHpa = 0.0f;
uint32_t envGasOhm = 0;
int envPpmEstimate = 400;
uint32_t lastEnvReadMs = 0;
uint32_t lastEnvSuccessMs = 0;
uint8_t envFailCount = 0;
bool envValid = false;
float gasBaselineOhm = 0.0f;
bool gasBaselineValid = false;
float gasFilteredOhm = 0.0f;
bool gasFilterValid = false;
uint32_t baselineStartMs = 0;

// ============================================================
// Gestion des pages affichees sur le 14-segments
// ============================================================
enum DisplayItem : uint8_t {
  DISP_AIR = 0,
  DISP_TEMP = 1,
  DISP_HUM = 2,
  DISP_ATMO = 3,
  DISP_DATE = 4,
  DISP_COUNT = 5
};
DisplayItem currentDisplayItem = DISP_AIR;
uint32_t lastDisplaySwitchMs = 0;
bool showTagForCurrentItem = true;
bool tagDisplayActive = false;
uint32_t tagDisplayUntilMs = 0;
// showTagForCurrentItem: affiche le TAG au prochain rendu de page.
// tagDisplayActive/tagDisplayUntilMs: fenetre non bloquante du TAG.

// ============================================================
// Mode configuration horaire/date
// ============================================================
bool configMode = false;
uint8_t configField = 0; // 0=day,1=month,2=hour,3=min,4=sec
int cfgHour = 0;
int cfgMinute = 0;
int cfgSecond = 0;
int cfgDay = 1;
int cfgMonth = 1;
int cfgYear = 2026;

// ============================================================
// Comportement visuel de l'anneau
// ============================================================
uint8_t brightnessStep = 0; // 0=100,1=75,2=50,3=25 (version limitee pour stabilite)
const uint8_t brightnessValues[4] = {100, 75, 50, 25};

// Intensites LED reduites pour eviter scintillement/corruption data due au courant.
const uint8_t COL_R = 100;
const uint8_t COL_G = 100;
const uint8_t COL_B = 100;

bool alertSuppressed = false;
int lastRenderedSecond = -1;
int lastRenderedMinute = -1;
int lastRenderedHour = -1;
bool lastRenderedAlertOn = false;
uint32_t alertBlinkPhase = 0;

static inline uint8_t daysInMonth(int month, int year) {
  // Renvoie le nombre de jours du mois en tenant compte des annees bissextiles.
  if (month == 2) {
    bool leap = ((year % 4 == 0) && (year % 100 != 0)) || (year % 400 == 0);
    return leap ? 29 : 28;
  }
  if (month == 4 || month == 6 || month == 9 || month == 11) return 30;
  return 31;
}

void display4(const char *txt) {
  // Affiche exactement 4 caracteres (ou espaces) sur le HT16K33.
  // Exemple: "TEMP", "1234", "----"
  alpha4.clear();
  for (uint8_t i = 0; i < 4; i++) {
    char c = txt[i] ? txt[i] : ' ';
    alpha4.writeDigitAscii(i, c);
  }
  alpha4.writeDisplay();
}

void displayNumber4(int value) {
  // Formate un entier sur 4 caracteres (aligne a droite).
  // Exemple: 42 devient "  42"
  char buf[5];
  snprintf(buf, sizeof(buf), "%4d", value);
  display4(buf);
}

void displayTemp(float tempC) {
  // Affiche la temperature sous la forme XX.XC (ex: 23.4C).
  int scaled = (int)round(tempC * 10.0f);
  int absScaled = abs(scaled);
  int tens = absScaled / 10;
  int tenths = absScaled % 10;

  alpha4.clear();
  if (scaled < 0) {
    alpha4.writeDigitAscii(0, '-');
    alpha4.writeDigitAscii(1, (char)('0' + (tens % 10)), true);
  } else {
    alpha4.writeDigitAscii(0, (char)('0' + ((tens / 10) % 10)));
    alpha4.writeDigitAscii(1, (char)('0' + (tens % 10)), true);
  }
  alpha4.writeDigitAscii(2, (char)('0' + tenths));
  alpha4.writeDigitAscii(3, 'C');
  alpha4.writeDisplay();
}

void displayHumidity(float hum) {
  // Affiche l'humidite sous la forme XX.X%
  int scaled = (int)round(hum * 10.0f);
  int tens = scaled / 10;
  int tenths = abs(scaled % 10);

  alpha4.clear();
  alpha4.writeDigitAscii(0, (char)('0' + ((tens / 10) % 10)));
  alpha4.writeDigitAscii(1, (char)('0' + (tens % 10)), true);
  alpha4.writeDigitAscii(2, (char)('0' + tenths));
  alpha4.writeDigitAscii(3, '%');
  alpha4.writeDisplay();
}

void displayDateDDMM(const DateTime &now) {
  // Affiche la date au format DD.MM (point via decimal point).
  static uint8_t lastValidDay = 1;
  static uint8_t lastValidMonth = 1;

  uint8_t day = now.day();
  uint8_t month = now.month();

  // Protection contre les lectures transitoires invalides (ex: 00.00).
  if (day >= 1 && day <= 31 && month >= 1 && month <= 12) {
    lastValidDay = day;
    lastValidMonth = month;
  } else {
    day = lastValidDay;
    month = lastValidMonth;
  }

  alpha4.clear();
  alpha4.writeDigitAscii(0, (char)('0' + (day / 10)));
  alpha4.writeDigitAscii(1, (char)('0' + (day % 10)), true);
  alpha4.writeDigitAscii(2, (char)('0' + (month / 10)));
  alpha4.writeDigitAscii(3, (char)('0' + (month % 10)));
  alpha4.writeDisplay();
}

void showTagThenValue(const char *tag) {
  // Affiche le TAG (ex: TEMP) sans bloquer la boucle principale.
  // Le TAG reste visible pendant TAG_DISPLAY_MS puis la valeur prend la suite.
  display4(tag);
  tagDisplayActive = true;
  tagDisplayUntilMs = millis() + TAG_DISPLAY_MS;
}

int estimatePpmFromGasModel(float gasOhmFiltered, float gasOhmBaseline, float tempC, float humPct) {
  // Heuristique eCO2:
  // - ratio gaz baseline / gaz courant
  // - conversion non-lineaire pour mieux suivre les degradations
  // - compensation temperature/humidite a faible amplitude
  // Cette valeur est une estimation relative (pas une mesure CO2 NDIR absolue).
  if (gasOhmFiltered <= 1.0f || gasOhmBaseline <= 1.0f) return 400;

  // ratio > 1.0 => air plus charge qu'au niveau "propre" de baseline.
  float ratio = gasOhmBaseline / gasOhmFiltered;
  if (ratio < 0.5f) ratio = 0.5f;
  if (ratio > 6.0f) ratio = 6.0f;
  // Bornes de securite pour eviter les extremes numeriques.

  // Courbe non-lineaire plus sensible:
  // eCO2 ~= 400 * ratio^k avec k ajuste pour mieux suivre les hausses marquées.
  // Ex: ratio 1.25 donne environ ~1150 ppm.
  // k regle la sensibilite globale de la courbe PPM~.
  const float k = 5.0f;
  float ppm = 400.0f * powf(ratio, k);

  // Compensation T/H moderee (on garde un impact faible).
  ppm += (humPct - 40.0f) * 1.6f;
  ppm += (tempC - 22.0f) * 3.0f;

  if (ppm < 400.0f) ppm = 400.0f;
  if (ppm > 5000.0f) ppm = 5000.0f;
  return (int)round(ppm);
}

void updateButtons() {
  // Lit les boutons avec debounce et genere des evenements "front descendant".
  // INPUT_PULLUP: LOW = appui, HIGH = relache.
  uint32_t nowMs = millis();
  for (uint8_t i = 0; i < 6; i++) {
    bool reading = digitalRead(BTN_PINS[i]);
    if (reading != btnLastReading[i]) {
      // Changement brut detecte: restart fenetre anti-rebond.
      btnLastChangeMs[i] = nowMs;
      btnLastReading[i] = reading;
    }

    if ((nowMs - btnLastChangeMs[i]) > DEBOUNCE_MS) {
      if (btnStableState[i] != reading) {
        btnStableState[i] = reading;
        if (btnStableState[i] == LOW) {
          btnPressedEvent[i] = true;
        }
      }
    }
  }
}

bool consumePress(uint8_t idx) {
  // Consomme un evenement d'appui unique (une fois par clic).
  // Retourne true uniquement une fois par pression.
  if (!btnPressedEvent[idx]) return false;
  btnPressedEvent[idx] = false;
  return true;
}

void loadConfigFromRtc(const DateTime &now) {
  // Copie l'heure RTC courante dans les variables de configuration.
  cfgYear = now.year();
  cfgMonth = now.month();
  cfgDay = now.day();
  cfgHour = now.hour();
  cfgMinute = now.minute();
  cfgSecond = now.second();
}

void applyConfigToRtc() {
  // Ecrit les valeurs configurees dans le module RTC.
  uint8_t maxDay = daysInMonth(cfgMonth, cfgYear);
  if (cfgDay > maxDay) cfgDay = maxDay;
  rtc.adjust(DateTime(cfgYear, cfgMonth, cfgDay, cfgHour, cfgMinute, cfgSecond));
}

void displayConfigField() {
  // Affiche le champ en cours de reglage:
  // DD--, MM--, HH--, --MM, SS--
  alpha4.clear();
  switch (configField) {
    case 0: { // DD--
      alpha4.writeDigitAscii(0, (char)('0' + (cfgDay / 10)));
      alpha4.writeDigitAscii(1, (char)('0' + (cfgDay % 10)));
      alpha4.writeDigitAscii(2, '-');
      alpha4.writeDigitAscii(3, '-');
      break;
    }
    case 1: { // MM--
      alpha4.writeDigitAscii(0, (char)('0' + (cfgMonth / 10)));
      alpha4.writeDigitAscii(1, (char)('0' + (cfgMonth % 10)));
      alpha4.writeDigitAscii(2, '-');
      alpha4.writeDigitAscii(3, '-');
      break;
    }
    case 2: { // HH--
      alpha4.writeDigitAscii(0, (char)('0' + (cfgHour / 10)));
      alpha4.writeDigitAscii(1, (char)('0' + (cfgHour % 10)));
      alpha4.writeDigitAscii(2, '-');
      alpha4.writeDigitAscii(3, '-');
      break;
    }
    case 3: { // --MM
      alpha4.writeDigitAscii(0, '-');
      alpha4.writeDigitAscii(1, '-');
      alpha4.writeDigitAscii(2, (char)('0' + (cfgMinute / 10)));
      alpha4.writeDigitAscii(3, (char)('0' + (cfgMinute % 10)));
      break;
    }
    case 4: { // SS--
      alpha4.writeDigitAscii(0, (char)('0' + (cfgSecond / 10)));
      alpha4.writeDigitAscii(1, (char)('0' + (cfgSecond % 10)));
      alpha4.writeDigitAscii(2, '-');
      alpha4.writeDigitAscii(3, '-');
      break;
    }
  }
  alpha4.writeDisplay();
}

void updateEnvironmentRead() {
  // Fait une lecture BME680 periodique (toutes les ENV_READ_MS).
  // Cette fonction met a jour toutes les variables "env*".
  uint32_t nowMs = millis();
  if (nowMs - lastEnvReadMs < ENV_READ_MS) return;
  lastEnvReadMs = nowMs;

  if (!bme.performReading()) {
    // Si plusieurs lectures consecutives echouent, on reinitialise le BME680.
    envFailCount++;
    if (envFailCount >= 3) {
      bool ok = bme.begin(0x76);
      if (ok) {
        bme.setTemperatureOversampling(BME680_OS_8X);
        bme.setHumidityOversampling(BME680_OS_2X);
        bme.setPressureOversampling(BME680_OS_4X);
        bme.setIIRFilterSize(BME680_FILTER_SIZE_3);
        bme.setGasHeater(320, 150);
      }
      envValid = false;
      envFailCount = 0;
    }
    return;
  }

  envFailCount = 0;
  lastEnvSuccessMs = nowMs;
  envValid = true;

  tempRawC = bme.temperature;
  tempCompC = tempRawC + TEMP_OFFSET_C;
  envHumPct = bme.humidity;
  envPressureHpa = bme.pressure / 100.0f;
  envGasOhm = bme.gas_resistance;

  // 1) Filtrage du signal gaz (anti-bruit)
  // Plus stable visuellement et numeriquement qu'une mesure brute.
  if (!gasFilterValid) {
    gasFilteredOhm = (float)envGasOhm;
    gasFilterValid = true;
  } else {
    gasFilteredOhm = (gasFilteredOhm * 0.85f) + ((float)envGasOhm * 0.15f);
  }

  // 2) Baseline adaptative "air propre observe"
  //    - Warmup: pendant ~3 min, on construit une baseline stable
  //    - Ensuite: baseline ne redescend plus (evite la chute artificielle des PPM)
  //    - Elle ne monte que si un air meilleur est observe.
  if (!gasBaselineValid) {
    gasBaselineOhm = gasFilteredOhm;
    gasBaselineValid = true;
  } else {
    uint32_t ageMs = millis() - baselineStartMs;
    if (ageMs < 180000UL) {
      // Warmup: suit plus vite les meilleures valeurs observees.
      if (gasFilteredOhm > gasBaselineOhm) {
        gasBaselineOhm = (gasBaselineOhm * 0.70f) + (gasFilteredOhm * 0.30f);
      }
    } else {
      // Regime normal: baseline monotone (pas de derive descendante).
      // On accepte uniquement les mises a jour vers le haut.
      if (gasFilteredOhm > gasBaselineOhm) {
        gasBaselineOhm = (gasBaselineOhm * 0.95f) + (gasFilteredOhm * 0.05f);
      }
    }
  }

  // 3) Estimation eCO2
  // Le resultat est ensuite utilise pour l'affichage et le seuil d'alerte.
  envPpmEstimate = estimatePpmFromGasModel(gasFilteredOhm, gasBaselineOhm, tempCompC, envHumPct);

  // Si l'air redevient bon, on rearme l'alerte.
  if (envPpmEstimate < 1000) {
    alertSuppressed = false;
  }
}

void renderRingClock(const DateTime &now) {
  // Melanges explicites avec masque de bits:
  // bit0=heure, bit1=minute, bit2=marqueur blanc, bit3=seconde
  uint8_t hourPos = (uint8_t)((now.hour() % 12) * 5);
  uint8_t minPos = (uint8_t)now.minute();
  uint8_t sec = (uint8_t)now.second();

  ring.clear();
  for (uint8_t i = 0; i < RING_LED_COUNT; i++) {
    bool hourOn = (i == hourPos);
    bool minOn = (i == minPos);
    bool markerOn = ((i % 5) == 0);
    bool secOn = (i <= sec);

    uint8_t mask = (hourOn ? 0x1 : 0) |
                   (minOn ? 0x2 : 0) |
                   (markerOn ? 0x4 : 0) |
                   (secOn ? 0x8 : 0);

    switch (mask) {
      case 0x0: break;                                               // rien
      case 0x1: ring.setPixelColor(i, ring.Color(COL_R, 0, 0)); break;          // H
      case 0x2: ring.setPixelColor(i, ring.Color(0, COL_G, 0)); break;          // M
      case 0x4: ring.setPixelColor(i, ring.Color(35, 35, 35)); break;            // W (blanc faible)
      case 0x8: ring.setPixelColor(i, ring.Color(0, 0, COL_B)); break;          // S

      case 0x3: ring.setPixelColor(i, ring.Color(COL_R, COL_G, 0)); break;      // H+M = jaune
      case 0x5: ring.setPixelColor(i, ring.Color(COL_R, 0, 0)); break;          // H+W = rouge
      case 0x9: ring.setPixelColor(i, ring.Color(COL_R, 0, COL_B)); break;      // H+S = magenta
      case 0x6: ring.setPixelColor(i, ring.Color(40, 170, 55)); break;           // M+W = vert clair (moins blanc)
      case 0xA: ring.setPixelColor(i, ring.Color(0, 110, 35)); break;           // M+S = cyan-vert
      case 0xC: ring.setPixelColor(i, ring.Color(40, 60, 170)); break;           // W+S = bleu clair (moins blanc)

      case 0x7: ring.setPixelColor(i, ring.Color(COL_R, COL_G, 0)); break;      // H+M+W = jaune
      case 0xB: ring.setPixelColor(i, ring.Color(COL_R, COL_G, COL_B)); break;  // H+M+S = blanc
      case 0xD: ring.setPixelColor(i, ring.Color(COL_R, 0, COL_B)); break;      // H+W+S = magenta (melange H+S conserve)
      case 0xE: ring.setPixelColor(i, ring.Color(35, 170, 95)); break;           // M+S+W = cyan-vert clair (moins blanc)
      case 0xF: ring.setPixelColor(i, ring.Color(COL_R, COL_G, COL_B)); break;  // H+M+S+W = blanc

      default: break;
    }
  }

  ring.show();
}

void renderRingAlertBlink() {
  // Alerte visuelle: ring entier rouge clignotant ON/OFF chaque seconde.
  bool on = ((millis() / 200UL) % 2UL) == 0UL;
  ring.setBrightness(255);
  if (on) {
    for (uint8_t i = 0; i < RING_LED_COUNT; i++) {
      ring.setPixelColor(i, ring.Color(255, 0, 0));
    }
  } else {
    ring.clear();
  }
  ring.show();
}

bool shouldRenderRing(const DateTime &now, bool alertActive) {
  if (alertActive) {
    uint32_t phase = (millis() / 200UL) % 2UL;
    if (phase != alertBlinkPhase) {
      alertBlinkPhase = phase;
      return true;
    }
    return false;
  }

  if (lastRenderedSecond != now.second() ||
      lastRenderedMinute != now.minute() ||
      lastRenderedHour != now.hour()) {
    lastRenderedSecond = now.second();
    lastRenderedMinute = now.minute();
    lastRenderedHour = now.hour();
    lastRenderedAlertOn = false;
    ring.setBrightness(brightnessValues[brightnessStep]);
    return true;
  }

  return false;
}

void updateDisplay(const DateTime &now) {
  // En mode config: afficher uniquement le champ de reglage.
  if (configMode) {
    displayConfigField();
    return;
  }

  // En mode normal: rotation automatique toutes les 10s.
  // A chaque changement de page, on montre d'abord le TAG.
  uint32_t nowMs = millis();
  if ((nowMs - lastDisplaySwitchMs) >= DISPLAY_ROTATE_MS) {
    lastDisplaySwitchMs = nowMs;
    currentDisplayItem = (DisplayItem)((currentDisplayItem + 1) % DISP_COUNT);
    showTagForCurrentItem = true;
    tagDisplayActive = false;
  }

  // Si un TAG est en cours d'affichage, on attend sa fin (non bloquant).
  // return ici evite d'ecraser le TAG avec la valeur dans le meme tour.
  if (tagDisplayActive) {
    if ((int32_t)(nowMs - tagDisplayUntilMs) < 0) {
      return;
    }
    tagDisplayActive = false;
  }

  switch (currentDisplayItem) {
    // Chaque case suit le meme schema:
    // 1) TAG
    // 2) valeur
    case DISP_AIR:
      if (showTagForCurrentItem) {
        // TAG puis valeur au tour suivant.
        showTagThenValue("eCO2");
        showTagForCurrentItem = false;
        return;
      }
      if (envValid) displayNumber4(envPpmEstimate);
      else display4("----");
      break;
    case DISP_TEMP:
      if (showTagForCurrentItem) {
        showTagThenValue("TEMP");
        showTagForCurrentItem = false;
        return;
      }
      displayTemp(tempCompC);
      break;
    case DISP_HUM:
      if (showTagForCurrentItem) {
        showTagThenValue("HUMD");
        showTagForCurrentItem = false;
        return;
      }
      displayHumidity(envHumPct);
      break;
    case DISP_ATMO:
      if (showTagForCurrentItem) {
        showTagThenValue("ATMO");
        showTagForCurrentItem = false;
        return;
      }
      if (envValid) displayNumber4((int)round(envPressureHpa));
      else display4("----");
      break;
    case DISP_DATE:
      if (showTagForCurrentItem) {
        showTagThenValue("DATE");
        showTagForCurrentItem = false;
        return;
      }
      displayDateDDMM(now);
      break;
    default:
      display4("----");
      break;
  }
}

void onMenuButton(const DateTime &now) {
  // D2:
  // - entree mode config
  // - validation champ suivant
  // - sortie mode config apres le mois
  if (!configMode) {
    configMode = true;
    configField = 0;
    loadConfigFromRtc(now);
    return;
  }

  if (configField < 4) {
    configField++;
  } else {
    applyConfigToRtc();
    configMode = false;
    configField = 0;
    lastDisplaySwitchMs = millis();
    showTagForCurrentItem = true;
    tagDisplayActive = false;
  }
}
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
void loop() {
  // Boucle principale non bloquante (sauf petit delay de stabilite).
  updateButtons();
  DateTime now = rtc.now();

  handleButtons(now);
  updateEnvironmentRead();
  updateDisplay(now);

  bool alertActive = (!configMode) && (envPpmEstimate >= 1000) && (!alertSuppressed);
  if (shouldRenderRing(now, alertActive)) {
    if (alertActive) {
      renderRingAlertBlink();
    } else {
      renderRingClock(now);
    }
  }

  delay(10);
}

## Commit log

2026-04-28 commit the documentation change 2
    commit the documentation change 2
    [Journal-de-Travail_TPI_Ryan-Bersier.xlsx, Planification_TPI_Ryan-Bersier.xlsx]
2026-05-01 Push for the 4rd checkup with th work of Thursday and Friday
    [Journal-de-Travail_TPI_Ryan-Bersier.xlsx, Planification_TPI_Ryan-Bersier.xlsx]
2026-05-05 documentation and trees are updated
    [Journal-de-Travail_TPI_Ryan-Bersier.xlsx, Planification_TPI_Ryan-Bersier-vide.xlsx, Planification_TPI_Ryan-Bersier.xlsx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]
2026-05-05 Documentation update to rendered
    [Journal-de-Travail_TPI_Ryan-Bersier.xlsx, Planification_TPI_Ryan-Bersier.xlsx]
2026-05-07 Devloppement was finish
    [Journal-de-Travail_TPI_Ryan-Bersier.xlsx]
2026-05-07 bug correction for the date when the ring was in alert
    [main.cpp]
2026-05-08 Documentation with the flux diagramme and formule for the CO2
    [Journal-de-Travail_TPI_Ryan-Bersier.xlsx, Planification_TPI_Ryan-Bersier.xlsx, Schema-electronique.fzz]
2026-05-11 update of the code for show every hours a white led and update of the documentation with conception folder terminate and a part of implementation folder
    [Planification_TPI_Ryan-Bersier.xlsx]
2026-05-12 update of the Documentation, the implementation folder was terminate and same for the test part
    [Journal-de-Travail_TPI_Ryan-Bersier.xlsx, Planification_TPI_Ryan-Bersier.xlsx]
2026-05-19 update documentation with the conclusion and annex
    [Journal-de-Travail_TPI_Ryan-Bersier.xlsx, Planification_TPI_Ryan-Bersier.xlsx, Schema-electronique.fzz]
2026-05-19 update documentation with the Mr. Favre advise
    [Journal-de-Travail_TPI_Ryan-Bersier.xlsx, Planification_TPI_Ryan-Bersier-final.xlsx, Planification_TPI_Ryan-Bersier-initial.xlsx]
